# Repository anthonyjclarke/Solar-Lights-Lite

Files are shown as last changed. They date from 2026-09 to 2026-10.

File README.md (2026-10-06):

# Solar Lights Lite
















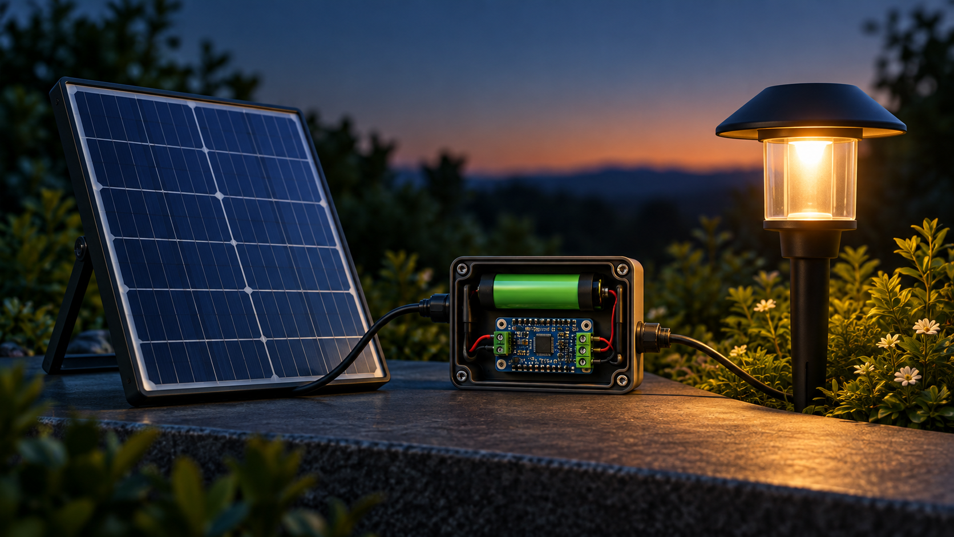
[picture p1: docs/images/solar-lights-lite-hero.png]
A solar panel, compact control electronics and warm garden light at dusk


Solar Lights Lite is a modular, low-power solar lighting system you build
yourself from common hobby modules. A small panel charges a protected Li-ion
battery; an ATmega328P controller sleeps most of the time, detects dusk with a
light sensor, and runs a **low-power LED string** from dusk to dawn. An
optional Wemos D1 Mini reports everything to Home Assistant.

It is also a learning project. Each module – power, controller, lighting,
sensor, telemetry – is built and tested on its own, so along the way you
practise soldering and SMD rework, read datasheets, program an AVR over ISP,
write low-power embedded C++, parse a serial protocol in ESPHome, and build
Home Assistant dashboards and automations.

---

## Low-power lights only

The controller drives the LED string **directly by PWM from pin D9** through a
47 Ω resistor. There is no driver transistor, so the whole string must run at
20 mA or less from a 3–4.2 V supply. Small low-power LED strings are ideal;
mains lights, 12 V garden lights and conventional or legacy fittings cannot be
used. The resistor sets the current and PWM sets the brightness. Brighter
lighting needs a driver stage: see [Going further](docs/12-going-further.md).

---

## System at a glance

```mermaid
flowchart LR
    PV[Solar panel] --> CHG[Protected Li-ion charger]
    CHG --> BAT[1S2P 18650 battery]
    CHG --> MCU[ATmega328P controller]
    MCU --> LDR[Light sensor]
    MCU -- PWM --> LED[Low-power LED string]
    MCU -. serial .-> D1[D1 Mini telemetry]
    D1 -. Wi-Fi .-> HA[Home Assistant]
```

| Module | What it does | Build guide |
| :----- | :--- | :--- |
| A | Panel, charger, fused 1S2P battery | [Power](docs/03-build-power.md) |
| B | ATmega328P controller at 8 MHz | [Controller](docs/04-build-controller.md) |
| C | Low-power LED string on D9 | [Lighting](docs/05-build-lighting.md) |
| D | Light sensor and test button | [Sensor](docs/06-build-sensor.md) |
| E | D1 Mini telemetry (optional) | [Telemetry](docs/07-build-telemetry.md) |
| F | Enclosure and final assembly | [Commissioning](docs/10-commissioning.md) |

### Telemetry tiers

| Tier | Name | Role |
| :--- | :--- | :--- |
| 0 | Standalone | Lights only, no Wi-Fi |
| 1 | Advanced Telemetry | Always-on commissioning instrument |
| 2 | Production Telemetry | Hourly battery-powered reporting |

**Advanced Telemetry is the road to a finished installation.** While you build,
calibrate and soak-test, it shows every decision the controller makes in Home
Assistant. When the system passes its acceptance gates, you reflash both boards
and move the D1 Mini to battery power for low-power production reporting. The
wiring stays the same.

---

## What you need

- The parts for each module: [parts, tools, skills and safety](docs/02-parts-and-tools.md)
  and the checklist [`docs/parts-list.csv`](docs/parts-list.csv).
- A soldering iron, a multimeter and a **current-limited bench supply**.
- A USBasp programmer (or a spare Arduino Uno/Nano as ISP).
- A computer with [PlatformIO](https://platformio.org/) and a standalone
  [avrdude](https://github.com/avrdudes/avrdude) 7.x.
- For telemetry: Home Assistant with ESPHome.

---

## Build path

The docs are organised by module; build in this order, passing each
commissioning gate before moving on:

1. Read the [design overview](docs/01-design-overview.md), including the
   known limitations.
2. Prepare the controller, set its fuses and flash the `advanced` firmware:
   [controller](docs/04-build-controller.md), [firmware](docs/08-firmware.md).
3. Add the [LED string](docs/05-build-lighting.md) and the
   [sensor and button](docs/06-build-sensor.md); pass Gates 1, 3 and 4 on a
   bench supply.
4. Build and qualify the [power module](docs/03-build-power.md): Gates 2, 5
   and 6.
5. Add [telemetry hardware](docs/07-build-telemetry.md) and set up
   [Home Assistant](docs/09-home-assistant.md) in Tier 1.
6. Assemble the enclosure and run the 14-day soak (Gate 7), then switch to
   production (Gate 8): [commissioning](docs/10-commissioning.md).
7. Live with it: [operation and maintenance](docs/11-operation.md).

For a visual review of everything on one page – every guide with its drawings
inline, plus the wire schedule and parts checklist – open
[`docs/ASSEMBLY.html`](docs/ASSEMBLY.html) in a browser (download or clone the
repository first; GitHub shows HTML as source). Printable A3 drawings for every
module are in
[`docs/drawings/SolarLights_Lite_Drawings.pdf`](docs/drawings/SolarLights_Lite_Drawings.pdf).

---

## Repository map

| Path | Contents |
| :--- | :--- |
| `docs/` | Guides 01–12 and the one-page `ASSEMBLY.html` |
| `docs/drawings/` | A3 sheets, pin map, USBasp and bench sheets |
| `docs/reference/` | Board photos, datasheet, LED characterisation |
| `firmware/controller/` | ATmega328P firmware and host tests |
| `firmware/esphome/` | D1 Mini profiles: Advanced and Production |
| `homeassistant/` | HA package and dashboards |
| `hardware/kicad/` | KiCad schematic of the complete system |
| `tools/` | Drawing and wiring-data generators |

---

## Status

Version 0.6.0 is a complete build and operate package. The reference system is
built and running with Advanced Telemetry. The remaining steps before 1.0
are: removing the regulator and power LED from the bench controller board
([guide 04, step 5](docs/04-build-controller.md#5-remove-them)), which is
deferred to the production build; the 14-day soak; charger and panel
qualification; and the Tier 2 switch-over (Gates 5–8). See [`CHANGELOG.md`](CHANGELOG.md).

This is a hobby design, not a certified product. Read the
[safety notes](docs/02-parts-and-tools.md#safety) and the
[known limitations](docs/01-design-overview.md#known-limitations) before
leaving it unattended outdoors.

---

## Why build it?

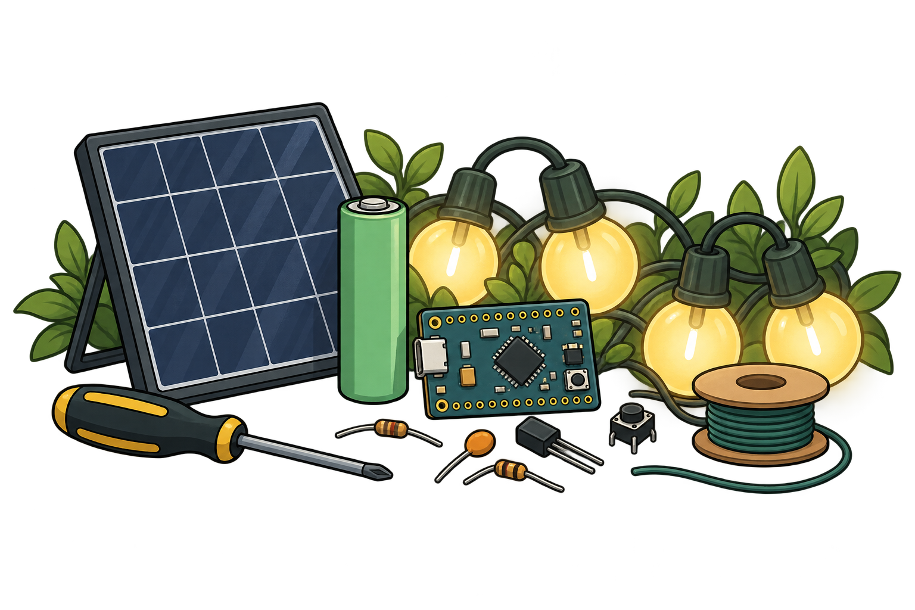
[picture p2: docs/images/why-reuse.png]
A solar panel, garden lights, battery cell, microcontroller and reused parts on a workbench.


This project started with a drawer of solar panels, light strings, charger
modules and microcontroller boards bought for projects that never quite
happened. Rather than buy another ready-made solar light, the aim was to put
those parts back to work, and to understand every part of the result: why a
charger needs its current set, why a microcontroller should run at 8 MHz on a
lithium cell, how little current a well-sleeping circuit can draw, and how to
watch it all from Home Assistant. AI assistants helped along the way as a
second opinion and a patient explainer.

Could it be cheaper, simpler, or less engineered? Almost certainly. But it is
a good excuse to learn, and good fun to build.

---

## Licence

Solar Lights Lite is dedicated to the public domain under
[CC0 1.0](LICENSE): firmware, ESPHome and Home Assistant configuration, tools,
documentation, drawings and schematics. Copy, modify, build and share it for
any purpose, without asking and without attribution.

The one exception is the third-party TPS63802 datasheet in `docs/reference/`,
which remains the property of its publisher and is included for reference.

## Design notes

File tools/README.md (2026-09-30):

# Tools

Generators for the drawings and wiring data in `docs/`. Edit the generator, then
regenerate; do not hand-edit the outputs.

| Script | Writes |
| :--- | :--- |
| `make_drawings.py` | Sheet SVGs and PNGs, A3 drawings PDF |
| `make_board_map.py` | `docs/drawings/BTE13-010A-pin-map.*` |
| `make_usbasp_sheet.py` | `docs/drawings/usbasp-wiring.*` |
| `make_bench_sheet.py`  | `docs/drawings/controller-bench-sheet.*` |
| `make_netlist.py` | `docs/netlist.json`, `docs/wire-schedule.csv` |
| `make_guide.py` | `docs/ASSEMBLY.html` from guides 01–12 |
| `make_layouts.py` | Breadboard and perfboard layout SVGs and PNGs |

`make_netlist.py` needs only the Python standard library and also checks the
wiring rules (for example that B- is never joined to OUT-). `make_layouts.py`
also needs only the standard library; it checks both layouts against
`docs/netlist.json` and writes PNGs when Inkscape is installed. `make_guide.py`
needs `markdown`; the drawing scripts need `reportlab` and `pypdfium2`. Run
`make_guide.py` last, after any drawing, CSV or guide change:

```bash
python3 -m venv .venv
.venv/bin/pip install reportlab pypdfium2 markdown
.venv/bin/python tools/make_drawings.py
.venv/bin/python tools/make_guide.py
```

The KiCad schematic has its own generator in `hardware/kicad/tools/`; see
[`hardware/kicad/README.md`](../hardware/kicad/README.md).

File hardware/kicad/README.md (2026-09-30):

# KiCad schematic

`SolarLights_Lite.kicad_sch` is the complete Solar Lights Lite circuit on one A3
sheet, drawn as six functional blocks:

1. Solar input, charger and cells
2. Battery rail (fuse and service switch)
3. LED output (direct PWM drive through R3)
4. Controller (Pro Mini)
5. Telemetry (Wemos D1 Mini and the Q2 serial receiver)
6. Telemetry 3.3 V supply (U3)

Blocks connect by net label: `VBAT`, `3V3_TEL`, `PWM`, `UART_TX`, `BTN`,
`LDR_PWR`, `LDR_SENSE`, `BATT_BUS`, `BATT-` and `D1_D6`. U0 is drawn for
Option B panels; with an Option A panel, wire PV1 straight to M1 IN. U3 OUT is
shown connected to the D1 Mini 3V3 pin, which is the Tier 2 arrangement; in
Tier 1 that link is open and the D1 Mini runs from USB.

This is a wiring schematic for module-level assembly on perfboard. It has no
footprints or layout and is not a fabrication package.

---

## Files

| File | Contents |
| :--- | :--- |
| `SolarLights_Lite.kicad_sch` | Editable schematic (KiCad 7 format or later) |
| `SolarLights_Lite.pdf` | A3 PDF export; no KiCad needed |
| `SolarLights_Lite_preview.png` | Raster preview |
| `SolarLights_Lite.kicad_sym` | Custom module symbols |
| `tools/gen_lite_sch.py` | Generator for the schematic |
| `tools/lite_parts.json` | Part and net data emitted by the generator |

---

## Checks and exports

With KiCad installed, `kicad-cli` (in the KiCad application folder, or on
`PATH` on Linux) exports and checks the sheet:

```bash
kicad-cli sch export pdf -o SolarLights_Lite.pdf SolarLights_Lite.kicad_sch
kicad-cli sch erc SolarLights_Lite.kicad_sch
```

ERC currently reports four items, none of them wiring faults: GND has no
`PWR_FLAG`; the `Q_NPN_BCE` symbol is not in KiCad 10's `Device` library; and
two `Battery_Cell` symbols differ from KiCad 10's library copies.

## Regenerating

The generator reads KiCad 7-format stock symbols (it uses `Q_NPN_BCE`, which
KiCad 10 no longer ships). Point `KICAD_LIBS` at a KiCad 7 symbol library
folder containing `Connector_Generic`, `Device`, `Switch` and `power`:

```bash
KICAD_LIBS=/path/to/kicad7-symbols python3 tools/gen_lite_sch.py
```

Then re-export the PDF and preview, and compare netlists before and after to
confirm connectivity.

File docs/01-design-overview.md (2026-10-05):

# 01 – Design overview

Solar Lights Lite is a small, modular solar lighting system. A solar panel
charges a protected lithium-ion battery. An ATmega328P controller wakes from
deep sleep every few seconds, decides whether it is dark, and drives a
low-power LED string from dusk to dawn. An optional Wemos D1 Mini reports what
the controller is doing to Home Assistant.

Every block is a separate module that you build, test and understand on its
own before joining it to the next. That makes the project a practical course in
microelectronics, soldering, low-power embedded code and home automation, as
well as a working set of garden lights.

---

## The modules

| Module | What it is | Build guide |
| :----- | :--- | :--- |
| A | Panel, charger, 1S2P battery  | [Power](03-build-power.md) |
| B | ATmega328P controller | [Controller](04-build-controller.md) |
| C | Low-power LED string on D9 | [Lighting](05-build-lighting.md) |
| D | Light sensor (LDR) and button | [Sensor](06-build-sensor.md) |
| E | D1 Mini telemetry (optional)  | [Telemetry](07-build-telemetry.md) |
| F | Enclosure and final assembly  | [Commissioning](10-commissioning.md) |

```mermaid
flowchart LR
    PV[Solar panel] --> OPT{Panel Voc}
    OPT -- Option A --> CHG[Protected 4056 charger]
    OPT -- Option B --> U0[5 V buck U0] --> CHG
    CHG --> BAT[1S2P Li-ion pack]
    CHG -- OUT+ via F2, S1 --> RAIL[VBAT_SYS rail]
    RAIL --> MCU[ATmega328P controller]
    MCU -- D7 / A1 --> LDR[Switched LDR]
    MCU -- D9 PWM + R3 --> LED[Low-power LED string]
    MCU -- D1/TX via Q2 --> D1[D1 Mini telemetry]
    RAIL -- U3 3.3 V --> D1
    D1 -. Wi-Fi .-> HA[Home Assistant]
```

The printable drawings in [`drawings/`](drawings/) show every module at
terminal level; sheet 7 is the whole system on one page.

---

## Low-power lighting only

The lights are a **low-power LED string**: the reference string drops about
2.56 V and draws roughly 10–20 mA in total. The controller drives it
**directly by PWM from pin D9** through a 47 Ω resistor (R3). There is no
MOSFET or transistor driver.

That has three consequences you should understand before choosing lights:

- **R3 and the pin set the current; PWM duty sets brightness.** Lowering the
  duty dims the string and saves energy, but it does not make an unsuitable
  string safe.
- **The ATmega328P pin is the limit.** Its working rating is 20 mA (40 mA
  absolute maximum). Mains lights, 12 V garden lights and conventional or
  legacy light fittings cannot be connected.
- **Brightness follows the battery.** With no regulator in the LED path,
  current falls as the cell discharges – about 21 mA at 4.20 V down to 11 mA
  at 3.40 V with the reference string. This is intended.

Brighter lighting is possible, but it needs a driver stage and a new energy
budget; see [12 – Going further](12-going-further.md).

---

## How the controller works

Each wake the controller:

1. Measures its own supply voltage against the internal 1.1 V bandgap.
2. Powers the LDR divider from D7 for a few milliseconds and reads A1.
3. Advances a small scheduler (`firmware/controller/include/schedule.h`).
4. Sets the D9 PWM duty and goes back to sleep.

| Situation | Behaviour |
| :--- | :--- |
| Day, lights off | Power-down sleep, wakes every 8 s |
| Dark for 300 s | Dusk confirmed, fades up at 2 % per s  |
| Night | Lights at `NIGHT_DUTY_PCT` (100 %) |
| Battery below 3.45 V | Night duty halved |
| Light for 300 s | Dawn confirmed, fades off |
| Below 3.30 V for 30 s | Cut-off: lights off, button locked out |
| Cut-off, then > 3.60 V, day | Normal operation resumes |
| D2 button pressed | 60 s test at the night level |
| Reset | 10 s self-test flash |

While the LEDs are lit, PWM needs the timer running, so the controller uses
idle sleep and wakes every second. The switched LDR draws current only while it
is being read.

---

## Telemetry tiers

The lights never depend on Wi-Fi or Home Assistant. Telemetry is a separate,
optional module used in three ways:

| Tier | Name | Purpose |
| :--- | :--- | :--- |
| 0 | Standalone | No telemetry; controller only |
| 1 | Advanced Telemetry | Always-on commissioning instrument |
| 2 | Production Telemetry | Hourly battery-powered reporting |

**Advanced Telemetry is the path to production.** While you build, calibrate
and soak-test, the D1 Mini stays awake on USB power and decodes every
diagnostic line from the controller into Home Assistant, with a dashboard built
for commissioning. When the system passes its acceptance gates you reflash both
boards and move the D1 Mini's supply from USB to the battery (U3). The wiring
does not change. See [09 – Home Assistant](09-home-assistant.md).

---

## Design decisions

- **ATmega328P at internal 8 MHz.** A 16 MHz ATmega328P is outside its rated
  operating area below about 3.8 V, which a discharging Li-ion cell reaches
  every night. At 8 MHz it is rated down to 2.7 V. The internal oscillator
  also removes any dependency on the board's crystal. The common 5 V/16 MHz
  Pro Mini is therefore fine to buy: its fuses are reset to internal 8 MHz
  ([04 – Controller](04-build-controller.md#why-the-controller-runs-at-8-mhz)).
- **No voltage regulator for the controller.** The Pro Mini runs straight from
  the protected battery rail (2.7–4.2 V is within its range), so its regulator
  and power LED are removed to eliminate their standby current.
- **Switched LDR for dusk and dawn.** Sensing panel voltage depends on charger
  loading and can back-feed an unpowered controller. A light-dependent
  resistor powered only while sampled needs no RTC, clock or network, and
  draws nothing between reads.
- **Five-minute confirmation and a threshold gap.** Car headlights, shadows
  and dusk flicker cannot toggle the lights.
- **Dusk to dawn, no clock.** Without an RTC the watchdog timer is the only
  time base, and it is uncalibrated (it varies by chip, typically 10–20 %
  slow). Dusk-to-dawn operation never needs wall-clock time.
- **Firmware cut-off plus hardware protection.** The firmware protects the
  battery from the lighting load; the charger module's DW01A protection
  remains the last line of defence for everything else.
- **Receive-only telemetry through a transistor.** Q2 inverts and level-shifts
  the controller's serial output for the 3.3 V D1 Mini, so the two boards never
  share a logic-level signal directly and the D1 Mini cannot drive the
  controller.
- **Scheduler separate from hardware.** `schedule.h` has no AVR code, so its
  behaviour is covered by host regression tests on any computer.
- **Reuse first.** Modules are chosen to be common and inexpensive, and parts
  already in a drawer are preferred where they qualify.

---

## Energy budget

These are planning figures, not measurements. Commissioning replaces them with
your own numbers ([10 – Commissioning](10-commissioning.md)). Assumptions: 14
dark hours, reference LED string at about 15 mA, Tier 2 telemetry.

| Load | 100 % duty | 50 % duty |
| :--- | ---: | ---: |
| LED string, 15 mA × 14 h | 210 mAh | 105 mAh |
| Controller, 1 mA lit + 10 µA for 10 h | 14 mAh | 14 mAh |
| Controller status line, ~40 µA × 24 h | 1 mAh | 1 mAh |
| D1 Mini wakes, 24 × 20 s × 80 mA | 11 mAh | 11 mAh |
| U3 and D1 Mini sleep, 0.2 mA × 24 h | 5 mAh | 5 mAh |
| Other standby allowance | 1 mAh | 1 mAh |
| **Total per day** | **~242 mAh** | **~137 mAh** |

On the harvest side, a TP4056-family linear charger set to 100 mA and an
assumed 2.5 equivalent full-sun hours with 20 % derating gives about
200 mAh/day; at 150 mA, about 300 mAh/day. Winter, shade and panel angle
change this dramatically. Two practical conclusions:

- Full brightness all night is marginal with a 1.2 W panel in winter. If the
  soak test shows the battery ending each night lower than the last, reduce
  `NIGHT_DUTY_PCT` or fit a larger panel.
- A bigger battery buys autonomy through cloudy spells; it cannot fix a
  persistent daily deficit.

---

## Known limitations

Read these before relying on the system unattended outdoors.

- **No cell-temperature charge inhibit.** TP4056-family modules usually have
  their TEMP input disabled. Li-ion cells must not be charged below 0 °C. In a
  climate where the enclosure can freeze, add temperature protection before
  unattended use (see [Going further](12-going-further.md)).
- **Not a power-path charger.** The load draws from the battery while it is
  charging, which can delay or confuse charge termination. Commissioning Gate 5
  checks termination with the load connected.
- **Firmware cut-off only switches the LEDs off.** The controller, U3 and the
  D1 Mini keep drawing a small current until the pack protection trips.
- **Battery percentage is an estimate** from resting voltage, not coulomb
  counting.
- **No wall-clock time.** The watchdog clock drifts; features that need real
  time (for example "off at 22:30") need an RTC or network time.
- **PWM at ~1.96 kHz** may band on some cameras.
- **A short on the LED cable is bounded, not protected.** R3 plus the pin's
  resistance limit it to roughly 55 mA, which is above the pin's absolute
  maximum. Fit R3 at the controller end so the outdoor cable is always behind
  it.
- **Telemetry reports controller state, not energy.** It does not measure
  panel voltage, charge or load current, or temperature.

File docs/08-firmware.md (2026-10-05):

# 08 – Controller firmware: build, fuses, flash and diagnostics

The controller firmware is in [`firmware/controller/`](../firmware/controller/).
It is built with PlatformIO and flashed over ISP with a standalone copy of
`avrdude`. The board has no bootloader, so there is no USB upload.

**What you will learn:** AVR fuses and ISP programming, PlatformIO build
environments, low-power AVR techniques (power-down sleep, watchdog wake,
pin-change interrupts, bandgap voltage measurement, hardware PWM), and testing
embedded logic on a desktop computer.

---

## Source layout

| File | Purpose |
| :--- | :--- |
| `include/config.h` | Every tuneable value: pins, levels, timing |
| `include/schedule.h` | Hardware-free dusk-to-dawn scheduler |
| `src/main.cpp` | AVR layer: ADC, PWM, sleep, telemetry |
| `test_host/regression.cpp` | Scheduler tests that run on a computer |
| `platformio.ini` | One build environment per telemetry tier |

---

## Build environments

| Environment  | Telemetry output | Use with |
| :--- | :--- | :--- |
| `advanced` | Banner, field guide, diagnostics | Tier 1, bench |
| `production` | Banner, then a compact line ~8 s | Tier 2 |
| `standalone` | None; serial port powered down | Tier 0 |

All three run identical lighting logic. Commission with `advanced`; deploy
with `production` (or `standalone` if you have no telemetry).

---

## Why ISP, not a USB-serial upload

An off-the-shelf Pro Mini is normally programmed through a USB-serial (FTDI)
adapter and the Arduino bootloader. This build uses an ISP programmer (USBasp,
or an Uno or Nano acting as one) instead, for these reasons.

**ISP is needed at least once anyway.** Switching the clock to the internal
8 MHz oscillator means rewriting the fuses
([why 8 MHz](04-build-controller.md#why-the-controller-runs-at-8-mhz)). A
bootloader cannot change fuses: only an ISP programmer (or a high-voltage
programmer) can. There is no way to prepare a new board with an FTDI adapter
alone.

**The factory bootloader stops working after the fuse change.** A 16 MHz Pro
Mini's bootloader is built for its 16 MHz crystal. Once the chip runs at
8 MHz, the bootloader runs at half speed and talks at the wrong baud rate, so
uploads fail. Serial uploads would need a new 8 MHz bootloader, and that also
has to be written over ISP.

**With the programmer already wired, ISP is the simpler route for updates.**
One tool and one command cover fuses, firmware and verification, and the chip
has nothing extra installed:

- **The firmware starts straight away.** With no bootloader there is no
  start-up pause listening for an upload after a reset.
- **The full 32 KB of flash is available,** and the high fuse `0xD9` jumps
  straight to the firmware at reset.
- **No auto-reset wiring is needed.** Serial uploads need the adapter's DTR
  line connected to RST through a 100 nF capacitor. This build has no DTR
  connection, and D1/TX is already used by the telemetry link (module E).
- **There is less risk of back-feeding the battery.** A USB-serial adapter's
  VCC pin must never be connected while the battery powers the controller.
  For flashing, the programmer is the only power source, with the battery and
  everything else disconnected.

**An FTDI adapter is still useful** as a receive-only serial monitor (see
[Reading the diagnostics](#reading-the-diagnostics)): connect controller TX to
adapter RX, and GND to GND, only.

**Serial uploads are possible, but not supported.** If you want to use them,
use ISP to write an 8 MHz internal-oscillator bootloader and the high fuse it
requires, then add the DTR reset circuit. The project's instructions,
troubleshooting and fuse values all assume no bootloader, so you would be on
your own.

---

## Install the tools

1. **PlatformIO.** Install the PlatformIO extension for VS Code, or PlatformIO
   Core ([installation guide](https://docs.platformio.org/en/latest/core/installation/)).
   Check `pio --version` in the PlatformIO terminal.
2. **avrdude, version 7 or later, installed separately.** PlatformIO bundles an
   older avrdude that is not reliable with this setup, so do not use
   `pio run -t upload`.
   - macOS: `brew install avrdude`
   - Linux: your distribution's `avrdude` package, if it is version 7 or later;
     otherwise build or download it from the
     [AVRDUDE project](https://github.com/avrdudes/avrdude/releases).
   - Windows: download the release from the
     [AVRDUDE project](https://github.com/avrdudes/avrdude/releases), extract
     the whole folder (including `avrdude.conf`) and add it to `PATH`. A USBasp
     also needs a libusb driver (for example installed with Zadig).
3. Check `avrdude --version` in the same terminal you will flash from.

---

## Wire the programmer

Disconnect the battery, panel, LED string, telemetry and any USB-UART adapter
first. The controller must have exactly one power source: the programmer.

| USBasp 10-pin | Signal | Pro Mini |
| :--- | :----- | :--- |
| 1 | MOSI | 11 |
| 2 | VCC | VCC |
| 5 | RESET  | RST |
| 7 | SCK | 13 |
| 9 | MISO | 12 |
| 4, 6, 8 or 10 | GND | GND |

Set the USBasp to **3.3 V** and confirm with a meter: some clones switch target
power but not logic level. Printable sheets: [USBasp wiring](drawings/usbasp-wiring.pdf)
and the [board map](drawings/BTE13-010A-pin-map.pdf).

---

## One-time preparation of a new board

Run these from any folder. None of them are needed again for routine updates.

**1. Read the signature** (writes nothing):

```bash
avrdude -c usbasp -p m328p -v
```

The signature tells you which chip is on the board, and that decides the
`-p` part name for **every** avrdude command that follows:

| Signature  | Chip | Use in every command  |
| :--- | :--- | :--- |
| `1E 95 0F` | ATmega328P  | `-p m328p` (as shown) |
| `1E 95 16` | ATmega328PB | `-p m328pb` |

Stop if it reads anything else, or all `00` or all `ff` (see
[Troubleshooting](#troubleshooting)).

Many recent Pro Mini clones, including some sold as "ATmega328P", carry the
newer **ATmega328PB**. With `-p m328p`, avrdude reports
`Device signature = 1E 95 16 (ATmega328PB)` and refuses to continue. This
does not mean the board is faulty. Repeat the command with `-p m328pb`, and
use that in every later command. Do not use `-F` to force past the check:
it switches off avrdude's check that it is talking to the chip you expect,
for this command and any you copy it into.

The 328PB is designed as a drop-in replacement for the 328P and runs the same
firmware. The PlatformIO build (board `pro8MHzatmega328`) is unchanged, and so
are the fuse values below. The 328PB's extra peripherals and its extra
clock-failure fuse bit stay unused: the extended fuse `0xFD` leaves that bit
unprogrammed, so the feature is off.

**2. Save the existing fuses**, in case you ever want the board back as it
was. A new 16 MHz Pro Mini normally reads low `0xFF`, high `0xDA`, extended
`0xFD`; write down what yours shows.

```bash
avrdude -c usbasp -p m328p -U lfuse:r:-:h -U hfuse:r:-:h -U efuse:r:-:h
```

**3. Write the Solar Lights fuses:**

```bash
avrdude -c usbasp -p m328p -U lfuse:w:0xE2:m -U hfuse:w:0xD9:m -U efuse:w:0xFD:m
```

| Fuse | Value  | Effect |
| :--- | :----- | :--- |
| Low | `0xE2` | Internal 8 MHz RC oscillator, no clock ÷8 |
| High | `0xD9` | Start at address 0 (no bootloader), ISP kept |
| Extended | `0xFD` | Brown-out reset at 2.7 V |

Fuses are persistent configuration bits, separate from the program. Type the
values carefully: a wrong clock-source value can leave the chip needing an
external clock or a high-voltage programmer to recover. Some avrdude versions
show the extended fuse as `0x05`; that is the same setting with the unused
bits hidden.

The first firmware flash erases the chip, which also removes any Arduino
bootloader. The board will no longer accept serial uploads; that is expected.

---

## Build and flash

From `firmware/controller`:

```bash
pio run -e advanced
```

The build must end in `SUCCESS` and produce `.pio/build/advanced/firmware.hex`.
Then flash it:

```bash
avrdude -c usbasp -p m328p -v -U flash:w:.pio/build/advanced/firmware.hex:i
```

(On an ATmega328PB, `-p m328pb`.) Success needs both the write and the verify to pass. Unplug the programmer and
remove all six ISP wires before reconnecting normal power. Next, do the first
power-up check ([04 – Controller, step 3](04-build-controller.md#3-first-power-up-check)).

For deployment, build and flash `production` (or `standalone`) the same way,
replacing `advanced` in both commands. Routine updates never write fuses.

### Arduino as ISP (fallback)

If you have no USBasp, an Uno or Nano can act as the programmer:

1. Upload the `ArduinoISP` example sketch to it.
2. Fit a 10 µF capacitor from its RESET to GND (stops it auto-resetting).
3. Wire programmer D11 → target 11, D12 → 12, D13 → 13, D10 → target RST,
   plus VCC and GND. A 5 V Uno drives 5 V logic, so power the target from the
   Uno's 5 V pin: that is within the ATmega328P's rating **only while the
   controller is isolated** from the battery rail, LDR, LED string and D1 Mini.
4. Replace `-c usbasp` with `-c stk500v1 -P <port> -b 19200` in every command,
   for example `-P /dev/ttyACM0`, `-P /dev/cu.usbmodem1101` or `-P COM5`. Do
   not add `-B`; the stock sketch ignores it.

---

## Reading the diagnostics

At every reset, the `advanced` and `production` builds print a banner with
the firmware version, the date and time it was built, the telemetry profile
and the clock setting. Check it after flashing: it confirms the board is
running the build you just made.

```text
==================================================
 Solar Lights Lite  -  dusk-to-dawn controller
 Firmware   v0.6.0   built 05-Oct-2026 13:26
 Telemetry  advanced: full diagnostics, 9600 baud
 Clock      internal 8 MHz, brown-out 2.7 V
==================================================
```

The `advanced` build then lists its active settings (LDR thresholds, battery
levels, night duty) and a field guide to the line keys, ending with
`Live diagnostics`. After that it prints a line whenever something changes,
every 10 s while a transition, test or cut-off is being timed, and every 60 s
otherwise. The `production` build prints a shorter line every 8 scheduler
seconds. None of the reset text starts with `fw=`, so the ESPHome profiles
ignore it. The build date comes from the compiler, so it changes every time
you build.

Two ways to read it:

- **Tier 1 Advanced Telemetry** (recommended): the D1 Mini decodes every line
  into Home Assistant ([09 – Home Assistant](09-home-assistant.md)).
- **A 3.3 V USB-UART adapter**: connect only controller TX → adapter RX and
  GND → adapter GND; leave the adapter's VCC, TX, DTR and CTS open (sheet 5).
  Then run `pio device monitor --baud 9600` from `firmware/controller`.

The one exception is the first power-up check straight after flashing
([04 – Controller, step 3](04-build-controller.md#3-first-power-up-check)).
There, the adapter's 3.3 V VCC powers the bare board through the serial
header, with the programmer and everything else disconnected. Never use the
adapter's 5 V setting, and never connect its VCC while any other source
powers the controller.

### Line format

Every line is space-separated `key=value` pairs starting with `fw=`. Both
ESPHome profiles parse these keys; if you rename one, update both YAML files.

| Key | Example | Meaning |
| :--- | :--- | :--- |
| `fw` | `0.6.0` | Firmware version (`config.h`) |
| `time` | `1234s` | Scheduler seconds since reset |
| `vdd` | `3.912V` | Controller supply (= battery rail) |
| `battery` | `OK` | Band: OK, MID, LOW, CRITICAL |
| `ldr` | `12.4%` | A1 as a percentage of VCC |
| `sense` | `DARK` | DARK, MID or LIGHT |
| `mode` | `NIGHT` | DAY, NIGHT or LVC (cut-off) |
| `night` | `YES` | Dusk confirmed, dawn not yet |
| `output` | `100%` | D9 PWM duty |
| `cause` | `DUSK_TO_DAWN` | Why the output has its value |
| `raw` | `127` | A1 ADC count (advanced only) |
| `ldr_v` | `0.485V` | A1 volts (advanced only) |
| `confirm` | `DUSK 40/300s` | Transition progress (advanced only) |
| `lvc` | `0/30s` | Time below cut-off (advanced only) |
| `button` | `59s` | Test time left (advanced only) |
| `next_tick` | `1s` | Next watchdog interval (advanced only) |

| `cause` | Meaning |
| :--- | :--- |
| `STARTUP_TEST` | 10 s flash after reset |
| `BUTTON_TEST` | 60 s test after a D2 press |
| `DAY_OFF` | Daylight, lights off |
| `FADE_TO_DAY_OFF` | Dawn confirmed, fading out |
| `DUSK_TO_DAWN` | Night, full night level |
| `LOW_BATT_NIGHT`  | Night, below 3.45 V: level halved  |
| `LOW_VOLT_BLOCK`  | Test refused: supply below cut-off |
| `LVC_OFF` | Low-voltage cut-off active |

---

## Tuning and calibration

All settings are in `include/config.h`. The ones you are most likely to change:

| Setting | Default | Effect |
| :--- | :--- | :--- |
| `NIGHT_DUTY_PCT`  | 100 | Night brightness and energy use |
| `LDR_DARK_RATIO`  | 0.30 | Dusk threshold (A1 fraction) |
| `LDR_LIGHT_RATIO` | 0.60 | Dawn threshold (A1 fraction) |
| `LOW_BATT_V` | 3.45 | Below this, night level halves |
| `LVC_OFF_V` | 3.30 | Cut-off voltage (after 30 s) |
| `LVC_RESUME_V` | 3.60 | Recovery voltage (in daylight) |
| `BANDGAP_V` | 1.10 | Supply measurement calibration |
| `TIME_SCALE` | 1 | Bench only: 60 runs time 60× faster |

**Calibrate the supply reading** once per board, in Gate 1: power the
controller from a bench supply at about 3.8 V, compare `vdd` with a meter, set
`BANDGAP_V = 1.10 × Vmeter / Vreported`, then rebuild and reflash. The
thresholds above all depend on this reading.

---

## Host tests

The scheduler has no hardware dependencies, so its behaviour is tested on any
computer with a C++17 compiler. From `firmware/controller/test_host`:

```bash
c++ -std=c++17 -Wall -Wextra -Werror -I../include regression.cpp -o regression && ./regression
```

It must print `PASS`. The tests cover dusk/dawn confirmation, a 14-hour night,
test-level caps, cut-off and recovery, low-battery dimming, slow ticks and the
shipped defaults. They do not test registers, ADC settling, sleep current or
wiring: that is what commissioning is for.

---

## Troubleshooting

| Symptom | Meaning / action |
| :--- | :--- |
| `pio: command not found` | Use the PlatformIO terminal |
| `Bad CPU type` on an Apple-silicon Mac | AVR toolchain needs Rosetta 2 |
| avrdude path contains `.platformio` | Wrong avrdude: use the standalone one |
| `cannot set sck period` | Old USBasp firmware: fit slow-SCK jumper |
| `target does not answer` | Pin 1, MOSI/MISO, RST, VCC, slow SCK |
| Signature `1E 95 16 (ATmega328PB)` | 328PB chip: use `-p m328pb`, not `-F` |
| Any other signature | Wrong chip or wiring: stop |
| `vdd=` about 5 V on the bench | Fed from a 5 V pin or jumper: use 3.3 V  |
| Verification mismatch | Check avrdude version, retry once |
| Serial text unreadable | Fuses not set (still 16 MHz) |
| No serial output at all | `standalone` build, or TX/GND wiring |

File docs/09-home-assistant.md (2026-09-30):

# 09 – Home Assistant and ESPHome telemetry

**Files:** [`firmware/esphome/`](../firmware/esphome/) (D1 Mini profiles) and
[`homeassistant/`](../homeassistant/) (package and dashboards).
**Hardware:** [07 – Module E: telemetry hardware](07-build-telemetry.md).

The lights run without any of this. Telemetry lets you watch the controller
work, calibrate it, prove it over a two-week soak, and then keep an eye on it in
service.

**What you will learn:** ESPHome configuration and secrets, parsing a serial
protocol in an ESPHome lambda, deep sleep with an OTA escape hatch, Home
Assistant packages, helpers, automations and sections dashboards.

---

## The tiers

| Tier | Controller build | ESPHome profile | D1 Mini power |
| :--- | :--- | :--- | :--- |
| 0 | `standalone` | None | – |
| 1 | `advanced` | `solar-lights-advanced-telemetry.yaml` | Micro-USB |
| 2 | `production` | `solar-lights-production-telemetry.yaml` | U3 (battery)  |

**Tier 1 – Advanced Telemetry** is the commissioning instrument. The D1 Mini
stays awake and publishes every field of every diagnostic line, plus its own
Wi-Fi, heap and uptime. It keeps receiving if Wi-Fi or Home Assistant go down,
and serves its own web page at `http://<D1 IP address>/`. It draws around
70–80 mA continuously, which is why it runs from USB and is never part of the
battery budget.

**Tier 2 – Production Telemetry** is for the finished installation. Once an hour
the D1 Mini wakes, waits up to 20 s for a status line from the controller,
reads the battery voltage, reports, and goes back to deep sleep. Its average
draw is well under 1 mA.

Both profiles use the **same device name (`solar-lights`), entity names and
encryption key**, so moving from Tier 1 to Tier 2 keeps your Home Assistant
history and the same entity IDs.

---

## 1. Install ESPHome

Use either the **ESPHome Device Builder** add-on in Home Assistant
(Settings → Add-ons) or the ESPHome command-line tool. The profiles need
ESPHome 2024.11 or later.

## 2. Add the secrets

In the ESPHome `secrets.yaml` (never in this repository):

| Key | Used for |
| :--- | :--- |
| `wifi_ssid` | Your Wi-Fi network |
| `wifi_password` | Your Wi-Fi password |
| `esphome_encryption_key` | API key (ESPHome can generate one) |
| `ota_password` | Over-the-air update password |
| `ap_password` | Tier 1 fallback hotspot (8+ characters) |

## 3. Flash the D1 Mini (Tier 1)

1. Remove the D0 → RST link while flashing over USB.
2. In the ESPHome dashboard create a device, then replace its YAML with
   `solar-lights-advanced-telemetry.yaml`. Keep `name: solar-lights`: the
   dashboards' entity IDs depend on it.
3. **Validate**, then **Install** over USB the first time. Later updates can go
   over Wi-Fi.
4. Adopt the device in Home Assistant (Settings → Devices & services).
5. Flash the controller with the `advanced` build
   ([08 – Firmware](08-firmware.md)).

Within about a minute, **Arduino Diagnostics Fresh** turns on and
**Arduino Diagnostic Line** shows a complete line starting `fw=`.

## 4. Install the Home Assistant package

[`homeassistant/solar_lights_package.yaml`](../homeassistant/solar_lights_package.yaml)
adds:

- `input_boolean.solar_lights_ota`, the helper Tier 2 uses to stay awake for
  updates;
- three example automations: battery low, low-voltage cut-off, and reports
  stopped. They use persistent notifications, so they work without a phone
  app.

Enable packages once in `configuration.yaml`:

```yaml
homeassistant:
  packages: !include_dir_named packages
```

Copy the file to `/config/packages/`, check the configuration
(Developer tools → YAML) and restart Home Assistant.

## 5. Import a dashboard

Create a dashboard (Settings → Dashboards → Add dashboard), open it, choose
**Edit dashboard → Raw configuration editor**, and paste one of:

| Dashboard | Use |
| :--- | :--- |
| `dashboard-advanced-telemetry.yaml` | Tier 1: commissioning and soak test |
| `dashboard-production-telemetry.yaml` | Tier 2: day-to-day and 7-day trends |

Both use built-in cards only. If Home Assistant assigned different entity IDs,
find-and-replace `solar_lights_` before saving.

---

## Moving from Tier 1 to Tier 2

Do this only after the soak test (Gate 7) has passed.

1. Flash the controller with the `production` build.
2. With the D1 Mini still on USB, install
   `solar-lights-production-telemetry.yaml` over Wi-Fi.
3. Unplug USB. Close the U3 OUT → 3V3 jumper. Fit the D0 → RST link.
4. Watch for the first hourly report; then complete Gate 8.

To go back to Tier 1 (for example to recalibrate), reverse the steps: open the
U3 jumper **before** plugging in USB.

### Updating a sleeping D1 Mini (Tier 2)

Turn on **Solar Lights stay awake for OTA** (`input_boolean.solar_lights_ota`).
At its next wake the D1 Mini stays awake; install the update, then turn the
helper off and it resumes its hourly sleep. To reach it sooner, press its reset
button.

---

## Entities

| Entity (name in ESPHome) | Tier 1 | Tier 2 | Notes |
| :--- | :----: | :----: | :--- |
| Battery Voltage / Battery Level | ✓ | ✓ | D1 Mini A0, calibrated |
| Arduino VDD | ✓ | ✓ | Controller's own reading |
| Arduino Mode / Night / Output Cause | ✓ | ✓ | Scheduler state |
| Arduino Light Duty / Lights Commanded | ✓ | ✓ | D9 PWM duty |
| Arduino LDR / Light Sense | ✓ | ✓ | Light sensor |
| Arduino Battery Band / Firmware | ✓ | ✓ | |
| Arduino Diagnostic Line | ✓ | ✓ | Latest raw line |
| Arduino Diagnostics Fresh | ✓ | ✓ | Tier 2: line this wake |
| Arduino LDR Raw / LDR Voltage | ✓ | | Advanced detail |
| Arduino Transition Confirmation | ✓ | | Dusk/dawn progress |
| Arduino LVC Elapsed / Button Test | ✓ | | Timers |
| D1 WiFi Signal | ✓ | ✓ | |
| D1 Status, IP, SSID, uptime, heap | ✓ | | Receiver health |

Telemetry reports what the controller measures and decides. It does not
measure panel voltage, charge or load current, energy or temperature; use a
meter or power profiler for those.

---

## Calibrating the battery reading

In Gate 7, compare **Battery Voltage** with a meter across VBAT_SYS and GND at a
few battery levels. Set the multiplier in both profiles:

```
new multiplier = old multiplier × meter volts / reported volts
```

The nominal value is 5.4 (R5 220 kΩ plus the D1 Mini's 220 kΩ/100 kΩ divider);
the reference build calibrated to 5.21. **Arduino VDD** is a useful
cross-check, since it measures the same rail independently.

---

## Troubleshooting

| Symptom | Check |
| :--- | :--- |
| Diagnostics Fresh stays off | Controller build, Q2 wiring, grounds |
| `Dropped corrupted UART line` warnings | Q2 pin order, shared GND_LOAD |
| Home Assistant asks for the key again  | Encryption key changed between profiles |
| Tier 2 device never reports | D0 → RST link, U3 jumper, Wi-Fi reach |
| Tier 2 stays awake | OTA helper still on |
| Entities `unavailable` in Tier 1 | D1 Mini USB power or Wi-Fi |

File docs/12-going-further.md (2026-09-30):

# 12 – Going further

Solar Lights Lite is deliberately small. These are the natural next steps,
each a project in its own right. None of them is needed for the design as
documented, and each changes the energy budget and the commissioning work.

---

## Brighter lights: add a driver stage

The controller pin can supply about 20 mA. For a brighter string, D9 must drive
a switch that carries the LED current:

- **Logic-level MOSFET** with its on-resistance *specified at 2.5 V gate
  drive* (for example AO3400A on a breakout). "Logic level" on its own is not
  enough: at 3.0–3.3 V many such parts, including the 2N7000, are only partly
  on at LED currents.
- **NPN transistor** such as a BC337, with a base resistor sized for forced
  saturation (base current about a tenth of collector current).

A driver stage also needs a gate or base resistor, a pull-down so the lights
stay off at reset, a current-limiting resistor per LED branch, and a fuse in
the LED branch, because the string is then fed from the battery rail rather
than through the pin. Re-run the energy budget: a 200 mA string for 14 hours
needs 2,800 mAh a night, far beyond a 1–2 W panel.

---

## Better charging

- **Cell-temperature protection.** Add a thermistor on the cells and a
  charger (or cut-off circuit) that stops charging below 0 °C and above about
  45 °C. This is the main requirement for unattended use in cold climates.
- **Power-path charging.** Chargers such as the TI BQ24074 or Microchip
  MCP73871 supply the load and charge the battery separately, and regulate the
  input to suit a solar panel. They are not pin-compatible with TP4056 modules
  and come in small packages, so they suit a custom PCB.

## Measuring energy

The telemetry reports controller state, not energy. An INA219 or INA226
current monitor on the battery lead (read by the D1 Mini over I²C) would add
charge current, load current and daily mAh in and out – turning the soak test
into a true energy balance.

## Time-based schedules

The dusk-to-dawn design deliberately avoids clocks. An "evening and pre-dawn
only" schedule would need real time: a DS3231 RTC on the controller, or a time
sync from the D1 Mini. Watch the added standby current.

## A carrier PCB

Once your modules are fixed, a two-layer carrier board can replace perfboard:
sockets for the Pro Mini and D1 Mini, screw terminals, fuse holders, labelled
rails, test points and footprints for the Q2 interface. Keep the ESP8266
antenna at the board edge, and keep LED return current away from the LDR and
ADC ground. The KiCad schematic in [`hardware/kicad/`](../hardware/kicad/) is
the starting point; it needs footprints and a layout.

## Lower-power telemetry

An ESP32-C3 or similar module has a much lower deep-sleep current than an
ESP8266 D1 Mini and can run directly from a 3.3 V buck-boost. The serial
protocol and Home Assistant side would stay the same.

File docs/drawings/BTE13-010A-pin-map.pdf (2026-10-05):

SOLAR LIGHTS LITE / REFERENCE BOARD

# BTE13-010A: connection and programming map

Component side: serial header LEFT, crystal and reset button RIGHT (photos in docs/reference/).

Read the actual silkscreen before soldering. Diagram is not a footprint or regulator-removal template.

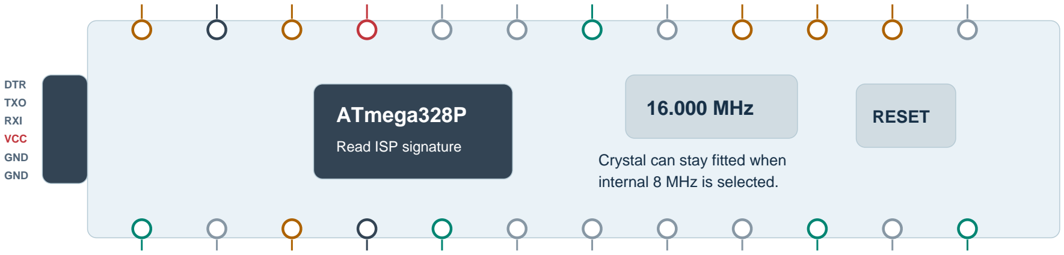
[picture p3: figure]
DTR TXO RXI VCC GND GND; ATmega328P; Read ISP signature; 16.000 MHz; Crystal can stay fitted when internal 8 MHz is selected.; RESET

### Serial header

Not the ISP connector
Its VCC = top-row VCC (same rail)
RAW | GND | RST | VCC | A3 | A2 | A1 | A0 | 13 | 12 | 11 | 10
TX | RX | RST | GND | 2 | 3 | 4 | 5 | 6 | 7 | 8 | 9

### OPERATING CONNECTIONS

Power goes into VCC (top row or header); RAW = never
VCC = protected battery; GND = OUT-; A1 = LDR sense; 7 = LDR power 9 = LED PWM; TX = telemetry to Q2; 2 = test button to GND
Regulator / power LED removed only after trace identification.

ISP CONNECTIONS / BOARD DISCONNECTED FROM BUILD

MOSI -> 11 MISO -> 12 SCK -> 13 RESET -> RST
Also connect target VCC and GND; use compatible voltage.
Set fuses once: L 0xE2, H 0xD9, E 0xFD (8 MHz internal).
A USB-to-serial adapter alone cannot perform this conversion.

REV 0.6 / BTE13-010A reference board. Other Pro Mini clones differ: follow your own silkscreen. A4-A7 end pads not shown.

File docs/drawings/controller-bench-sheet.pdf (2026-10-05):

SOLAR LIGHTS LITE / PRINTABLE SHEET

# Controller bench sheet

Flash the advanced build, prove the controller, then measure the LED string. Gate 1 of docs/10-commissioning.md.

Before you start
No cells connected for any of this. Use a current-limited bench supply, 200 mA limit, for VCC.
Step 2 needs the regulator and power LED removed (Gate 0) and the bench supply as the only power source.
Do not connect the panel or the charger. R3 sits at the board end, not out at the string.
Duty does not limit current: only R3 and the pin do. Verify at 4.20 V and 100% duty.

### 1 Flash the advanced build

Fuses are set once per board (internal 8 MHz, BOD 2.7 V, no bootloader). Routine flashing never writes them. Disconnect cells, panel, UART and LED string. Power from one verified target-compatible ISP source only.
Action | Command / pass result
Open firmware folder | cd firmware/controller
Check the target | avrdude -c usbasp -p m328p -v -> signature 1E 95 0F
1E 95 16 = ATmega328PB: use -p m328pb, never -F
Compile advanced build | pio run -e advanced -> SUCCESS
Upload and verify | standalone current avrdude; never pio -t upload
First power-up check | USB-UART at 3.3 V into serial-header VCC -> banner; vdd within 0.05 V of meter
Disconnect all ISP wires first. Then remove the regulator and power LED (guide 04 step 5) and repeat the check. After that, USB-UART is monitoring-only: target TX -> adapter RX, GND -> GND; adapter VCC, TX, DTR, CTS open. Tool setup, fuses, Arduino-as-ISP fallback and troubleshooting: docs/08-firmware.md

### 2 Check the controller on a current-limited bench supply

Read the diagnostics through Tier 1 telemetry or a USB-UART adapter (RX and GND only) at 9600 baud.
Check | | | Expect
Startup after reset | Banner with version and build date, field guide, then diagnostics
VCC at 3.80 V | vdd within 0.05 V of the meter (config.h BANDGAP_V = 1.10 x Vmeter / Vreported)
D9 PWM frequency | 1.9 to 2.0 kHz, confirming the 8 MHz clock
Pull D2 to GND | cause=BUTTON_TEST, output=100%, button timer counts down
Cover / uncover LDR | DUSK / DAWN confirmation reaches 300 s before mode changes

### 3 LED string current with R3 = 47 ohm

Meter in series with the string positive, lights at 100% duty (press D2 or cover the LDR). Expect = model:
Supply | Expect | Measured | R3 temp | Notes
3.40 V | 11 mA | __________ | ________ | ________________________
3.70 V | 15 mA | __________ | ________ | ________________________
4.20 V | 21 mA | __________ | ________ | ________________________

Decision rule
Over 22 mA at 4.20 V: fit 56 ohm and repeat the three readings (expect about 18 / 13 / 9 mA). Too bright or want longer run time: lower NIGHT_DUTY_PCT in config.h. Too dim: this design is at its limit; a brighter string needs a driver stage (docs/12-going-further.md).

Also confirm: R3 and the D9 pin stay at ambient; the string is dark with M2 unplugged and during reset. For deployment, build pio run -e production (or standalone) and flash its .hex the same way.

REV 0.6 | NO CELLS, PANEL OR CHARGER CONNECTED FOR THESE STEPS | make_bench_sheet.py

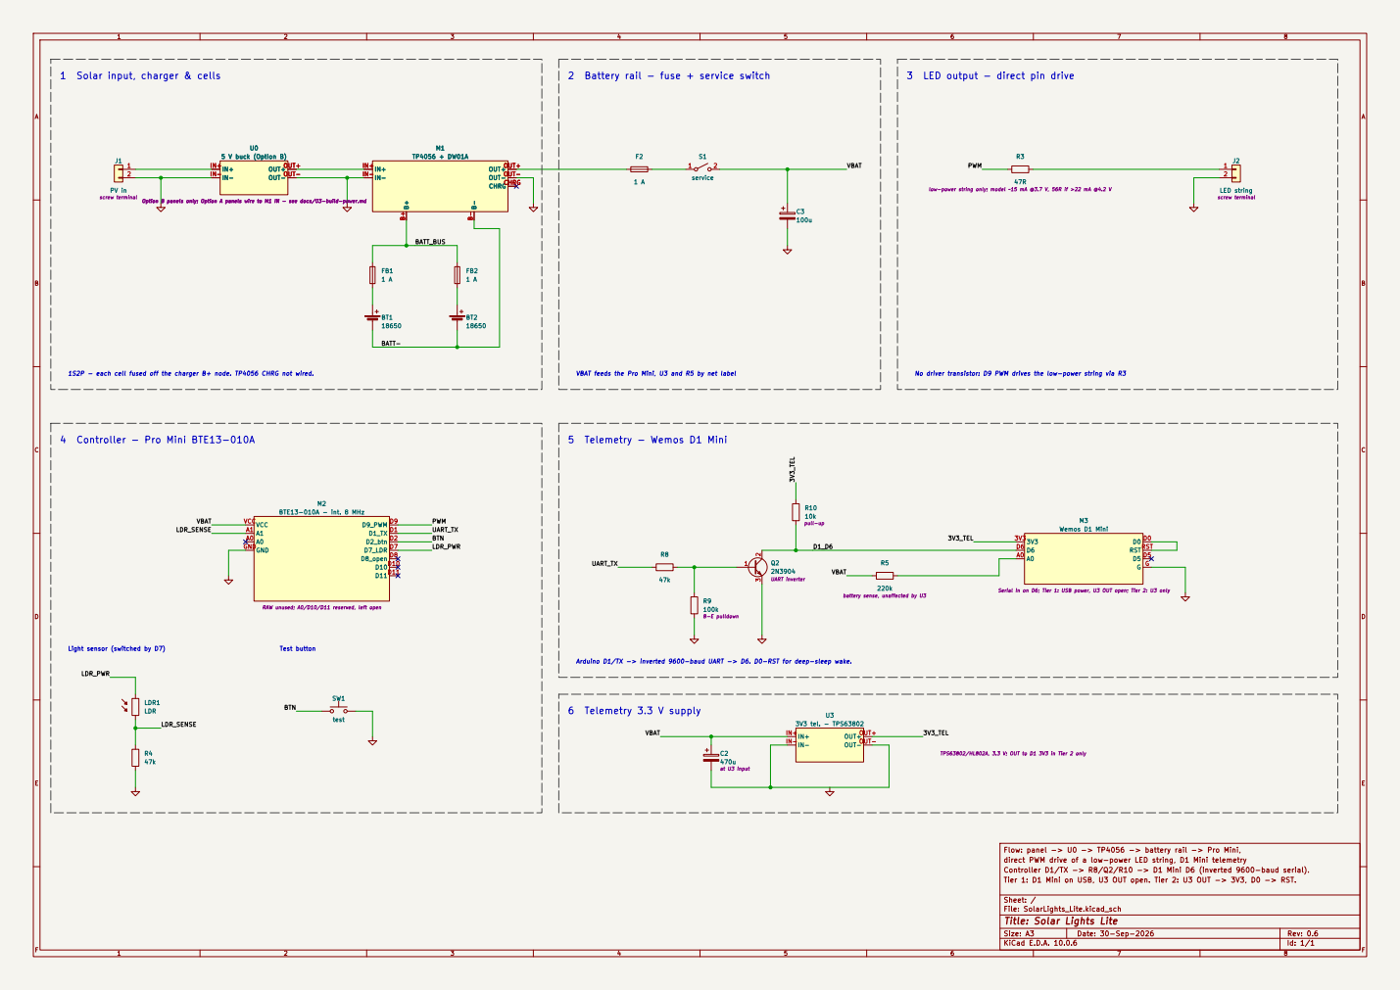
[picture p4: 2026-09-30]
hardware/kicad/SolarLights_Lite_preview.png

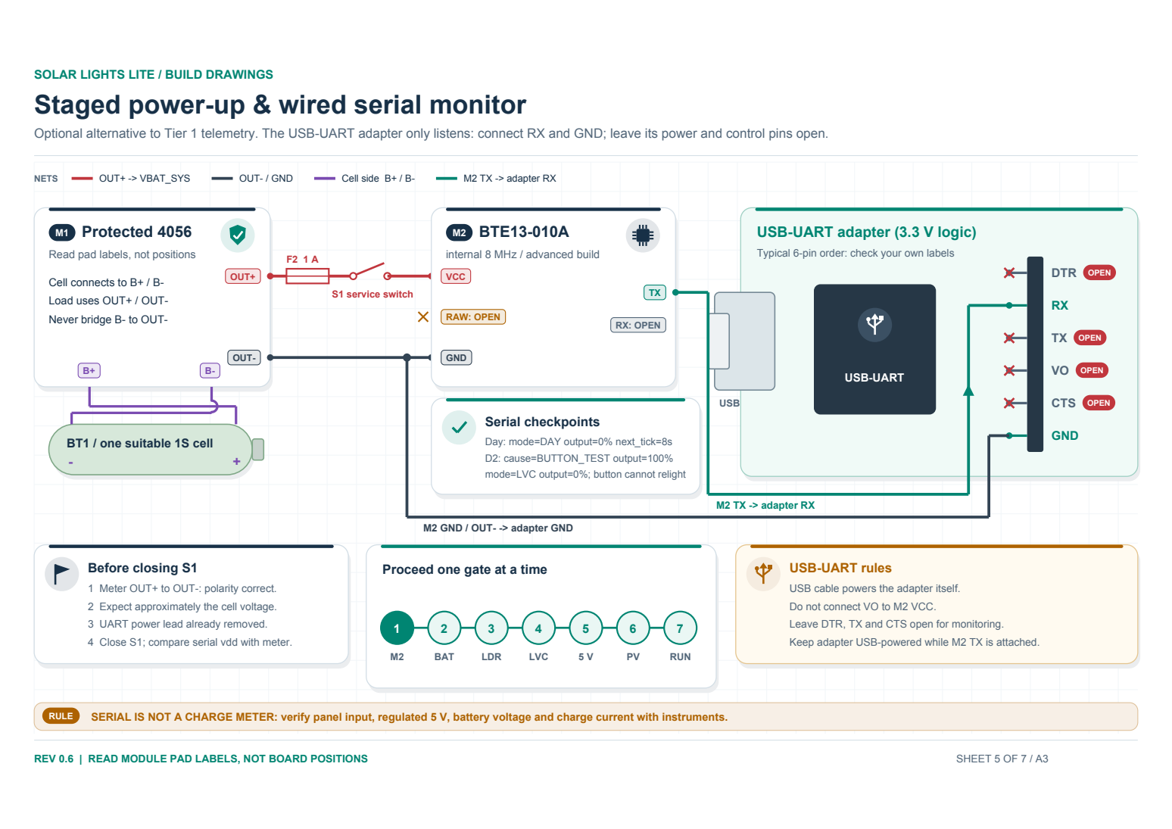
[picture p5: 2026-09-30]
docs/drawings/sheet-5.png

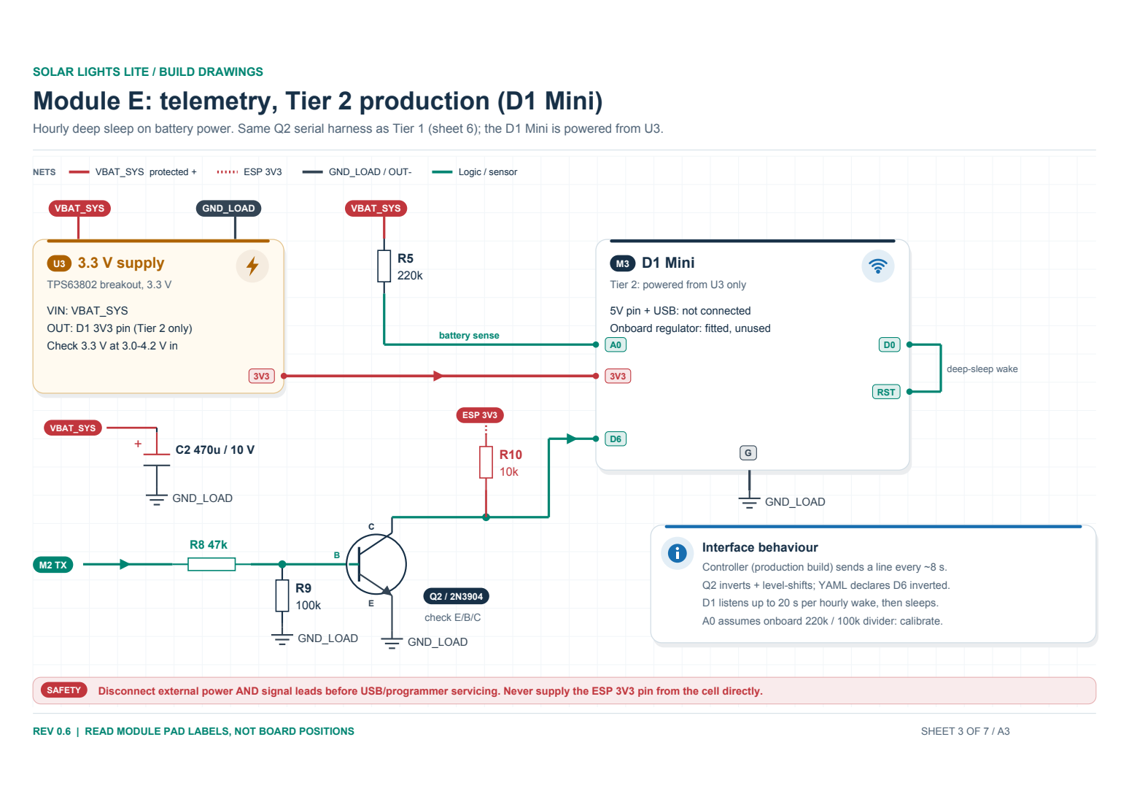
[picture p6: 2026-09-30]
docs/drawings/sheet-3.png

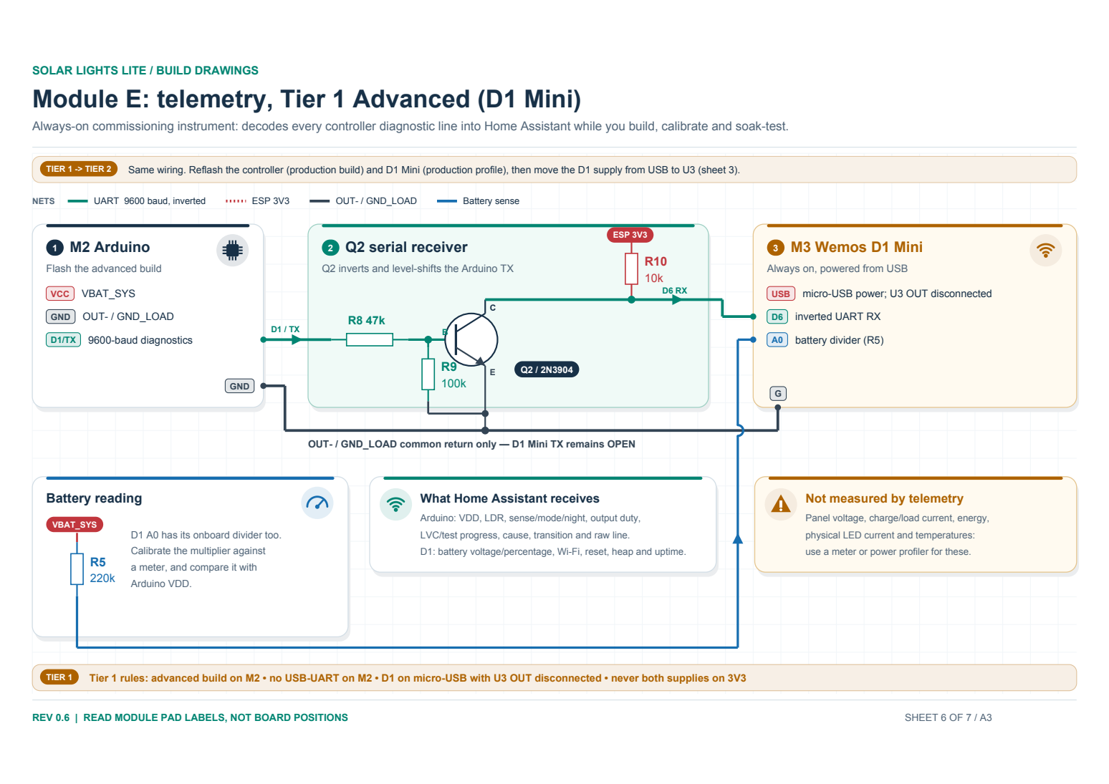
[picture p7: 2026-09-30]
docs/drawings/sheet-6.png

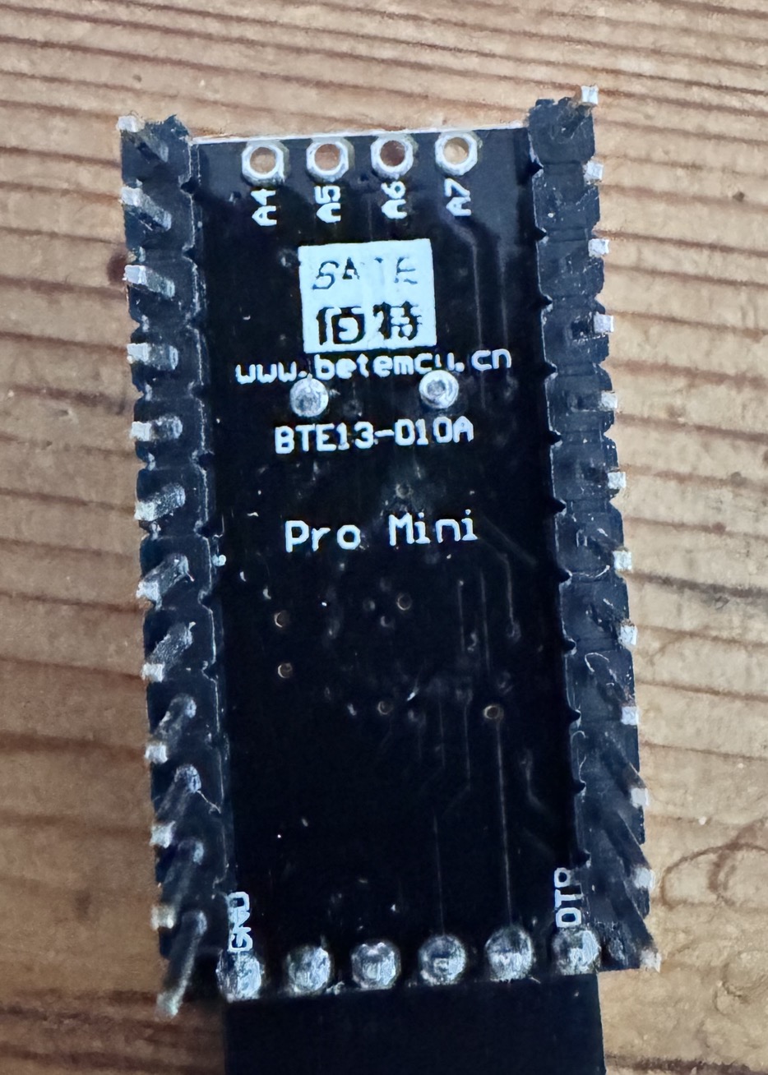
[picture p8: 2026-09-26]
docs/reference/BTE13-010A-back.jpeg

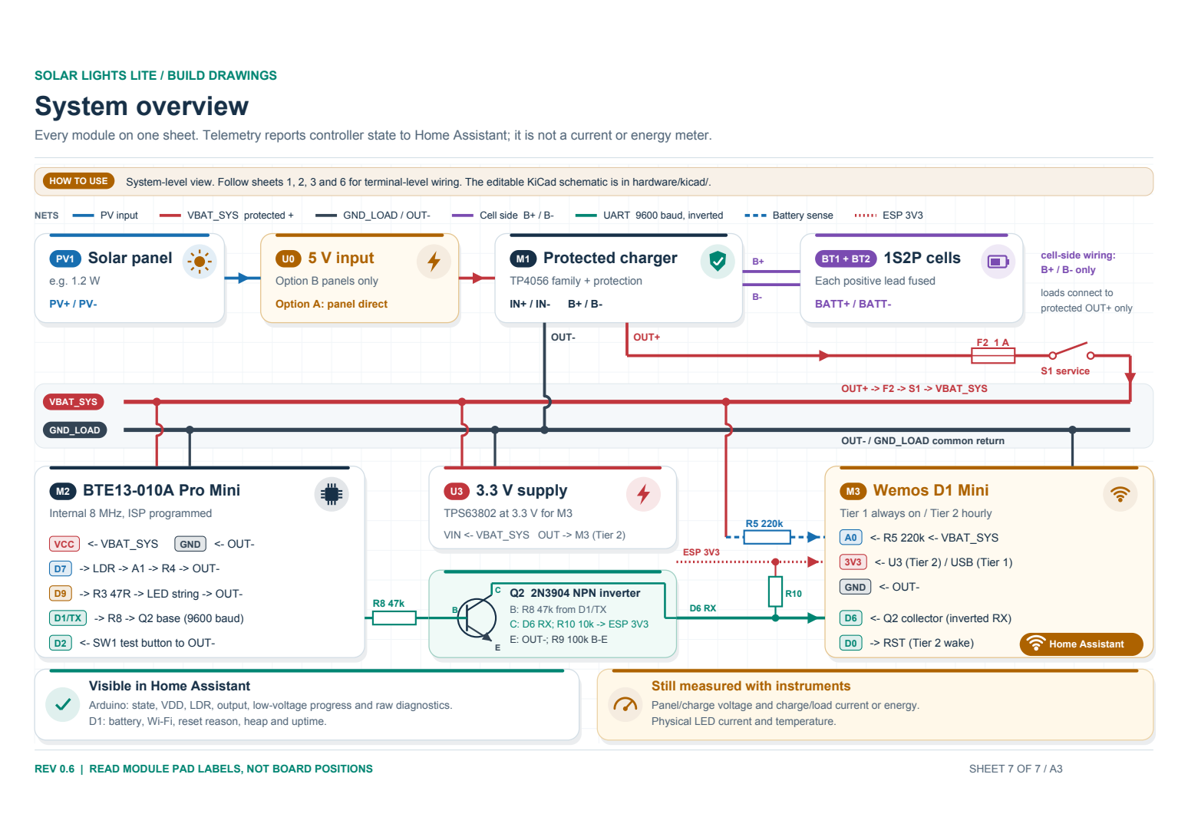
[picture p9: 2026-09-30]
docs/drawings/sheet-7.png

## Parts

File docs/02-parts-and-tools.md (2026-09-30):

# 02 – Parts, tools, skills and safety

Everything here is a common hobby module or through-hole part. A printable
checklist version of the parts list, with a "have it?" column, is in
[`parts-list.csv`](parts-list.csv). Reference designators match the drawings,
the wire schedule and the KiCad schematic.

---

## Parts by module

### Module A – power, charging and battery

| Ref | Part | Notes |
| :--- | :--- | :--- |
| PV1 | Solar panel, ~1–2 W | Reference: AS102-0712A 1.2 W |
| U0 | 5 V buck module, e.g. MP1584EN | Option B panels only (Voc > 6.5 V) |
| M1 | Protected TP4056-family module | Six pads: IN, B, OUT (± each) |
| BT1/BT2 | Matched 18650 Li-ion cells × 2 | 1S2P, in an insulated holder |
| FB1/FB2 | 1 A fuse + holder × 2 | One per cell positive lead |
| F2 | 1 A fuse + holder | After M1 OUT+ |
| S1 | SPST service switch | Breaks the whole protected rail |

### Module B – controller

| Ref | Part | Notes |
| :-- | :--- | :--- |
| M2  | ATmega328P Pro Mini-class board | Reference: BTE13-010A clone |
| C3  | 100 µF electrolytic, 10 V | Across VCC/GND at the controller |
| C4  | 100 nF ceramic | Across VCC/GND at the controller |

### Module C – lighting

| Ref  | Part | Notes |
| :--- | :--- | :--- |
| R3 | 47 Ω, ¼ W | At the controller end; 56 Ω option |
| JLED | Low-power LED string | ~2.5–3 V forward, ≤ 20 mA total |
| – | 2-way screw terminal or connector | Outdoor cable to the string |

### Module D – light sensor and button

| Ref  | Part | Notes |
| :--- | :--- | :--- |
| LDR1 | Light-dependent resistor  | Typical 5–10 kΩ (light) type |
| R4 | 47 kΩ | LDR divider lower resistor |
| SW1  | Momentary push button, NO | D2 to ground; test button |

### Module E – telemetry (optional)

| Ref | Part | Notes |
| :-- | :--- | :--- |
| M3  | Wemos D1 Mini (ESP8266) | Any common clone |
| U3  | TPS63802 buck-boost, 3.3 V  | e.g. HL802A breakout, 3.3 V jumper |
| C2  | 470 µF electrolytic, 10 V | At U3 input |
| Q2  | 2N3904 NPN (or BC547–BC550) | Serial inverter; check E-B-C order |
| R8  | 47 kΩ | Controller TX to Q2 base |
| R9  | 100 kΩ | Q2 base to emitter |
| R10 | 10 kΩ | Q2 collector pull-up to 3V3 |
| R5  | 220 kΩ | Battery sense to D1 Mini A0 |

### Module F – enclosure and assembly

| Item | Notes |
| :--- | :--- |
| Weatherproof box (IP65 or so) | Shaded position, room to service |
| Cable glands × 3 | Panel, LED string, LDR |
| Perfboard / stripboard carrier  | Sockets for M1, M2, M3, U3 |
| Female headers, screw terminals | Modules must stay replaceable |
| Standoffs, cable ties, labels | Label every connector (sheet 4) |
| Clear window or light pipe | So the LDR sees the sky, not the LEDs |

---

## Parts to avoid

- **AMS1117 or other linear regulators for U0.** A linear regulator turns the
  difference between panel and 5 V into heat – about 30 % of a 1.2 W panel's
  output – and drops out of regulation in weak light.
- **TPS63802 for U0.** Its 5.5 V input limit is below a typical panel's
  open-circuit voltage.
- **A second board that is not an ATmega328P** (for example a Pro Micro with an
  ATmega32U4). The firmware uses 328P-specific registers, interrupts and ADC
  channels; it is not a drop-in replacement.
- **Unknown or unmatched cells in parallel.** See Safety below.

---

## Tools

| Tool | Used for |
| :--- | :--- |
| Temperature-controlled iron | All soldering |
| Flux, braid or hot air | Removing the Pro Mini regulator/LED |
| Multimeter | Every test gate |
| Current-limited bench supply | Controller tests without a battery  |
| USBasp programmer (or an Uno/Nano) | ISP flashing and one-time fuses |
| Computer with PlatformIO, avrdude  | Building and flashing firmware |
| Home Assistant + ESPHome | Telemetry tiers 1 and 2 |
| USB-UART adapter, 3.3 V (optional) | Wired serial monitor alternative |
| Power profiler (optional) | Sleep and LED current measurements  |

A current-limited bench supply is the single most useful tool here: it lets you
test the controller and the LED string across the whole battery range, and
simulate a flat battery, without risking a lithium cell.

---

## What you will learn

| Area | Skills |
| :--- | :--- |
| Soldering | Through-hole, SMD rework, perfboard layout |
| Electronics | Dividers, LED current, transistor inverters  |
| Power | Li-ion charging, protection, fusing, budgets |
| Microcontrollers | Fuses, ISP, sleep modes, watchdog, ADC, PWM  |
| Firmware | C++ on AVR, host unit tests, build profiles  |
| ESPHome | UART parsing, deep sleep, OTA, secrets |
| Home Assistant | Dashboards, packages, helpers, automations |
| Test discipline  | Staged power-up and acceptance gates |

---

## Safety

Lithium-ion cells store a lot of energy. Treat every step that involves them
with care.

- **Never connect cells in series to a 1S charger**, and never bridge the
  module's B- to OUT-: that bypasses the protection circuit.
- **Only parallel matched cells**: same type, age, capacity and state of
  charge. Voltage equality alone does not prove two cells are safe to join.
  If in doubt, use a purpose-made protected 1S2P pack.
- **Fuse each cell** before the parallel junction (FB1/FB2). A single fuse
  after the junction cannot stop one cell feeding a fault in the other.
- **Do not solder to bare cell cans.** Use holders or pre-tabbed cells.
- **Do not short the pack to test protection.** Use a current-limited supply
  or an electronic load.
- **Never charge below 0 °C** and keep cells shaded and away from the charger
  and resistors. The charger module does not measure cell temperature.
- **Supervise charging** until Gate 5 and Gate 6 of
  [10 – Commissioning](10-commissioning.md) have passed.

### A note on reclaimed cells

Reclaimed cells, such as those from disposable vapes, can be usable, but their
history, condition, chemistry and suitability are unknown. They have worked
well with TP4056-family chargers in this project, but that is experience, not a
safety guarantee or a recommendation. Inspect and test cells properly, do your
own research, and if there is any doubt, use purpose-bought rechargeable cells.

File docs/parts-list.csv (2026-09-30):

Module | Ref | Part / value | Qty | Have it? | Notes
A | PV1 | Solar panel ~1-2 W (reference: AS102-0712A 1.2 W) | 1 |  | Measure open-circuit voltage (Voc) cold and in full sun to choose Option A or B
A | U0 | 5 V buck module (e.g. MP1584EN) | 1 |  | Option B panels only (Voc above 6.5 V). Set to 5.00 V and check reverse leakage before connecting M1. Not a linear regulator; not the TPS63802
A | M1 | Protected TP4056-family charger module (TP4056/TC4056 + DW01A + 8205A) | 1 |  | Six labelled pads IN+/IN-/B+/B-/OUT+/OUT-. Change PROG for 100-150 mA charge
A | BT1 / BT2 | 18650 Li-ion cell | 2 |  | Matched type/age/capacity/state of charge; 1S2P; or one protected 1S2P pack
A | - | Insulated 2-cell parallel holder | 1 |  | No soldering to bare cell cans
A | FB1 / FB2 | 1 A fuse and holder | 2 |  | One per cell positive lead before the parallel junction
A | F2 | 1 A fuse and holder | 1 |  | In series after M1 OUT+
A | S1 | SPST service switch | 1 |  | After F2; breaks the protected rail
B | M2 | ATmega328P Pro Mini-class board (reference: BTE13-010A) | 1 |  | Remove regulator and power LED; set fuses for internal 8 MHz; flashed over ISP
B | C3 | 100 uF electrolytic 10 V | 1 |  | Across M2 VCC/GND
B | C4 | 100 nF ceramic | 1 |  | Across M2 VCC/GND
C | R3 | 47 ohm 1/4 W resistor | 1 |  | At the controller end of the LED cable; 56 ohm if current exceeds 22 mA at 4.20 V
C | JLED | Low-power LED string | 1 |  | About 2.5-3 V forward and 20 mA or less in total; driven directly by PWM from D9
D | LDR1 | Light-dependent resistor | 1 |  | Shade it from the LEDs; must see the sky
D | R4 | 47 kohm resistor | 1 |  | LDR divider lower resistor (A1 to OUT-)
D | SW1 | Momentary push button (normally open) | 1 |  | D2 to OUT-; 60 s test
E | M3 | Wemos D1 Mini (ESP8266) | 1 |  | Telemetry tiers 1 and 2
E | U3 | TPS63802 3.3 V buck-boost breakout (e.g. HL802A) | 1 |  | VIN from VBAT_SYS; OUT to D1 3V3 in Tier 2 only
E | C2 | 470 uF electrolytic 10 V | 1 |  | At U3 input
E | Q2 | 2N3904 NPN transistor (or BC547-BC550) | 1 |  | Serial inverter and level shifter; check the E-B-C pin order of your part
E | R8 | 47 kohm resistor | 1 |  | Controller D1/TX to Q2 base
E | R9 | 100 kohm resistor | 1 |  | Q2 base to emitter (OUT-)
E | R10 | 10 kohm resistor | 1 |  | Q2 collector to D1 Mini 3V3; collector also to D6
E | R5 | 220 kohm resistor | 1 |  | VBAT_SYS to D1 Mini A0
F | - | Weatherproof enclosure with cable glands | 1 |  | Shaded; cells separated from heat; antenna clear of metal and cells
F | - | Perfboard or stripboard carrier | 1 |  | Socket every module
F | - | Female headers and screw terminals | - |  | Keep modules replaceable
Tools | - | USBasp programmer (or Arduino Uno/Nano as ISP) | 1 |  | One-time fuses and every firmware update
Tools | - | Current-limited bench supply | 1 |  | Controller and LED tests without a battery
Tools | - | Multimeter | 1 |  | Every commissioning gate

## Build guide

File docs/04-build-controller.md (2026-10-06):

# 04 – Module B: controller

**Drawings:** sheet 2 (`drawings/sheet-2.png`) and the board map
(`drawings/BTE13-010A-pin-map.png`). **Reference photos:**
[`reference/`](reference/). **Layouts:** the whole system on a
[breadboard](drawings/breadboard-layout.png) (bench build) or a
[perfboard carrier](drawings/perfboard-layout.png) (final build).

The controller is an ATmega328P Pro Mini-class board, modified to run straight
from the battery and to sleep at microamp levels. It runs the lights on its
own; nothing else in the system is required for the lights to work.

**What you will learn:** SMD rework (removing a regulator and an LED),
identifying a board from its silkscreen and tracks, what AVR fuses are, ISP
programming, and why clock speed and supply voltage are linked.

---

## Choosing a board

Any ATmega328P Pro Mini-class board works: 3.3 V/8 MHz or 5 V/16 MHz, genuine
or clone. The reference build uses a **BTE13-010A** clone with a 16 MHz
crystal. Whatever the board, the same fuse settings switch it to the
ATmega328P's internal 8 MHz oscillator, so the crystal or resonator no longer
matters and can stay fitted.

**Buy the 16 MHz board if that is what you can find.** Most Pro Minis on sale
are the 5 V/16 MHz version; 3.3 V/8 MHz boards are harder to find and cost
more. They use the same ATmega328P chip, and the two versions differ only in
the regulator and the clock part. This build removes the regulator and stops
using the crystal, so after rework and fuse setting both versions behave the
same. What you cannot do is leave a 16 MHz board running at 16 MHz from the
battery; see [Why the controller runs at 8 MHz](#why-the-controller-runs-at-8-mhz).

Check the chip marking says **ATmega328P** or **ATmega328PB**. Many current
clones carry the 328PB, sometimes sold as "ATmega328P". It runs the same
firmware and fuses (this firmware has been run on both chips), and needs only
avrdude's `-p m328pb` part name
([08 – Firmware](08-firmware.md#one-time-preparation-of-a-new-board)). Boards
with an ATmega32U4 (Pro Micro) or ATmega168 are not compatible.

**A second tested board** is a common blue "Pro mini" clone with an
ATmega328PB and a 16 MHz crystal
([photo](reference/ProMini-328PB-front.jpeg)). Its pins match the reference
board; only the parts around them differ. It carries two LEDs, each with a
1 kΩ resistor (marked `102`). The red LED beside the 5-pin regulator (marked
`LBM3`) is the power LED, drawing about 1.8 mA. The LED near pins 7–9, beside
an `L` silkscreen mark, is on D13. Step 4 shows how to tell them apart on
any board.

---

## Pin map

| Pin | Connection | Module |
| :---- | :--- | :----- |
| VCC | VBAT_SYS (protected battery) | A |
| GND | GND_LOAD (M1 OUT-) | A |
| RAW | Not connected | – |
| D9 | R3 47 Ω → LED string + | C |
| D7 | LDR supply (switched) | D |
| A1 | LDR / R4 midpoint | D |
| D2 | Test button to GND_LOAD | D |
| D1/TX | R8 47 kΩ → Q2 base (telemetry) | E |
| 11–13 | ISP only (MOSI, MISO, SCK) | – |
| RST | ISP only | – |

D0, D3–D6, D8, D10 and A0, A2–A7 are unused; the firmware drives unused
digital pins low and disables unused analog input buffers.

---

## Powering the board: VCC, RAW and the serial header

A Pro Mini has three pins that look like power inputs:

| Pin | What it is | In this build |
| :--- | :--- | :--- |
| `RAW` | Input to the on-board regulator | Never connected |
| `VCC` (top row) | The chip's supply rail | The supply goes in here |
| `VCC` on the serial header | Same rail as the top-row `VCC`  | Step 3 check only |

You may read that "VCC is an output". That is true only when the board is
fed through RAW: the regulator then produces VCC, and the pin can supply
other parts. Feeding VCC directly bypasses the regulator. That is a normal
way to power a Pro Mini, and it is how this build runs, from the protected
battery rail. Once the regulator is removed, VCC is the only way in.

On the reference board, and on standard Pro Mini designs, the top-row `VCC`
pin and the serial header's `VCC` are the same copper. Check yours once with
the board unpowered, in continuity mode: top-row `VCC` to header `VCC` should
beep, and after rework `RAW` to `VCC` should not.

Only one power source at a time, and never 5 V:

| Stage | Power source | Into | Regulator |
| :--- | :--- | :--- | :--- |
| Step 2 – fuses and flash | USBasp set to 3.3 V | `VCC` (ISP)  | Fitted is fine |
| Step 3 – first power-up check | USB-UART adapter set to 3.3 V  | Header `VCC` | Fitted is fine |
| Gate 1 – bench | Bench supply 3.80 V, 200 mA | `VCC` | Removed |
| Gate 2 onwards | Battery via M1 OUT+ (VBAT_SYS) | `VCC` | Removed |

---

## Build steps

Prove the chip, fuses and firmware first, then do the rework, then decoupling.
Gate 0 confirms the rework before anything goes onto the bench supply.

### 1. Fit headers

Fit headers (or plan direct wiring) for VCC, GND, D1/TX, D2, D7, D9, A1 and
the six ISP pins (VCC, GND, RST, 11, 12, 13).

### 2. Set the fuses and flash the firmware

Follow [08 – Firmware](08-firmware.md):

1. Read the chip signature: `1E 95 0F` (ATmega328P) or `1E 95 16`
   (ATmega328PB, use `-p m328pb`).
2. Set the fuses once: low `0xE2`, high `0xD9`, extended `0xFD`.
3. Build and flash the `advanced` firmware for commissioning.

| Fuse | Value  | Meaning |
| :--- | :----- | :--- |
| Low | `0xE2` | Internal 8 MHz RC oscillator, no ÷8 |
| High | `0xD9` | No bootloader; SPI programming enabled |
| Extended | `0xFD` | Brown-out detection at 2.7 V |

### 3. First power-up check

This proves the board before you solder on it.

1. Disconnect the USBasp.
2. Set a USB-UART adapter to **3.3 V**. Connect adapter GND to GND, adapter
   VCC to the serial header's `VCC`, and controller TX to adapter RX. Leave
   the adapter's TX, DTR and CTS open.
3. Run `pio device monitor --baud 9600` from `firmware/controller` and press
   the board's reset button. The banner should show the firmware version and
   the time you built it, followed by `fw=` lines.
4. Meter DC volts across the top-row `VCC` and `GND` pins and compare with
   `vdd=`.

| Check | Expect |
| :--- | :--- |
| Banner | `Firmware v0.6.0 built <date and time of your build>`  |
| `vdd=` vs meter | Within 0.05 V (calibrate in Gate 1 if not) |
| `battery=` | `LOW`: correct on 3.3 V, below the 3.45 V level |
| First lines | `cause=STARTUP_TEST`, then `DAY_OFF` or `DUSK_TO_DAWN` |

3.3 V is close to the 3.30 V cut-off, so leave the lighting tests for Gate 1.
`vdd=` around 5 V means the adapter is set to 5 V: disconnect it at once.
When you have finished, disconnect the adapter's VCC. From here on the
adapter is a monitor only (TX → RX and GND).

### 4. Identify the regulator and power LED

1. Photograph the board. With no power applied, use continuity mode to trace
   RAW to the regulator's input and VCC to its output. The regulator is
   usually a SOT-23-5 or SOT-89 part near RAW.
2. Find the power LED: the LED and series resistor connected permanently
   across VCC and GND. The LED on D13 is a different one; leave it.
   The easiest test: with this firmware running (step 3), the controller
   holds D13 low, so the D13 LED stays dark. **The LED that stays lit is the
   power LED.** (Both flicker during ISP flashing, because D13 is also SCK.)

### 5. Remove them

1. Remove the regulator with hot air, or with plenty of flux and a wide iron
   tip heating all pins together. Removing the power LED (or just its series
   resistor) is enough for the LED branch.
2. Do not remove decoupling capacitors next to the regulator.
3. Check for shorts between VCC and GND, and that RAW no longer connects to
   VCC.
4. Repeat the step 3 check. The same banner shows the rework did no harm.

Why: the regulator and power LED together can draw milliamps continuously,
which is hundreds of times the controller's sleep current. A power LED with
a 1 kΩ (`102`) resistor draws about (3.7 V − LED voltage) / 1 kΩ: roughly
0.8–1.8 mA depending on its colour, or 20–45 mAh a day. After a low-voltage
cut-off it would keep draining the cell until the pack protection trips. With a 2.7–4.2 V
Li-ion rail the ATmega328P needs no regulator at 8 MHz. The rework must be
done before Gate 0, which checks for it, and Gate 1.

### 6. Fit decoupling

On the carrier, fit C3 (100 µF, 10 V) and C4 (100 nF) across VCC and GND,
close to the board.

---

## Why the controller runs at 8 MHz

A 16 MHz Pro Mini is meant to run from its 5 V regulator. In this build the
chip runs directly from one Li-ion cell, at 2.7–4.2 V, and 16 MHz is not
reliable at those voltages.

**The voltage needed rises with clock speed.** The ATmega328P datasheet's
safe operating area allows 10 MHz from 2.7 V and 20 MHz from 4.5 V, with the
limit rising in a straight line between them. On that line, 16 MHz needs about
**3.8 V**:

| Clock  | Minimum rated supply | Li-ion cell (2.7–4.2 V) |
| :----- | :--- | :--- |
| 8 MHz  | 2.4 V | In spec over the whole range |
| 16 MHz | ~3.8 V | Out of spec for most of a night |

A cell rests at about 3.6–3.7 V and sinks lower overnight while the lights
draw on it, so a 16 MHz controller would run out of spec for most of every
night. Below its rated voltage an AVR does not stop cleanly: it can misread
flash, execute wrong instructions or corrupt registers, and it gets worse in
the cold. A 16 MHz board often seems fine on a warm bench, then fails at
random on a cold winter night outdoors, which is very hard to diagnose.

**Brown-out protection cannot fix it at 16 MHz.** The 2.7 V brown-out reset
(extended fuse `0xFD`) holds the chip in reset before it leaves its rated
area at 8 MHz. To protect a 16 MHz chip the same way you would need the 4.3 V
brown-out level, which is above a fully charged cell, so the controller would
never run.

**8 MHz also uses less power.** While the lights are on, the controller sleeps
in IDLE mode with its clock running, because Timer1 generates the D9 PWM. The
current it draws in that state rises roughly in proportion to clock speed. At
8 MHz there is still plenty of headroom for the firmware, which spends almost
all of its time asleep.

**Why the internal oscillator and not the crystal.** The 16 MHz crystal could
be divided down to 8 MHz in firmware, but the internal RC oscillator is
simpler. It needs no external parts, behaves the same on every board, whether
it has a crystal or a resonator, and restarts faster when the chip wakes from
power-down. Its accuracy is good enough for the 9600-baud telemetry link.
Setting the fuses is therefore the only change needed. It also clears the
board's bootloader setting; flashing is by ISP only
([why ISP, not a USB-serial upload](08-firmware.md#why-isp-not-a-usb-serial-upload)).

The firmware is built for the 8 MHz clock (PlatformIO board
`pro8MHzatmega328`), so its PWM and serial timing are wrong until the fuses
are set: garbled serial text is the giveaway.

---

## Test gates

The controller is proven on a current-limited bench supply in **Gate 1**, then
on the protected battery in **Gate 2**
([10 – Commissioning](10-commissioning.md)). The printable
[controller bench sheet](drawings/controller-bench-sheet.pdf) covers Gate 1.

---

## What can go wrong

| Symptom | Likely cause |
| :--- | :--- |
| Programmer cannot see the chip | Wiring, pin 1 orientation, or no VCC  |
| Signature `0x000000` or `0xffffff` | No target power, or MISO/MOSI swapped |
| Signature `1E 95 16` | ATmega328PB: use `-p m328pb` |
| Serial text is garbage | Fuses not set: still on 16 MHz clock  |
| High sleep current | Regulator or power LED still fitted |
| D9 PWM not ~1.96 kHz | Wrong clock (check the fuses) |

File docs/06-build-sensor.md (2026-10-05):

# 06 – Module D: light sensor and test button

**Drawing:** sheet 2 (`drawings/sheet-2.png`). **Wiring:** nets `LDR_POWER`,
`LDR_SENSE` and `TEST`.

The light sensor decides when it is dusk and dawn; the button gives you a
60-second test at any time of day.

**What you will learn:** voltage dividers, ratiometric ADC readings, switching
a sensor's supply from a GPIO pin to save power, hysteresis and debouncing,
and pin-change interrupts.

---

## How the sensor works

```
D7 ──> LDR1 ──┬──> A1
              │
              R4 47 kΩ
              │
           GND_LOAD
```

The LDR's resistance rises in the dark. With R4 = 47 kΩ, A1 reads as a fraction
of VCC:

| A1 reading | Meaning | LDR resistance |
| :--- | :--- | :--- |
| Below 30 % | Dark | Above ~110 kΩ  |
| 30–60 % | In between (no change) | ~31–110 kΩ |
| Above 60 % | Light | Below ~31 kΩ |

Because D7 and the ADC reference are both VCC, the reading does not depend on
battery voltage. D7 is switched on for a few milliseconds per wake, so the
divider draws nothing between readings. A reading must stay dark (or light) for
300 scheduler seconds – about 5.5 minutes on the reference board – before the
controller changes state, and the gap between 30 % and 60 % stops it
hunting at dusk.

The thresholds live in `firmware/controller/include/config.h`
(`LDR_DARK_RATIO`, `LDR_LIGHT_RATIO`). R4 sets where they fall: a larger R4
makes the sensor call "dark" later (it needs a darker sky).

---

## Build steps

1. Wire D7 → LDR1 → A1, and A1 → R4 (47 kΩ) → GND_LOAD.
2. Mount the LDR where it sees the sky but **not the LED string**: the lights
   must never be able to convince the sensor it is daytime. A short tube or
   hood around the LDR helps. Check it at night: with the lights on, `ldr=`
   should rise by only a few percent and stay well below the light threshold
   (Gate 3, step 6). On the bench, a string near the LDR raised it by about
   4.5 %.
3. Wire SW1 between D2 and GND_LOAD. The firmware enables D2's internal
   pull-up and a pin-change interrupt, so a press wakes the controller
   immediately.

---

## Test gate

**Gate 3** in [10 – Commissioning](10-commissioning.md): cover and uncover the
LDR and confirm the transitions. Test darkness with a truly light-tight cover;
a loose cap can still let through enough light to read about 20 %.

**Calibrate in the final position.** With Advanced Telemetry running, note the
`Arduino LDR` value at the moment you would like the lights to come on. If it
is well above 30 %, the lights will come on later than you want: raise
`LDR_DARK_RATIO` in `config.h` (keeping `LDR_LIGHT_RATIO` about 0.3 above it),
or fit a smaller R4. If the lights come on too early, do the opposite.

---

## What can go wrong

| Symptom | Likely cause |
| :--- | :--- |
| Lights never come on | Dark reading stays above 30 % |
| Lights switch off soon after dusk | LEDs lighting the LDR |
| Lights on during the day | LDR shaded or covered |
| Button does nothing | Cut-off active, or D2 not to GND |
| Transition takes ~5.5 min | Normal: 300 s confirmation |

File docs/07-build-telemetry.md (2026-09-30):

# 07 – Module E: telemetry hardware

**Drawings:** sheet 6 (Tier 1, `drawings/sheet-6.png`) and sheet 3 (Tier 2,
`drawings/sheet-3.png`). **Layouts:** [breadboard](drawings/breadboard-layout.png)
and [perfboard](drawings/perfboard-layout.png), both showing JP1 and JP2.
**Wiring:** nets `UART_*`, `ESP_3V3`, `ADC_BATT` and `WAKE`. **Software:**
[09 – Home Assistant](09-home-assistant.md).

Telemetry is optional: skip this module for a standalone (Tier 0) build. It is
strongly recommended while commissioning, because it turns the controller's
diagnostics into live Home Assistant entities without a cable on the
controller.

**What you will learn:** serial (UART) signalling, level shifting and
inverting with a single transistor, buck-boost converters, ADC dividers,
ESP8266 deep sleep and wake-on-reset, and keeping two power domains apart.

---

## One harness, two tiers

The same wiring serves both telemetry tiers. Only the D1 Mini's power source
and the firmware change.

| Connection | Tier 1 Advanced | Tier 2 Production |
| :--- | :--- | :--- |
| Controller D1/TX → Q2 → D6 | Fitted | Fitted |
| VBAT_SYS → R5 → A0 | Fitted | Fitted |
| D1 Mini G → GND_LOAD | Fitted | Fitted |
| D1 Mini power | Its own micro-USB | U3 OUT → 3V3 pin  |
| U3 OUT → D1 Mini 3V3 | **Disconnected**  | Connected |
| D0 → RST | Optional | Fitted |
| Controller firmware | `advanced` | `production` |
| ESPHome profile | Advanced | Production |

**Never power the D1 Mini from USB and U3 at the same time**: its onboard
regulator and U3 would both drive the 3V3 rail. Fit a jumper or a two-pin
plug in U3 OUT so switching tiers is a clean, visible change.

---

## The serial receiver (Q2)

```
Controller D1/TX ── R8 47 kΩ ──┬── Q2 base (2N3904)
                               R9 100 kΩ
                               │
GND_LOAD ──────────────────────┴── Q2 emitter

D1 Mini 3V3 ── R10 10 kΩ ──┬── Q2 collector
                            └── D1 Mini D6
```

The controller's TX swings between 0 V and the battery voltage (up to 4.2 V),
which is too high for the ESP8266's 3.3 V inputs. Q2 turns each TX high into a
collector low at D1 Mini logic levels, and each TX low into a high through R10.
The signal arrives inverted, so the ESPHome profiles declare D6 as
`inverted: true`. The D1 Mini's TX is never connected: the link is receive-only
and the D1 Mini cannot affect the controller.

R9 holds Q2 off whenever the controller's TX is low, released or unpowered. A
serial line idles high, so with the `advanced` build Q2 conducts between lines
(about 0.4 mA, mostly from the USB-powered D1 Mini). The `production` build
enables its serial port only while sending and parks TX low in between, so in
Tier 2 the link draws nothing between messages.

**Check the transistor's pin order.** 2N3904 and BC547-family parts come in
different E-B-C orders depending on the maker. Confirm with a datasheet or a
diode test before soldering.

---

## Battery sense

`VBAT_SYS → R5 220 kΩ → A0`. The D1 Mini already has a 220 kΩ/100 kΩ divider on
A0, so the total ratio is about 5.4. Clone boards vary; calibrate the ESPHome
multiplier against a meter in Gate 7.

---

## U3 – 3.3 V supply for Tier 2

The battery rail runs from 4.2 V down to about 3.0 V, crossing 3.3 V along the
way. A buck-only regulator cannot hold 3.3 V below that; a buck-boost can. The
TPS63802 breakout draws about 20–30 µA quiescent and handles the ESP8266's
radio bursts comfortably.

1. Set the breakout's output jumper to 3.3 V and **measure it** before
   connecting anything.
2. Wire VIN to VBAT_SYS (with C2, 470 µF, close to VIN) and GND to GND_LOAD.
3. Take U3 OUT to a jumper or plug that goes to the D1 Mini 3V3 pin. Leave it
   open for Tier 1.

The D1 Mini's own regulator stays fitted; in Tier 2 it is simply unused
because nothing feeds its 5V pin.

---

## Build steps

1. Build the Q2 receiver (Q2, R8, R9, R10) on the carrier near the D1 Mini.
2. Controller D1/TX → R8; Q2 collector → D1 Mini D6; R10 to D1 Mini 3V3.
3. R5 from VBAT_SYS to D1 Mini A0.
4. D1 Mini G to GND_LOAD (never to B-).
5. Fit U3 and C2; U3 OUT to the D1 Mini 3V3 pin **through an open jumper**.
6. Fit a removable link from D1 Mini D0 to RST (needed for Tier 2 deep-sleep
   wake; remove it when flashing the D1 Mini over USB).

Then flash the D1 Mini and set up Home Assistant:
[09 – Home Assistant](09-home-assistant.md).

---

## Test gates

The receiver is exercised from Gate 1 onwards if you commission with Tier 1.
**Gate 7** covers A0 calibration and service outages; **Gate 8** covers the
switch to Tier 2 and its standby current
([10 – Commissioning](10-commissioning.md)).

---

## What can go wrong

| Symptom | Likely cause |
| :--- | :--- |
| No controller data in HA | Controller running `standalone` |
| Garbled or dropped lines | Q2 pin order, or grounds not common |
| Battery voltage wildly off | Multiplier not calibrated |
| D1 Mini resets on radio bursts | U3 output not 3.3 V, or C2 missing  |
| D1 Mini never wakes (Tier 2) | D0 → RST link missing |
| Cannot flash D1 Mini over USB  | D0 → RST link fitted: remove it |

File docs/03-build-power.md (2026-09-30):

# 03 – Module A: power, charging and battery

**Drawing:** sheet 1 (`drawings/sheet-1.png`). **Wiring:** nets `PV_*`,
`CHARGE_*`, `CELL*`, `PACK_*`, `PROTECTED_POS`, `FUSED_POS`, `VBAT_SYS`,
`GND_LOAD` in [`wire-schedule.csv`](wire-schedule.csv).

This module turns sunlight into a protected battery rail. It has no firmware,
and it is the part of the build most worth doing slowly.

**What you will learn:** how a linear Li-ion charger works and how to set its
current, why a solar panel's open-circuit voltage matters, how protection
circuits separate the cell from the load, how to fuse parallel cells, and how
to qualify a module you did not design.

---

## How it fits together

```
PV1 ──(Option B: U0 5 V buck)──> M1 IN+/IN-
                                  M1 B+/B-  <── FB1/FB2 ── BT1 ∥ BT2 (1S2P)
                                  M1 OUT+ ── F2 1 A ── S1 ── VBAT_SYS (+)
                                  M1 OUT- ─────────────────── GND_LOAD (−)
```

- **VBAT_SYS** is the protected, fused, switched positive rail. Every load
  (controller, U3, battery sense) connects here.
- **GND_LOAD** is M1 OUT-. Every load ground connects here. It is the only
  ground used in the rest of the build.
- **B- is not ground.** It sits behind the module's protection MOSFETs. Never
  connect anything to B- except the cells, and never link B- to OUT-.

---

## Choose your solar input: Option A or Option B

The TP4056 family is rated for a 4–8 V input, and 8 V is an absolute maximum,
not a design target. A panel's open-circuit voltage (Voc) rises in cold
weather and appears whenever the battery is full and the charger stops drawing
current. So the choice depends on the panel's **measured, cold, no-load** Voc:

| Panel Voc (cold, no load) | Option | Solar input |
| :--- | :----- | :--- |
| 6.5 V or less | A | Panel straight to M1 IN+/IN- |
| Above 6.5 V | B | Panel → U0 5 V buck → M1 IN  |

The 6.5 V line leaves margin below the charger's absolute maximum; check it
against the datasheet of the chip actually on your module. A nominal "5 V"
panel is usually Option A. The reference 1.2 W panel (Vmp 7 V, Voc 7.6 V) is
Option B.

**U0 for Option B** must be a switching buck converter rated well above the
panel's cold Voc. The MP1584EN module (4.5–28 V in) is a good fit. It does not
ship set to 5 V: adjust it before it ever sees the charger.

Series diodes are **not** a substitute for either option: their drop depends on
current, so at no load they limit almost nothing.

---

## Build steps

### 1. Identify the charger module

1. Photograph both sides of M1. Read the pad labels: IN+, IN-, B+, B-, OUT+,
   OUT-. Work from the labels, not from pad positions in any drawing.
2. Read the chip markings. TP4056, TC4056 and similar parts behave alike but
   are not guaranteed identical; find the datasheet for yours.
3. With nothing connected, check with a meter whether IN- and OUT- are joined
   on the board (on many modules they are). Do not add any external link
   either way.

### 2. Set the charge current

Most modules ship with the PROG resistor set for about 1 A, which is far more
than a 1–2 W panel can supply; the charger would pull the panel voltage down
and stall. For a genuine TP4056 the charge current is about 1200 / R(kΩ) mA:

| PROG resistor | Charge current |
| :--- | :--- |
| 12 kΩ | ~100 mA |
| 8.2 kΩ | ~146 mA |
| 1.2 kΩ | ~1 A (typical as shipped) |

Replace the PROG resistor (a small SMD part next to the chip) for 100–150 mA.
Confirm the result by measurement in Gate 5; a clone may not follow the
formula exactly.

### 3. Prepare the cells

1. Choose two matched 18650 cells (see Safety in
   [02 – Parts, tools, skills and safety](02-parts-and-tools.md#safety)).
2. Charge or discharge each to the same voltage (within 0.05 V) separately
   before joining them.
3. Fit a 1 A fuse in each cell's positive lead (FB1, FB2), then join the two
   fused leads to M1 B+. Join both negatives to M1 B-.

### 4. Build the protected rail

1. M1 OUT+ → F2 (1 A) → S1 → **VBAT_SYS**.
2. M1 OUT- → **GND_LOAD**.
3. Leave S1 open until the controller is ready (Gate 2).

### 5. Connect the solar input

- **Option A:** panel + to M1 IN+, panel − to M1 IN-.
- **Option B:** first set U0 to 5.00 V on a current-limited supply with its
  output disconnected (Gate 5), then panel → U0 IN, U0 OUT → M1 IN.

Do the panel connection last, after Gate 5 has passed on a bench supply.

---

## Test gates

This module is qualified by **Gate 0** (inspection), **Gate 2** (protected
battery), **Gate 5** (charger input and charge current) and **Gate 6** (solar
panel) in [10 – Commissioning](10-commissioning.md).

---

## What can go wrong

| Symptom | Likely cause |
| :--- | :--- |
| No voltage at OUT+ with cells in | Protection tripped; briefly charge |
| Charger LED on, battery not rising | Charge current higher than panel can give |
| Module hot in sun | Charge current set too high |
| Battery drains at night | Reverse leakage into panel or U0 |
| One cell warmer than the other | Unmatched cells: stop and separate |

A charger's LED is not a measurement. Use a meter in series with B+ to see the
real charge current.

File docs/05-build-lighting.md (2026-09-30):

# 05 – Module C: low-power lighting

**Drawing:** sheet 2 (`drawings/sheet-2.png`). **Wiring:** nets `PWM` and
`LED_POS`, plus `JLED.-` on `GND_LOAD`.

This module is a single resistor and a string of LEDs, which makes it the best
place in the project to learn how LED current really works.

**What you will learn:** LED forward voltage, why a series resistor sets
current, what PWM does and does not change, how much current a
microcontroller pin can safely supply, and how to measure it.

---

## What kind of lights

This controller drives a **low-power LED string directly by PWM from pin D9**.
There is no MOSFET or transistor between the pin and the lights, so the string
must be one that is happy at 20 mA or less in total, from a 3–4.2 V supply,
through a series resistor.

Suitable: small "fairy" or garden LED strings with a forward voltage around
2.5–3 V, or a handful of individual LEDs, each with its own resistor.

**Not suitable:** mains lights, 12 V garden lights, conventional or legacy
light fittings, or any string that expects its own driver or battery box. For
those, see the driver stage in [12 – Going further](12-going-further.md).

---

## How the current is set

An LED string behaves roughly like a fixed voltage drop. The reference string
measured 2.56 V with almost no change across the battery range, so:

```
I = (VBAT − Vstring) / (R3 + Rpin)
```

`Rpin` is the ATmega328P's own output resistance, roughly 30 Ω at these
currents (a typical datasheet characteristic, not a guaranteed value). With
R3 = 47 Ω the model predicts:

| Battery | R3 = 47 Ω | R3 = 56 Ω |
| :--- | ---: | ---: |
| 4.20 V  | 21 mA | 18 mA |
| 3.70 V  | 15 mA | 13 mA |
| 3.40 V  | 11 mA | 9 mA |

These are predictions. Gate 1 measures the real current through the pin; the
reference string's own characterisation is in
[`reference/led-string-characterisation.md`](reference/led-string-characterisation.md).

**PWM** switches D9 fully on and off about 1,960 times a second. The duty
cycle sets the average current and the brightness; the peak current in each
pulse is still set by R3 and the pin. That is why the firmware's
`NIGHT_DUTY_PCT` is a brightness and energy setting, not a safety limit.

---

## Build steps

1. Fit R3 (47 Ω) on the carrier, **at the controller end**, from D9 to the
   LED output terminal. The outdoor cable should always be on the far side of
   the resistor.
2. Connect the LED string's positive lead to the R3 terminal and its negative
   lead to GND_LOAD.
3. If your string is made of parallel LEDs without their own resistors, it
   needs one resistor per branch; a single shared resistor does not balance
   them.

---

## Test gate

**Gate 1** in [10 – Commissioning](10-commissioning.md) measures the string
current at 3.40, 3.70 and 4.20 V at 100 % duty. If it exceeds 22 mA at 4.20 V,
fit 56 Ω and measure again. Also confirm that R3 and the controller stay at
room temperature, and that the string is dark with the controller unpowered
and during reset.

---

## What can go wrong

| Symptom | Likely cause |
| :--- | :--- |
| Very dim at 3.4 V | Expected: brightness tracks battery |
| Over 22 mA at 4.20 V | String Vf lower than reference: 56 Ω |
| Uneven brightness | Parallel LEDs sharing one resistor |
| Visible flicker on camera | 1.96 kHz PWM banding; normal to eye |
| Lights on while controller off | Wiring fault: D9 must be the only feed |

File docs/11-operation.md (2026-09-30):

# 11 – Operation and maintenance

Once commissioned, Solar Lights Lite needs no attention day to day. This page
describes normal behaviour, what the button and telemetry tell you, routine
care, and how to diagnose problems.

---

## A normal day

| When | What happens |
| :--- | :--- |
| Power-on or reset | 10 s flash (self-test) |
| Daytime | Lights off; controller wakes every 8 s |
| Dusk | ~5.5 min of darkness, then a slow fade up |
| Night | Lights on at the night level |
| Battery below 3.45 V | Night level halves |
| Dawn | ~5.5 min of light, then a slow fade off |
| Battery below 3.30 V | Lights off until daylight and > 3.60 V |

Brightness falls gently through a long night as the battery voltage drops. This
is by design: the LED string is driven directly, so its current follows the
battery.

## The test button

Press the button at any time to run the lights at the night level for
60 seconds – useful for checking the string in daylight. The button does
nothing while the low-voltage cut-off is active, which is itself a useful
signal: if a press gives no light, the battery is too low.

## What telemetry tells you

| Tier | Where to look | Look for |
| :--- | :--- | :--- |
| 0 | The lights themselves | On at dusk, off at dawn  |
| 1 | Advanced dashboard | Live state, every change |
| 2 | Production dashboard (hourly) | Battery trend over days  |

The most useful single view is **battery voltage at dawn over a week or
more**. A steady or rising trend means the panel is keeping up; a falling one
means the system is in deficit (see Seasonal care).

---

## Routine care

| Interval | Task |
| :--- | :--- |
| Monthly | Clean the panel; clear leaves and shade |
| Each season | Check dawn battery trend; adjust brightness |
| Twice a year  | Check glands, seals and for condensation |
| Yearly | Inspect cells, holder, fuses, connections |
| After a storm | Check the panel mount and the LED cable |

## Seasonal care

Winter brings shorter days, longer nights and weaker sun, so the same panel
harvests less while the lights use more. If the dawn battery voltage trends
down:

1. Clean and re-aim the panel (steeper tilt for winter).
2. Lower `NIGHT_DUTY_PCT` in `firmware/controller/include/config.h` (for
   example to 60) and reflash.
3. Consider a larger panel (check its Voc against Option A/B in
   [03 – Power](03-build-power.md)).

Remember the charger cannot sense cell temperature: in freezing weather see
[Known limitations](01-design-overview.md#known-limitations).

---

## Troubleshooting

| Symptom | Check first |
| :--- | :--- |
| Lights never come on | S1, fuses, cut-off; LDR seeing a light |
| Lights come on too late or early  | Recalibrate LDR thresholds (doc 06) |
| Lights on during the day | LDR shaded, covered or dirty |
| Lights flicker at dusk | LDR too close to the LED string |
| Very dim all night | Battery low: check dawn voltage trend  |
| Off before dawn most nights | Energy deficit: see Seasonal care |
| Button gives no light | Low-voltage cut-off active |
| No Tier 2 reports | D1 Mini power (U3), D0 → RST, Wi-Fi |
| Tier 2 D1 Mini awake all the time | OTA helper left on |
| Battery voltage reads wrong in HA | Recalibrate the A0 multiplier (doc 09) |

If a problem is not obvious, put the system back into **Tier 1**: reflash the
controller with `advanced`, run the D1 Mini on USB with the Advanced profile
(open the U3 jumper first), and watch every decision the controller makes.
That is exactly what Advanced Telemetry is for.

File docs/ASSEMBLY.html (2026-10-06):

SOLAR LIGHTS LITE / BUILD AND OPERATE GUIDE

# Low-power solar lights, built one module at a time.

v0.6.0 · MODULES A–F · TELEMETRY TIERS 0–2 · GATES 0–8

A small panel charges a protected Li-ion battery; an ATmega328P sleeps most of the time, detects dusk with a light sensor, and runs a low-power LED string from dusk to dawn. An optional Wemos D1 Mini reports it all to Home Assistant. Every module is built and tested on its own, so the project doubles as a hands-on course in soldering, microelectronics, embedded code and home automation.

Build

Six modules – power, controller, lighting, sensor, telemetry, enclosure – each with its own drawing and test gate.

Learn

SMD rework, AVR fuses and ISP, sleep and PWM, serial level shifting, ESPHome and Home Assistant.

Commission

Gates 0–8 add one thing at a time. Advanced Telemetry shows every controller decision during the soak test.

Operate

Production Telemetry reports hourly on battery power. The lights never depend on Wi-Fi.

Low-power lights only. The controller drives the LED string directly by PWM from pin D9 through a 47 Ω resistor, with no driver transistor. The whole string must run at 20 mA or less from a 3–4.2 V supply. Mains lights, 12 V garden lights and conventional or legacy fittings cannot be used; brighter lighting needs a driver stage (see Going further).

## 01 – Design overview

Solar Lights Lite is a small, modular solar lighting system. A solar panel charges a protected lithium-ion battery. An ATmega328P controller wakes from deep sleep every few seconds, decides whether it is dark, and drives a low-power LED string from dusk to dawn. An optional Wemos D1 Mini reports what the controller is doing to Home Assistant.

Every block is a separate module that you build, test and understand on its own before joining it to the next. That makes the project a practical course in microelectronics, soldering, low-power embedded code and home automation, as well as a working set of garden lights.

Sheet 7 – System overview · Full-size SVG · Printable PDF

### The modules

Module | What it is | Build guide
A | Panel, charger, 1S2P battery | Power
B | ATmega328P controller | Controller
C | Low-power LED string on D9 | Lighting
D | Light sensor (LDR) and button | Sensor
E | D1 Mini telemetry (optional) | Telemetry
F | Enclosure and final assembly | Commissioning

flowchart LR
    PV[Solar panel] --> OPT{Panel Voc}
    OPT -- Option A --> CHG[Protected 4056 charger]
    OPT -- Option B --> U0[5 V buck U0] --> CHG
    CHG --> BAT[1S2P Li-ion pack]
    CHG -- OUT+ via F2, S1 --> RAIL[VBAT_SYS rail]
    RAIL --> MCU[ATmega328P controller]
    MCU -- D7 / A1 --> LDR[Switched LDR]
    MCU -- D9 PWM + R3 --> LED[Low-power LED string]
    MCU -- D1/TX via Q2 --> D1[D1 Mini telemetry]
    RAIL -- U3 3.3 V --> D1
    D1 -. Wi-Fi .-> HA[Home Assistant]

The printable drawings in drawings/ show every module at terminal level; sheet 7 is the whole system on one page.

### Low-power lighting only

The lights are a low-power LED string: the reference string drops about 2.56 V and draws roughly 10–20 mA in total. The controller drives it directly by PWM from pin D9 through a 47 Ω resistor (R3). There is no MOSFET or transistor driver.

That has three consequences you should understand before choosing lights:

- R3 and the pin set the current; PWM duty sets brightness. Lowering the duty dims the string and saves energy, but it does not make an unsuitable string safe.
- The ATmega328P pin is the limit. Its working rating is 20 mA (40 mA absolute maximum). Mains lights, 12 V garden lights and conventional or legacy light fittings cannot be connected.
- Brightness follows the battery. With no regulator in the LED path, current falls as the cell discharges – about 21 mA at 4.20 V down to 11 mA at 3.40 V with the reference string. This is intended.

Brighter lighting is possible, but it needs a driver stage and a new energy budget; see 12 – Going further.

### How the controller works

Each wake the controller:

1. Measures its own supply voltage against the internal 1.1 V bandgap.
2. Powers the LDR divider from D7 for a few milliseconds and reads A1.
3. Advances a small scheduler (firmware/controller/include/schedule.h).
4. Sets the D9 PWM duty and goes back to sleep.

Situation | Behaviour
Day, lights off | Power-down sleep, wakes every 8 s
Dark for 300 s | Dusk confirmed, fades up at 2 % per s
Night | Lights at NIGHT_DUTY_PCT (100 %)
Battery below 3.45 V | Night duty halved
Light for 300 s | Dawn confirmed, fades off
Below 3.30 V for 30 s | Cut-off: lights off, button locked out
Cut-off, then > 3.60 V, day | Normal operation resumes
D2 button pressed | 60 s test at the night level
Reset | 10 s self-test flash

While the LEDs are lit, PWM needs the timer running, so the controller uses idle sleep and wakes every second. The switched LDR draws current only while it is being read.

### Telemetry tiers

The lights never depend on Wi-Fi or Home Assistant. Telemetry is a separate, optional module used in three ways:

Tier | Name | Purpose
0 | Standalone | No telemetry; controller only
1 | Advanced Telemetry | Always-on commissioning instrument
2 | Production Telemetry | Hourly battery-powered reporting

Advanced Telemetry is the path to production. While you build, calibrate and soak-test, the D1 Mini stays awake on USB power and decodes every diagnostic line from the controller into Home Assistant, with a dashboard built for commissioning. When the system passes its acceptance gates you reflash both boards and move the D1 Mini's supply from USB to the battery (U3). The wiring does not change. See 09 – Home Assistant.

### Design decisions

- ATmega328P at internal 8 MHz. A 16 MHz ATmega328P is outside its rated operating area below about 3.8 V, which a discharging Li-ion cell reaches every night. At 8 MHz it is rated down to 2.7 V. The internal oscillator also removes any dependency on the board's crystal. The common 5 V/16 MHz Pro Mini is therefore fine to buy: its fuses are reset to internal 8 MHz (04 – Controller).
- No voltage regulator for the controller. The Pro Mini runs straight from the protected battery rail (2.7–4.2 V is within its range), so its regulator and power LED are removed to eliminate their standby current.
- Switched LDR for dusk and dawn. Sensing panel voltage depends on charger loading and can back-feed an unpowered controller. A light-dependent resistor powered only while sampled needs no RTC, clock or network, and draws nothing between reads.
- Five-minute confirmation and a threshold gap. Car headlights, shadows and dusk flicker cannot toggle the lights.
- Dusk to dawn, no clock. Without an RTC the watchdog timer is the only time base, and it is uncalibrated (it varies by chip, typically 10–20 % slow). Dusk-to-dawn operation never needs wall-clock time.
- Firmware cut-off plus hardware protection. The firmware protects the battery from the lighting load; the charger module's DW01A protection remains the last line of defence for everything else.
- Receive-only telemetry through a transistor. Q2 inverts and level-shifts the controller's serial output for the 3.3 V D1 Mini, so the two boards never share a logic-level signal directly and the D1 Mini cannot drive the controller.
- Scheduler separate from hardware. schedule.h has no AVR code, so its behaviour is covered by host regression tests on any computer.
- Reuse first. Modules are chosen to be common and inexpensive, and parts already in a drawer are preferred where they qualify.

### Energy budget

These are planning figures, not measurements. Commissioning replaces them with your own numbers (10 – Commissioning). Assumptions: 14 dark hours, reference LED string at about 15 mA, Tier 2 telemetry.

Load | 100 % duty | 50 % duty
LED string, 15 mA × 14 h | 210 mAh | 105 mAh
Controller, 1 mA lit + 10 µA for 10 h | 14 mAh | 14 mAh
Controller status line, ~40 µA × 24 h | 1 mAh | 1 mAh
D1 Mini wakes, 24 × 20 s × 80 mA | 11 mAh | 11 mAh
U3 and D1 Mini sleep, 0.2 mA × 24 h | 5 mAh | 5 mAh
Other standby allowance | 1 mAh | 1 mAh
Total per day | ~242 mAh | ~137 mAh

On the harvest side, a TP4056-family linear charger set to 100 mA and an assumed 2.5 equivalent full-sun hours with 20 % derating gives about 200 mAh/day; at 150 mA, about 300 mAh/day. Winter, shade and panel angle change this dramatically. Two practical conclusions:

- Full brightness all night is marginal with a 1.2 W panel in winter. If the soak test shows the battery ending each night lower than the last, reduce NIGHT_DUTY_PCT or fit a larger panel.
- A bigger battery buys autonomy through cloudy spells; it cannot fix a persistent daily deficit.

### Known limitations

Read these before relying on the system unattended outdoors.

- No cell-temperature charge inhibit. TP4056-family modules usually have their TEMP input disabled. Li-ion cells must not be charged below 0 °C. In a climate where the enclosure can freeze, add temperature protection before unattended use (see Going further).
- Not a power-path charger. The load draws from the battery while it is charging, which can delay or confuse charge termination. Commissioning Gate 5 checks termination with the load connected.
- Firmware cut-off only switches the LEDs off. The controller, U3 and the D1 Mini keep drawing a small current until the pack protection trips.
- Battery percentage is an estimate from resting voltage, not coulomb counting.
- No wall-clock time. The watchdog clock drifts; features that need real time (for example "off at 22:30") need an RTC or network time.
- PWM at ~1.96 kHz may band on some cameras.
- A short on the LED cable is bounded, not protected. R3 plus the pin's resistance limit it to roughly 55 mA, which is above the pin's absolute maximum. Fit R3 at the controller end so the outdoor cable is always behind it.
- Telemetry reports controller state, not energy. It does not measure panel voltage, charge or load current, or temperature.

Back to top

## 02 – Parts, tools, skills and safety

Everything here is a common hobby module or through-hole part. A printable checklist version of the parts list, with a "have it?" column, is in parts-list.csv. Reference designators match the drawings, the wire schedule and the KiCad schematic.

### Parts by module

#### Module A – power, charging and battery

Ref | Part | Notes
PV1 | Solar panel, ~1–2 W | Reference: AS102-0712A 1.2 W
U0 | 5 V buck module, e.g. MP1584EN | Option B panels only (Voc > 6.5 V)
M1 | Protected TP4056-family module | Six pads: IN, B, OUT (± each)
BT1/BT2 | Matched 18650 Li-ion cells × 2 | 1S2P, in an insulated holder
FB1/FB2 | 1 A fuse + holder × 2 | One per cell positive lead
F2 | 1 A fuse + holder | After M1 OUT+
S1 | SPST service switch | Breaks the whole protected rail

#### Module B – controller

Ref | Part | Notes
M2 | ATmega328P Pro Mini-class board | Reference: BTE13-010A clone
C3 | 100 µF electrolytic, 10 V | Across VCC/GND at the controller
C4 | 100 nF ceramic | Across VCC/GND at the controller

#### Module C – lighting

Ref | Part | Notes
R3 | 47 Ω, ¼ W | At the controller end; 56 Ω option
JLED | Low-power LED string | ~2.5–3 V forward, ≤ 20 mA total
– | 2-way screw terminal or connector | Outdoor cable to the string

#### Module D – light sensor and button

Ref | Part | Notes
LDR1 | Light-dependent resistor | Typical 5–10 kΩ (light) type
R4 | 47 kΩ | LDR divider lower resistor
SW1 | Momentary push button, NO | D2 to ground; test button

#### Module E – telemetry (optional)

Ref | Part | Notes
M3 | Wemos D1 Mini (ESP8266) | Any common clone
U3 | TPS63802 buck-boost, 3.3 V | e.g. HL802A breakout, 3.3 V jumper
C2 | 470 µF electrolytic, 10 V | At U3 input
Q2 | 2N3904 NPN (or BC547–BC550) | Serial inverter; check E-B-C order
R8 | 47 kΩ | Controller TX to Q2 base
R9 | 100 kΩ | Q2 base to emitter
R10 | 10 kΩ | Q2 collector pull-up to 3V3
R5 | 220 kΩ | Battery sense to D1 Mini A0

#### Module F – enclosure and assembly

Item | Notes
Weatherproof box (IP65 or so) | Shaded position, room to service
Cable glands × 3 | Panel, LED string, LDR
Perfboard / stripboard carrier | Sockets for M1, M2, M3, U3
Female headers, screw terminals | Modules must stay replaceable
Standoffs, cable ties, labels | Label every connector (sheet 4)
Clear window or light pipe | So the LDR sees the sky, not the LEDs

### Parts to avoid

- AMS1117 or other linear regulators for U0. A linear regulator turns the difference between panel and 5 V into heat – about 30 % of a 1.2 W panel's output – and drops out of regulation in weak light.
- TPS63802 for U0. Its 5.5 V input limit is below a typical panel's open-circuit voltage.
- A second board that is not an ATmega328P (for example a Pro Micro with an ATmega32U4). The firmware uses 328P-specific registers, interrupts and ADC channels; it is not a drop-in replacement.
- Unknown or unmatched cells in parallel. See Safety below.

### Tools

Tool | Used for
Temperature-controlled iron | All soldering
Flux, braid or hot air | Removing the Pro Mini regulator/LED
Multimeter | Every test gate
Current-limited bench supply | Controller tests without a battery
USBasp programmer (or an Uno/Nano) | ISP flashing and one-time fuses
Computer with PlatformIO, avrdude | Building and flashing firmware
Home Assistant + ESPHome | Telemetry tiers 1 and 2
USB-UART adapter, 3.3 V (optional) | Wired serial monitor alternative
Power profiler (optional) | Sleep and LED current measurements

A current-limited bench supply is the single most useful tool here: it lets you test the controller and the LED string across the whole battery range, and simulate a flat battery, without risking a lithium cell.

### What you will learn

Area | Skills
Soldering | Through-hole, SMD rework, perfboard layout
Electronics | Dividers, LED current, transistor inverters
Power | Li-ion charging, protection, fusing, budgets
Microcontrollers | Fuses, ISP, sleep modes, watchdog, ADC, PWM
Firmware | C++ on AVR, host unit tests, build profiles
ESPHome | UART parsing, deep sleep, OTA, secrets
Home Assistant | Dashboards, packages, helpers, automations
Test discipline | Staged power-up and acceptance gates

### Safety

Lithium-ion cells store a lot of energy. Treat every step that involves them with care.

- Never connect cells in series to a 1S charger, and never bridge the module's B- to OUT-: that bypasses the protection circuit.
- Only parallel matched cells: same type, age, capacity and state of charge. Voltage equality alone does not prove two cells are safe to join. If in doubt, use a purpose-made protected 1S2P pack.
- Fuse each cell before the parallel junction (FB1/FB2). A single fuse after the junction cannot stop one cell feeding a fault in the other.
- Do not solder to bare cell cans. Use holders or pre-tabbed cells.
- Do not short the pack to test protection. Use a current-limited supply or an electronic load.
- Never charge below 0 °C and keep cells shaded and away from the charger and resistors. The charger module does not measure cell temperature.
- Supervise charging until Gate 5 and Gate 6 of 10 – Commissioning have passed.

#### A note on reclaimed cells

Reclaimed cells, such as those from disposable vapes, can be usable, but their history, condition, chemistry and suitability are unknown. They have worked well with TP4056-family chargers in this project, but that is experience, not a safety guarantee or a recommendation. Inspect and test cells properly, do your own research, and if there is any doubt, use purpose-bought rechargeable cells.

Back to top

## 03 – Module A: power, charging and battery

Drawing: sheet 1 (drawings/sheet-1.png). Wiring: nets PV_*, CHARGE_*, CELL*, PACK_*, PROTECTED_POS, FUSED_POS, VBAT_SYS, GND_LOAD in wire-schedule.csv.

This module turns sunlight into a protected battery rail. It has no firmware, and it is the part of the build most worth doing slowly.

What you will learn: how a linear Li-ion charger works and how to set its current, why a solar panel's open-circuit voltage matters, how protection circuits separate the cell from the load, how to fuse parallel cells, and how to qualify a module you did not design.

Sheet 1 – Module A: power, charging and battery · Full-size SVG · Printable PDF

### How it fits together

PV1 ──(Option B: U0 5 V buck)──> M1 IN+/IN-
                                  M1 B+/B-  <── FB1/FB2 ── BT1 ∥ BT2 (1S2P)
                                  M1 OUT+ ── F2 1 A ── S1 ── VBAT_SYS (+)
                                  M1 OUT- ─────────────────── GND_LOAD (−)
- VBAT_SYS is the protected, fused, switched positive rail. Every load (controller, U3, battery sense) connects here.
- GND_LOAD is M1 OUT-. Every load ground connects here. It is the only ground used in the rest of the build.
- B- is not ground. It sits behind the module's protection MOSFETs. Never connect anything to B- except the cells, and never link B- to OUT-.

### Choose your solar input: Option A or Option B

The TP4056 family is rated for a 4–8 V input, and 8 V is an absolute maximum, not a design target. A panel's open-circuit voltage (Voc) rises in cold weather and appears whenever the battery is full and the charger stops drawing current. So the choice depends on the panel's measured, cold, no-load Voc:

Panel Voc (cold, no load) | Option | Solar input
6.5 V or less | A | Panel straight to M1 IN+/IN-
Above 6.5 V | B | Panel → U0 5 V buck → M1 IN

The 6.5 V line leaves margin below the charger's absolute maximum; check it against the datasheet of the chip actually on your module. A nominal "5 V" panel is usually Option A. The reference 1.2 W panel (Vmp 7 V, Voc 7.6 V) is Option B.

U0 for Option B must be a switching buck converter rated well above the panel's cold Voc. The MP1584EN module (4.5–28 V in) is a good fit. It does not ship set to 5 V: adjust it before it ever sees the charger.

Series diodes are not a substitute for either option: their drop depends on current, so at no load they limit almost nothing.

### Build steps

#### 1. Identify the charger module

1. Photograph both sides of M1. Read the pad labels: IN+, IN-, B+, B-, OUT+, OUT-. Work from the labels, not from pad positions in any drawing.
2. Read the chip markings. TP4056, TC4056 and similar parts behave alike but are not guaranteed identical; find the datasheet for yours.
3. With nothing connected, check with a meter whether IN- and OUT- are joined on the board (on many modules they are). Do not add any external link either way.

#### 2. Set the charge current

Most modules ship with the PROG resistor set for about 1 A, which is far more than a 1–2 W panel can supply; the charger would pull the panel voltage down and stall. For a genuine TP4056 the charge current is about 1200 / R(kΩ) mA:

PROG resistor | Charge current
12 kΩ | ~100 mA
8.2 kΩ | ~146 mA
1.2 kΩ | ~1 A (typical as shipped)

Replace the PROG resistor (a small SMD part next to the chip) for 100–150 mA. Confirm the result by measurement in Gate 5; a clone may not follow the formula exactly.

#### 3. Prepare the cells

1. Choose two matched 18650 cells (see Safety in 02 – Parts, tools, skills and safety).
2. Charge or discharge each to the same voltage (within 0.05 V) separately before joining them.
3. Fit a 1 A fuse in each cell's positive lead (FB1, FB2), then join the two fused leads to M1 B+. Join both negatives to M1 B-.

#### 4. Build the protected rail

1. M1 OUT+ → F2 (1 A) → S1 → VBAT_SYS.
2. M1 OUT- → GND_LOAD.
3. Leave S1 open until the controller is ready (Gate 2).

#### 5. Connect the solar input

- Option A: panel + to M1 IN+, panel − to M1 IN-.
- Option B: first set U0 to 5.00 V on a current-limited supply with its output disconnected (Gate 5), then panel → U0 IN, U0 OUT → M1 IN.

Do the panel connection last, after Gate 5 has passed on a bench supply.

### Test gates

This module is qualified by Gate 0 (inspection), Gate 2 (protected battery), Gate 5 (charger input and charge current) and Gate 6 (solar panel) in 10 – Commissioning.

### What can go wrong

Symptom | Likely cause
No voltage at OUT+ with cells in | Protection tripped; briefly charge
Charger LED on, battery not rising | Charge current higher than panel can give
Module hot in sun | Charge current set too high
Battery drains at night | Reverse leakage into panel or U0
One cell warmer than the other | Unmatched cells: stop and separate

A charger's LED is not a measurement. Use a meter in series with B+ to see the real charge current.

Back to top

## 04 – Module B: controller

Drawings: sheet 2 (drawings/sheet-2.png) and the board map (drawings/BTE13-010A-pin-map.png). Reference photos: reference/. Layouts: the whole system on a breadboard (bench build) or a perfboard carrier (final build).

The controller is an ATmega328P Pro Mini-class board, modified to run straight from the battery and to sleep at microamp levels. It runs the lights on its own; nothing else in the system is required for the lights to work.

What you will learn: SMD rework (removing a regulator and an LED), identifying a board from its silkscreen and tracks, what AVR fuses are, ISP programming, and why clock speed and supply voltage are linked.

Sheet 2 – Modules B–D: controller, light sensor and low-power LEDs · Full-size SVG · Printable PDF

Reference board connection and programming map · Full-size SVG · Printable PDF

Breadboard layout – the whole system on a bench · Full-size SVG

### Choosing a board

Any ATmega328P Pro Mini-class board works: 3.3 V/8 MHz or 5 V/16 MHz, genuine or clone. The reference build uses a BTE13-010A clone with a 16 MHz crystal. Whatever the board, the same fuse settings switch it to the ATmega328P's internal 8 MHz oscillator, so the crystal or resonator no longer matters and can stay fitted.

Buy the 16 MHz board if that is what you can find. Most Pro Minis on sale are the 5 V/16 MHz version; 3.3 V/8 MHz boards are harder to find and cost more. They use the same ATmega328P chip, and the two versions differ only in the regulator and the clock part. This build removes the regulator and stops using the crystal, so after rework and fuse setting both versions behave the same. What you cannot do is leave a 16 MHz board running at 16 MHz from the battery; see Why the controller runs at 8 MHz.

Check the chip marking says ATmega328P or ATmega328PB. Many current clones carry the 328PB, sometimes sold as "ATmega328P". It runs the same firmware and fuses (this firmware has been run on both chips), and needs only avrdude's -p m328pb part name (08 – Firmware). Boards with an ATmega32U4 (Pro Micro) or ATmega168 are not compatible.

A second tested board is a common blue "Pro mini" clone with an ATmega328PB and a 16 MHz crystal (photo). Its pins match the reference board; only the parts around them differ. It carries two LEDs, each with a 1 kΩ resistor (marked 102). The red LED beside the 5-pin regulator (marked LBM3) is the power LED, drawing about 1.8 mA. The LED near pins 7–9, beside an L silkscreen mark, is on D13. Step 4 shows how to tell them apart on any board.

### Pin map

Pin | Connection | Module
VCC | VBAT_SYS (protected battery) | A
GND | GND_LOAD (M1 OUT-) | A
RAW | Not connected | –
D9 | R3 47 Ω → LED string + | C
D7 | LDR supply (switched) | D
A1 | LDR / R4 midpoint | D
D2 | Test button to GND_LOAD | D
D1/TX | R8 47 kΩ → Q2 base (telemetry) | E
11–13 | ISP only (MOSI, MISO, SCK) | –
RST | ISP only | –

D0, D3–D6, D8, D10 and A0, A2–A7 are unused; the firmware drives unused digital pins low and disables unused analog input buffers.

### Powering the board: VCC, RAW and the serial header

A Pro Mini has three pins that look like power inputs:

Pin | What it is | In this build
RAW | Input to the on-board regulator | Never connected
VCC (top row) | The chip's supply rail | The supply goes in here
VCC on the serial header | Same rail as the top-row VCC | Step 3 check only

You may read that "VCC is an output". That is true only when the board is fed through RAW: the regulator then produces VCC, and the pin can supply other parts. Feeding VCC directly bypasses the regulator. That is a normal way to power a Pro Mini, and it is how this build runs, from the protected battery rail. Once the regulator is removed, VCC is the only way in.

On the reference board, and on standard Pro Mini designs, the top-row VCC pin and the serial header's VCC are the same copper. Check yours once with the board unpowered, in continuity mode: top-row VCC to header VCC should beep, and after rework RAW to VCC should not.

Only one power source at a time, and never 5 V:

Stage | Power source | Into | Regulator
Step 2 – fuses and flash | USBasp set to 3.3 V | VCC (ISP) | Fitted is fine
Step 3 – first power-up check | USB-UART adapter set to 3.3 V | Header VCC | Fitted is fine
Gate 1 – bench | Bench supply 3.80 V, 200 mA | VCC | Removed
Gate 2 onwards | Battery via M1 OUT+ (VBAT_SYS) | VCC | Removed

### Build steps

Prove the chip, fuses and firmware first, then do the rework, then decoupling. Gate 0 confirms the rework before anything goes onto the bench supply.

#### 1. Fit headers

Fit headers (or plan direct wiring) for VCC, GND, D1/TX, D2, D7, D9, A1 and the six ISP pins (VCC, GND, RST, 11, 12, 13).

#### 2. Set the fuses and flash the firmware

Follow 08 – Firmware:

1. Read the chip signature: 1E 95 0F (ATmega328P) or 1E 95 16 (ATmega328PB, use -p m328pb).
2. Set the fuses once: low 0xE2, high 0xD9, extended 0xFD.
3. Build and flash the advanced firmware for commissioning.

Fuse | Value | Meaning
Low | 0xE2 | Internal 8 MHz RC oscillator, no ÷8
High | 0xD9 | No bootloader; SPI programming enabled
Extended | 0xFD | Brown-out detection at 2.7 V

#### 3. First power-up check

This proves the board before you solder on it.

1. Disconnect the USBasp.
2. Set a USB-UART adapter to 3.3 V. Connect adapter GND to GND, adapter VCC to the serial header's VCC, and controller TX to adapter RX. Leave the adapter's TX, DTR and CTS open.
3. Run pio device monitor --baud 9600 from firmware/controller and press the board's reset button. The banner should show the firmware version and the time you built it, followed by fw= lines.
4. Meter DC volts across the top-row VCC and GND pins and compare with vdd=.

Check | Expect
Banner | Firmware v0.6.0 built <date and time of your build>
vdd= vs meter | Within 0.05 V (calibrate in Gate 1 if not)
battery= | LOW: correct on 3.3 V, below the 3.45 V level
First lines | cause=STARTUP_TEST, then DAY_OFF or DUSK_TO_DAWN

3.3 V is close to the 3.30 V cut-off, so leave the lighting tests for Gate 1. vdd= around 5 V means the adapter is set to 5 V: disconnect it at once. When you have finished, disconnect the adapter's VCC. From here on the adapter is a monitor only (TX → RX and GND).

#### 4. Identify the regulator and power LED

1. Photograph the board. With no power applied, use continuity mode to trace RAW to the regulator's input and VCC to its output. The regulator is usually a SOT-23-5 or SOT-89 part near RAW.
2. Find the power LED: the LED and series resistor connected permanently across VCC and GND. The LED on D13 is a different one; leave it. The easiest test: with this firmware running (step 3), the controller holds D13 low, so the D13 LED stays dark. The LED that stays lit is the power LED. (Both flicker during ISP flashing, because D13 is also SCK.)

#### 5. Remove them

1. Remove the regulator with hot air, or with plenty of flux and a wide iron tip heating all pins together. Removing the power LED (or just its series resistor) is enough for the LED branch.
2. Do not remove decoupling capacitors next to the regulator.
3. Check for shorts between VCC and GND, and that RAW no longer connects to VCC.
4. Repeat the step 3 check. The same banner shows the rework did no harm.

Why: the regulator and power LED together can draw milliamps continuously, which is hundreds of times the controller's sleep current. A power LED with a 1 kΩ (102) resistor draws about (3.7 V − LED voltage) / 1 kΩ: roughly 0.8–1.8 mA depending on its colour, or 20–45 mAh a day. After a low-voltage cut-off it would keep draining the cell until the pack protection trips. With a 2.7–4.2 V Li-ion rail the ATmega328P needs no regulator at 8 MHz. The rework must be done before Gate 0, which checks for it, and Gate 1.

#### 6. Fit decoupling

On the carrier, fit C3 (100 µF, 10 V) and C4 (100 nF) across VCC and GND, close to the board.

### Why the controller runs at 8 MHz

A 16 MHz Pro Mini is meant to run from its 5 V regulator. In this build the chip runs directly from one Li-ion cell, at 2.7–4.2 V, and 16 MHz is not reliable at those voltages.

The voltage needed rises with clock speed. The ATmega328P datasheet's safe operating area allows 10 MHz from 2.7 V and 20 MHz from 4.5 V, with the limit rising in a straight line between them. On that line, 16 MHz needs about 3.8 V:

Clock | Minimum rated supply | Li-ion cell (2.7–4.2 V)
8 MHz | 2.4 V | In spec over the whole range
16 MHz | ~3.8 V | Out of spec for most of a night

A cell rests at about 3.6–3.7 V and sinks lower overnight while the lights draw on it, so a 16 MHz controller would run out of spec for most of every night. Below its rated voltage an AVR does not stop cleanly: it can misread flash, execute wrong instructions or corrupt registers, and it gets worse in the cold. A 16 MHz board often seems fine on a warm bench, then fails at random on a cold winter night outdoors, which is very hard to diagnose.

Brown-out protection cannot fix it at 16 MHz. The 2.7 V brown-out reset (extended fuse 0xFD) holds the chip in reset before it leaves its rated area at 8 MHz. To protect a 16 MHz chip the same way you would need the 4.3 V brown-out level, which is above a fully charged cell, so the controller would never run.

8 MHz also uses less power. While the lights are on, the controller sleeps in IDLE mode with its clock running, because Timer1 generates the D9 PWM. The current it draws in that state rises roughly in proportion to clock speed. At 8 MHz there is still plenty of headroom for the firmware, which spends almost all of its time asleep.

Why the internal oscillator and not the crystal. The 16 MHz crystal could be divided down to 8 MHz in firmware, but the internal RC oscillator is simpler. It needs no external parts, behaves the same on every board, whether it has a crystal or a resonator, and restarts faster when the chip wakes from power-down. Its accuracy is good enough for the 9600-baud telemetry link. Setting the fuses is therefore the only change needed. It also clears the board's bootloader setting; flashing is by ISP only (why ISP, not a USB-serial upload).

The firmware is built for the 8 MHz clock (PlatformIO board pro8MHzatmega328), so its PWM and serial timing are wrong until the fuses are set: garbled serial text is the giveaway.

### Test gates

The controller is proven on a current-limited bench supply in Gate 1, then on the protected battery in Gate 2 (10 – Commissioning). The printable controller bench sheet covers Gate 1.

### What can go wrong

Symptom | Likely cause
Programmer cannot see the chip | Wiring, pin 1 orientation, or no VCC
Signature 0x000000 or 0xffffff | No target power, or MISO/MOSI swapped
Signature 1E 95 16 | ATmega328PB: use -p m328pb
Serial text is garbage | Fuses not set: still on 16 MHz clock
High sleep current | Regulator or power LED still fitted
D9 PWM not ~1.96 kHz | Wrong clock (check the fuses)

Back to top

## 05 – Module C: low-power lighting

Drawing: sheet 2 (drawings/sheet-2.png). Wiring: nets PWM and LED_POS, plus JLED.- on GND_LOAD.

This module is a single resistor and a string of LEDs, which makes it the best place in the project to learn how LED current really works.

What you will learn: LED forward voltage, why a series resistor sets current, what PWM does and does not change, how much current a microcontroller pin can safely supply, and how to measure it.

Sheet 2 is shown under Module B.

### What kind of lights

This controller drives a low-power LED string directly by PWM from pin D9. There is no MOSFET or transistor between the pin and the lights, so the string must be one that is happy at 20 mA or less in total, from a 3–4.2 V supply, through a series resistor.

Suitable: small "fairy" or garden LED strings with a forward voltage around 2.5–3 V, or a handful of individual LEDs, each with its own resistor.

Not suitable: mains lights, 12 V garden lights, conventional or legacy light fittings, or any string that expects its own driver or battery box. For those, see the driver stage in 12 – Going further.

### How the current is set

An LED string behaves roughly like a fixed voltage drop. The reference string measured 2.56 V with almost no change across the battery range, so:

I = (VBAT − Vstring) / (R3 + Rpin)

Rpin is the ATmega328P's own output resistance, roughly 30 Ω at these currents (a typical datasheet characteristic, not a guaranteed value). With R3 = 47 Ω the model predicts:

Battery | R3 = 47 Ω | R3 = 56 Ω
4.20 V | 21 mA | 18 mA
3.70 V | 15 mA | 13 mA
3.40 V | 11 mA | 9 mA

These are predictions. Gate 1 measures the real current through the pin; the reference string's own characterisation is in reference/led-string-characterisation.md.

PWM switches D9 fully on and off about 1,960 times a second. The duty cycle sets the average current and the brightness; the peak current in each pulse is still set by R3 and the pin. That is why the firmware's NIGHT_DUTY_PCT is a brightness and energy setting, not a safety limit.

### Build steps

1. Fit R3 (47 Ω) on the carrier, at the controller end, from D9 to the LED output terminal. The outdoor cable should always be on the far side of the resistor.
2. Connect the LED string's positive lead to the R3 terminal and its negative lead to GND_LOAD.
3. If your string is made of parallel LEDs without their own resistors, it needs one resistor per branch; a single shared resistor does not balance them.

### Test gate

Gate 1 in 10 – Commissioning measures the string current at 3.40, 3.70 and 4.20 V at 100 % duty. If it exceeds 22 mA at 4.20 V, fit 56 Ω and measure again. Also confirm that R3 and the controller stay at room temperature, and that the string is dark with the controller unpowered and during reset.

### What can go wrong

Symptom | Likely cause
Very dim at 3.4 V | Expected: brightness tracks battery
Over 22 mA at 4.20 V | String Vf lower than reference: 56 Ω
Uneven brightness | Parallel LEDs sharing one resistor
Visible flicker on camera | 1.96 kHz PWM banding; normal to eye
Lights on while controller off | Wiring fault: D9 must be the only feed

Back to top

## 06 – Module D: light sensor and test button

Drawing: sheet 2 (drawings/sheet-2.png). Wiring: nets LDR_POWER, LDR_SENSE and TEST.

The light sensor decides when it is dusk and dawn; the button gives you a 60-second test at any time of day.

What you will learn: voltage dividers, ratiometric ADC readings, switching a sensor's supply from a GPIO pin to save power, hysteresis and debouncing, and pin-change interrupts.

Sheet 2 is shown under Module B.

### How the sensor works

D7 ──> LDR1 ──┬──> A1
              │
              R4 47 kΩ
              │
           GND_LOAD

The LDR's resistance rises in the dark. With R4 = 47 kΩ, A1 reads as a fraction of VCC:

A1 reading | Meaning | LDR resistance
Below 30 % | Dark | Above ~110 kΩ
30–60 % | In between (no change) | ~31–110 kΩ
Above 60 % | Light | Below ~31 kΩ

Because D7 and the ADC reference are both VCC, the reading does not depend on battery voltage. D7 is switched on for a few milliseconds per wake, so the divider draws nothing between readings. A reading must stay dark (or light) for 300 scheduler seconds – about 5.5 minutes on the reference board – before the controller changes state, and the gap between 30 % and 60 % stops it hunting at dusk.

The thresholds live in firmware/controller/include/config.h (LDR_DARK_RATIO, LDR_LIGHT_RATIO). R4 sets where they fall: a larger R4 makes the sensor call "dark" later (it needs a darker sky).

### Build steps

1. Wire D7 → LDR1 → A1, and A1 → R4 (47 kΩ) → GND_LOAD.
2. Mount the LDR where it sees the sky but not the LED string: the lights must never be able to convince the sensor it is daytime. A short tube or hood around the LDR helps. Check it at night: with the lights on, ldr= should rise by only a few percent and stay well below the light threshold (Gate 3, step 6). On the bench, a string near the LDR raised it by about 4.5 %.
3. Wire SW1 between D2 and GND_LOAD. The firmware enables D2's internal pull-up and a pin-change interrupt, so a press wakes the controller immediately.

### Test gate

Gate 3 in 10 – Commissioning: cover and uncover the LDR and confirm the transitions. Test darkness with a truly light-tight cover; a loose cap can still let through enough light to read about 20 %.

Calibrate in the final position. With Advanced Telemetry running, note the Arduino LDR value at the moment you would like the lights to come on. If it is well above 30 %, the lights will come on later than you want: raise LDR_DARK_RATIO in config.h (keeping LDR_LIGHT_RATIO about 0.3 above it), or fit a smaller R4. If the lights come on too early, do the opposite.

### What can go wrong

Symptom | Likely cause
Lights never come on | Dark reading stays above 30 %
Lights switch off soon after dusk | LEDs lighting the LDR
Lights on during the day | LDR shaded or covered
Button does nothing | Cut-off active, or D2 not to GND
Transition takes ~5.5 min | Normal: 300 s confirmation

Back to top

## 07 – Module E: telemetry hardware

Drawings: sheet 6 (Tier 1, drawings/sheet-6.png) and sheet 3 (Tier 2, drawings/sheet-3.png). Layouts: breadboard and perfboard, both showing JP1 and JP2. Wiring: nets UART_*, ESP_3V3, ADC_BATT and WAKE. Software: 09 – Home Assistant.

Telemetry is optional: skip this module for a standalone (Tier 0) build. It is strongly recommended while commissioning, because it turns the controller's diagnostics into live Home Assistant entities without a cable on the controller.

What you will learn: serial (UART) signalling, level shifting and inverting with a single transistor, buck-boost converters, ADC dividers, ESP8266 deep sleep and wake-on-reset, and keeping two power domains apart.

Sheet 6 – Tier 1 Advanced Telemetry · Full-size SVG · Printable PDF

Sheet 3 – Tier 2 Production Telemetry · Full-size SVG · Printable PDF

Perfboard layout – the whole system on a carrier · Full-size SVG

### One harness, two tiers

The same wiring serves both telemetry tiers. Only the D1 Mini's power source and the firmware change.

Connection | Tier 1 Advanced | Tier 2 Production
Controller D1/TX → Q2 → D6 | Fitted | Fitted
VBAT_SYS → R5 → A0 | Fitted | Fitted
D1 Mini G → GND_LOAD | Fitted | Fitted
D1 Mini power | Its own micro-USB | U3 OUT → 3V3 pin
U3 OUT → D1 Mini 3V3 | Disconnected | Connected
D0 → RST | Optional | Fitted
Controller firmware | advanced | production
ESPHome profile | Advanced | Production

Never power the D1 Mini from USB and U3 at the same time: its onboard regulator and U3 would both drive the 3V3 rail. Fit a jumper or a two-pin plug in U3 OUT so switching tiers is a clean, visible change.

### The serial receiver (Q2)

Controller D1/TX ── R8 47 kΩ ──┬── Q2 base (2N3904)
                               R9 100 kΩ
                               │
GND_LOAD ──────────────────────┴── Q2 emitter

D1 Mini 3V3 ── R10 10 kΩ ──┬── Q2 collector
                            └── D1 Mini D6

The controller's TX swings between 0 V and the battery voltage (up to 4.2 V), which is too high for the ESP8266's 3.3 V inputs. Q2 turns each TX high into a collector low at D1 Mini logic levels, and each TX low into a high through R10. The signal arrives inverted, so the ESPHome profiles declare D6 as inverted: true. The D1 Mini's TX is never connected: the link is receive-only and the D1 Mini cannot affect the controller.

R9 holds Q2 off whenever the controller's TX is low, released or unpowered. A serial line idles high, so with the advanced build Q2 conducts between lines (about 0.4 mA, mostly from the USB-powered D1 Mini). The production build enables its serial port only while sending and parks TX low in between, so in Tier 2 the link draws nothing between messages.

Check the transistor's pin order. 2N3904 and BC547-family parts come in different E-B-C orders depending on the maker. Confirm with a datasheet or a diode test before soldering.

### Battery sense

VBAT_SYS → R5 220 kΩ → A0. The D1 Mini already has a 220 kΩ/100 kΩ divider on A0, so the total ratio is about 5.4. Clone boards vary; calibrate the ESPHome multiplier against a meter in Gate 7.

### U3 – 3.3 V supply for Tier 2

The battery rail runs from 4.2 V down to about 3.0 V, crossing 3.3 V along the way. A buck-only regulator cannot hold 3.3 V below that; a buck-boost can. The TPS63802 breakout draws about 20–30 µA quiescent and handles the ESP8266's radio bursts comfortably.

1. Set the breakout's output jumper to 3.3 V and measure it before connecting anything.
2. Wire VIN to VBAT_SYS (with C2, 470 µF, close to VIN) and GND to GND_LOAD.
3. Take U3 OUT to a jumper or plug that goes to the D1 Mini 3V3 pin. Leave it open for Tier 1.

The D1 Mini's own regulator stays fitted; in Tier 2 it is simply unused because nothing feeds its 5V pin.

### Build steps

1. Build the Q2 receiver (Q2, R8, R9, R10) on the carrier near the D1 Mini.
2. Controller D1/TX → R8; Q2 collector → D1 Mini D6; R10 to D1 Mini 3V3.
3. R5 from VBAT_SYS to D1 Mini A0.
4. D1 Mini G to GND_LOAD (never to B-).
5. Fit U3 and C2; U3 OUT to the D1 Mini 3V3 pin through an open jumper.
6. Fit a removable link from D1 Mini D0 to RST (needed for Tier 2 deep-sleep wake; remove it when flashing the D1 Mini over USB).

Then flash the D1 Mini and set up Home Assistant: 09 – Home Assistant.

### Test gates

The receiver is exercised from Gate 1 onwards if you commission with Tier 1. Gate 7 covers A0 calibration and service outages; Gate 8 covers the switch to Tier 2 and its standby current (10 – Commissioning).

### What can go wrong

Symptom | Likely cause
No controller data in HA | Controller running standalone
Garbled or dropped lines | Q2 pin order, or grounds not common
Battery voltage wildly off | Multiplier not calibrated
D1 Mini resets on radio bursts | U3 output not 3.3 V, or C2 missing
D1 Mini never wakes (Tier 2) | D0 → RST link missing
Cannot flash D1 Mini over USB | D0 → RST link fitted: remove it

Back to top

## 08 – Controller firmware: build, fuses, flash and diagnostics

The controller firmware is in firmware/controller/. It is built with PlatformIO and flashed over ISP with a standalone copy of avrdude. The board has no bootloader, so there is no USB upload.

What you will learn: AVR fuses and ISP programming, PlatformIO build environments, low-power AVR techniques (power-down sleep, watchdog wake, pin-change interrupts, bandgap voltage measurement, hardware PWM), and testing embedded logic on a desktop computer.

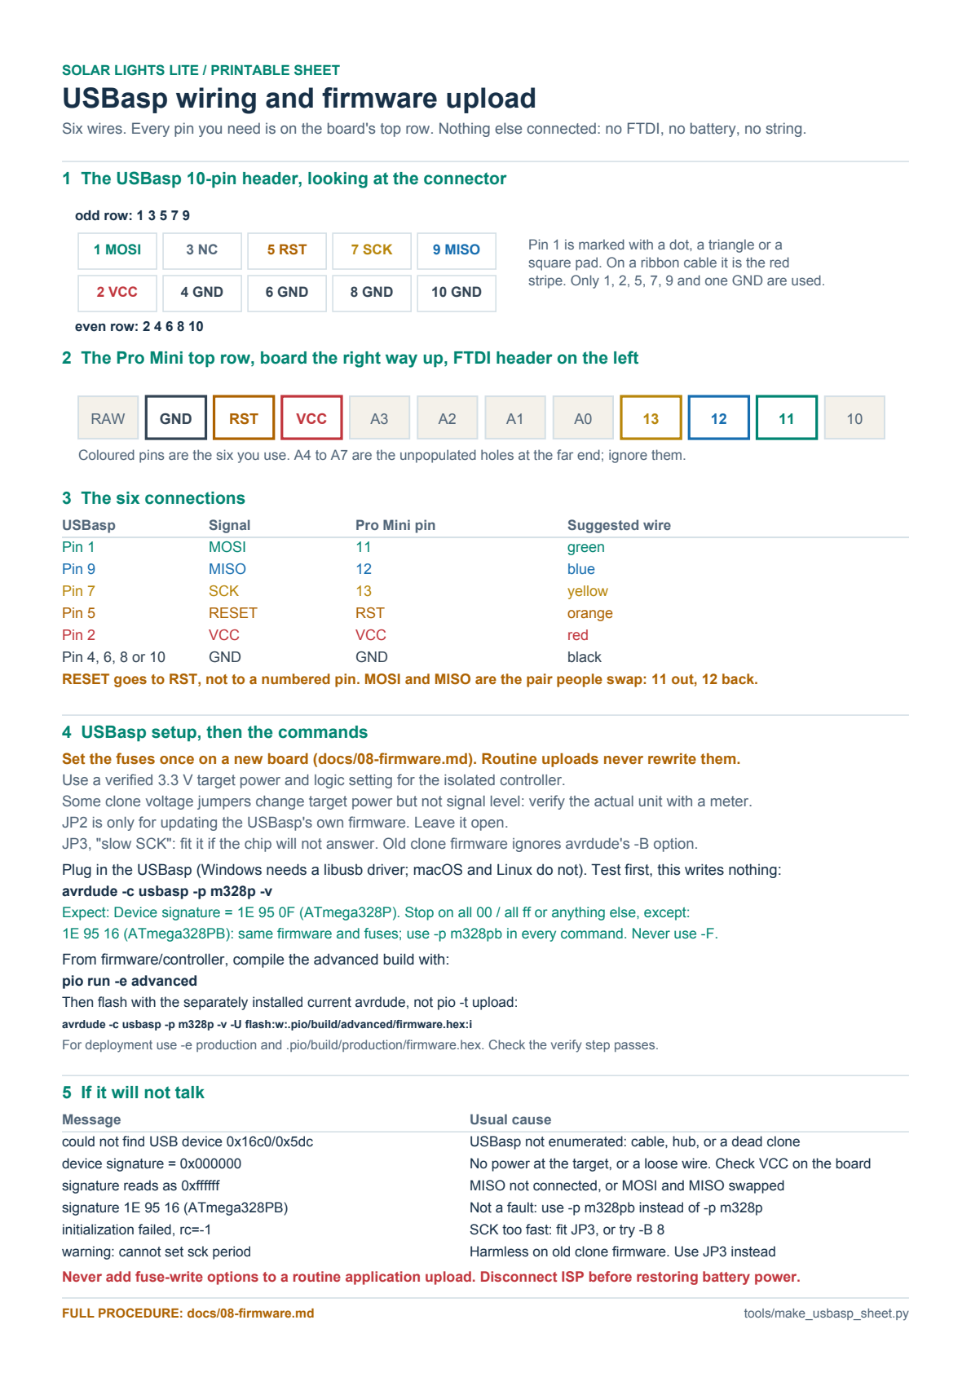
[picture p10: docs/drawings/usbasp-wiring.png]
USBasp wiring sheet


USBasp wiring sheet · Printable PDF

### Source layout

File | Purpose
include/config.h | Every tuneable value: pins, levels, timing
include/schedule.h | Hardware-free dusk-to-dawn scheduler
src/main.cpp | AVR layer: ADC, PWM, sleep, telemetry
test_host/regression.cpp | Scheduler tests that run on a computer
platformio.ini | One build environment per telemetry tier

### Build environments

Environment | Telemetry output | Use with
advanced | Banner, field guide, diagnostics | Tier 1, bench
production | Banner, then a compact line ~8 s | Tier 2
standalone | None; serial port powered down | Tier 0

All three run identical lighting logic. Commission with advanced; deploy with production (or standalone if you have no telemetry).

### Why ISP, not a USB-serial upload

An off-the-shelf Pro Mini is normally programmed through a USB-serial (FTDI) adapter and the Arduino bootloader. This build uses an ISP programmer (USBasp, or an Uno or Nano acting as one) instead, for these reasons.

ISP is needed at least once anyway. Switching the clock to the internal 8 MHz oscillator means rewriting the fuses (why 8 MHz). A bootloader cannot change fuses: only an ISP programmer (or a high-voltage programmer) can. There is no way to prepare a new board with an FTDI adapter alone.

The factory bootloader stops working after the fuse change. A 16 MHz Pro Mini's bootloader is built for its 16 MHz crystal. Once the chip runs at 8 MHz, the bootloader runs at half speed and talks at the wrong baud rate, so uploads fail. Serial uploads would need a new 8 MHz bootloader, and that also has to be written over ISP.

With the programmer already wired, ISP is the simpler route for updates. One tool and one command cover fuses, firmware and verification, and the chip has nothing extra installed:

- The firmware starts straight away. With no bootloader there is no start-up pause listening for an upload after a reset.
- The full 32 KB of flash is available, and the high fuse 0xD9 jumps straight to the firmware at reset.
- No auto-reset wiring is needed. Serial uploads need the adapter's DTR line connected to RST through a 100 nF capacitor. This build has no DTR connection, and D1/TX is already used by the telemetry link (module E).
- There is less risk of back-feeding the battery. A USB-serial adapter's VCC pin must never be connected while the battery powers the controller. For flashing, the programmer is the only power source, with the battery and everything else disconnected.

An FTDI adapter is still useful as a receive-only serial monitor (see Reading the diagnostics): connect controller TX to adapter RX, and GND to GND, only.

Serial uploads are possible, but not supported. If you want to use them, use ISP to write an 8 MHz internal-oscillator bootloader and the high fuse it requires, then add the DTR reset circuit. The project's instructions, troubleshooting and fuse values all assume no bootloader, so you would be on your own.

### Install the tools

1. PlatformIO. Install the PlatformIO extension for VS Code, or PlatformIO Core (installation guide (https://docs.platformio.org/en/latest/core/installation/)). Check pio --version in the PlatformIO terminal.
2. avrdude, version 7 or later, installed separately. PlatformIO bundles an older avrdude that is not reliable with this setup, so do not use pio run -t upload. - macOS: brew install avrdude - Linux: your distribution's avrdude package, if it is version 7 or later; otherwise build or download it from the AVRDUDE project (https://github.com/avrdudes/avrdude/releases). - Windows: download the release from the AVRDUDE project (https://github.com/avrdudes/avrdude/releases), extract the whole folder (including avrdude.conf) and add it to PATH. A USBasp also needs a libusb driver (for example installed with Zadig).
3. Check avrdude --version in the same terminal you will flash from.

### Wire the programmer

Disconnect the battery, panel, LED string, telemetry and any USB-UART adapter first. The controller must have exactly one power source: the programmer.

USBasp 10-pin | Signal | Pro Mini
1 | MOSI | 11
2 | VCC | VCC
5 | RESET | RST
7 | SCK | 13
9 | MISO | 12
4, 6, 8 or 10 | GND | GND

Set the USBasp to 3.3 V and confirm with a meter: some clones switch target power but not logic level. Printable sheets: USBasp wiring and the board map.

### One-time preparation of a new board

Run these from any folder. None of them are needed again for routine updates.

1. Read the signature (writes nothing):

avrdude -c usbasp -p m328p -v

The signature tells you which chip is on the board, and that decides the -p part name for every avrdude command that follows:

Signature | Chip | Use in every command
1E 95 0F | ATmega328P | -p m328p (as shown)
1E 95 16 | ATmega328PB | -p m328pb

Stop if it reads anything else, or all 00 or all ff (see Troubleshooting).

Many recent Pro Mini clones, including some sold as "ATmega328P", carry the newer ATmega328PB. With -p m328p, avrdude reports Device signature = 1E 95 16 (ATmega328PB) and refuses to continue. This does not mean the board is faulty. Repeat the command with -p m328pb, and use that in every later command. Do not use -F to force past the check: it switches off avrdude's check that it is talking to the chip you expect, for this command and any you copy it into.

The 328PB is designed as a drop-in replacement for the 328P and runs the same firmware. The PlatformIO build (board pro8MHzatmega328) is unchanged, and so are the fuse values below. The 328PB's extra peripherals and its extra clock-failure fuse bit stay unused: the extended fuse 0xFD leaves that bit unprogrammed, so the feature is off.

2. Save the existing fuses, in case you ever want the board back as it was. A new 16 MHz Pro Mini normally reads low 0xFF, high 0xDA, extended 0xFD; write down what yours shows.

avrdude -c usbasp -p m328p -U lfuse:r:-:h -U hfuse:r:-:h -U efuse:r:-:h

3. Write the Solar Lights fuses:

avrdude -c usbasp -p m328p -U lfuse:w:0xE2:m -U hfuse:w:0xD9:m -U efuse:w:0xFD:m

Fuse | Value | Effect
Low | 0xE2 | Internal 8 MHz RC oscillator, no clock ÷8
High | 0xD9 | Start at address 0 (no bootloader), ISP kept
Extended | 0xFD | Brown-out reset at 2.7 V

Fuses are persistent configuration bits, separate from the program. Type the values carefully: a wrong clock-source value can leave the chip needing an external clock or a high-voltage programmer to recover. Some avrdude versions show the extended fuse as 0x05; that is the same setting with the unused bits hidden.

The first firmware flash erases the chip, which also removes any Arduino bootloader. The board will no longer accept serial uploads; that is expected.

### Build and flash

From firmware/controller:

pio run -e advanced

The build must end in SUCCESS and produce .pio/build/advanced/firmware.hex. Then flash it:

avrdude -c usbasp -p m328p -v -U flash:w:.pio/build/advanced/firmware.hex:i

(On an ATmega328PB, -p m328pb.) Success needs both the write and the verify to pass. Unplug the programmer and remove all six ISP wires before reconnecting normal power. Next, do the first power-up check (04 – Controller, step 3).

For deployment, build and flash production (or standalone) the same way, replacing advanced in both commands. Routine updates never write fuses.

#### Arduino as ISP (fallback)

If you have no USBasp, an Uno or Nano can act as the programmer:

1. Upload the ArduinoISP example sketch to it.
2. Fit a 10 µF capacitor from its RESET to GND (stops it auto-resetting).
3. Wire programmer D11 → target 11, D12 → 12, D13 → 13, D10 → target RST, plus VCC and GND. A 5 V Uno drives 5 V logic, so power the target from the Uno's 5 V pin: that is within the ATmega328P's rating only while the controller is isolated from the battery rail, LDR, LED string and D1 Mini.
4. Replace -c usbasp with -c stk500v1 -P <port> -b 19200 in every command, for example -P /dev/ttyACM0, -P /dev/cu.usbmodem1101 or -P COM5. Do not add -B; the stock sketch ignores it.

### Reading the diagnostics

At every reset, the advanced and production builds print a banner with the firmware version, the date and time it was built, the telemetry profile and the clock setting. Check it after flashing: it confirms the board is running the build you just made.

==================================================
 Solar Lights Lite  -  dusk-to-dawn controller
 Firmware   v0.6.0   built 05-Oct-2026 13:26
 Telemetry  advanced: full diagnostics, 9600 baud
 Clock      internal 8 MHz, brown-out 2.7 V
==================================================

The advanced build then lists its active settings (LDR thresholds, battery levels, night duty) and a field guide to the line keys, ending with Live diagnostics. After that it prints a line whenever something changes, every 10 s while a transition, test or cut-off is being timed, and every 60 s otherwise. The production build prints a shorter line every 8 scheduler seconds. None of the reset text starts with fw=, so the ESPHome profiles ignore it. The build date comes from the compiler, so it changes every time you build.

Two ways to read it:

- Tier 1 Advanced Telemetry (recommended): the D1 Mini decodes every line into Home Assistant (09 – Home Assistant).
- A 3.3 V USB-UART adapter: connect only controller TX → adapter RX and GND → adapter GND; leave the adapter's VCC, TX, DTR and CTS open (sheet 5). Then run pio device monitor --baud 9600 from firmware/controller.

The one exception is the first power-up check straight after flashing (04 – Controller, step 3). There, the adapter's 3.3 V VCC powers the bare board through the serial header, with the programmer and everything else disconnected. Never use the adapter's 5 V setting, and never connect its VCC while any other source powers the controller.

#### Line format

Every line is space-separated key=value pairs starting with fw=. Both ESPHome profiles parse these keys; if you rename one, update both YAML files.

Key | Example | Meaning
fw | 0.6.0 | Firmware version (config.h)
time | 1234s | Scheduler seconds since reset
vdd | 3.912V | Controller supply (= battery rail)
battery | OK | Band: OK, MID, LOW, CRITICAL
ldr | 12.4% | A1 as a percentage of VCC
sense | DARK | DARK, MID or LIGHT
mode | NIGHT | DAY, NIGHT or LVC (cut-off)
night | YES | Dusk confirmed, dawn not yet
output | 100% | D9 PWM duty
cause | DUSK_TO_DAWN | Why the output has its value
raw | 127 | A1 ADC count (advanced only)
ldr_v | 0.485V | A1 volts (advanced only)
confirm | DUSK 40/300s | Transition progress (advanced only)
lvc | 0/30s | Time below cut-off (advanced only)
button | 59s | Test time left (advanced only)
next_tick | 1s | Next watchdog interval (advanced only)

cause | Meaning
STARTUP_TEST | 10 s flash after reset
BUTTON_TEST | 60 s test after a D2 press
DAY_OFF | Daylight, lights off
FADE_TO_DAY_OFF | Dawn confirmed, fading out
DUSK_TO_DAWN | Night, full night level
LOW_BATT_NIGHT | Night, below 3.45 V: level halved
LOW_VOLT_BLOCK | Test refused: supply below cut-off
LVC_OFF | Low-voltage cut-off active

### Tuning and calibration

All settings are in include/config.h. The ones you are most likely to change:

Setting | Default | Effect
NIGHT_DUTY_PCT | 100 | Night brightness and energy use
LDR_DARK_RATIO | 0.30 | Dusk threshold (A1 fraction)
LDR_LIGHT_RATIO | 0.60 | Dawn threshold (A1 fraction)
LOW_BATT_V | 3.45 | Below this, night level halves
LVC_OFF_V | 3.30 | Cut-off voltage (after 30 s)
LVC_RESUME_V | 3.60 | Recovery voltage (in daylight)
BANDGAP_V | 1.10 | Supply measurement calibration
TIME_SCALE | 1 | Bench only: 60 runs time 60× faster

Calibrate the supply reading once per board, in Gate 1: power the controller from a bench supply at about 3.8 V, compare vdd with a meter, set BANDGAP_V = 1.10 × Vmeter / Vreported, then rebuild and reflash. The thresholds above all depend on this reading.

### Host tests

The scheduler has no hardware dependencies, so its behaviour is tested on any computer with a C++17 compiler. From firmware/controller/test_host:

c++ -std=c++17 -Wall -Wextra -Werror -I../include regression.cpp -o regression && ./regression

It must print PASS. The tests cover dusk/dawn confirmation, a 14-hour night, test-level caps, cut-off and recovery, low-battery dimming, slow ticks and the shipped defaults. They do not test registers, ADC settling, sleep current or wiring: that is what commissioning is for.

### Troubleshooting

Symptom | Meaning / action
pio: command not found | Use the PlatformIO terminal
Bad CPU type on an Apple-silicon Mac | AVR toolchain needs Rosetta 2
avrdude path contains .platformio | Wrong avrdude: use the standalone one
cannot set sck period | Old USBasp firmware: fit slow-SCK jumper
target does not answer | Pin 1, MOSI/MISO, RST, VCC, slow SCK
Signature 1E 95 16 (ATmega328PB) | 328PB chip: use -p m328pb, not -F
Any other signature | Wrong chip or wiring: stop
vdd= about 5 V on the bench | Fed from a 5 V pin or jumper: use 3.3 V
Verification mismatch | Check avrdude version, retry once
Serial text unreadable | Fuses not set (still 16 MHz)
No serial output at all | standalone build, or TX/GND wiring

Back to top

## 09 – Home Assistant and ESPHome telemetry

Files: firmware/esphome/ (D1 Mini profiles) and homeassistant/ (package and dashboards). Hardware: 07 – Module E: telemetry hardware.

The lights run without any of this. Telemetry lets you watch the controller work, calibrate it, prove it over a two-week soak, and then keep an eye on it in service.

What you will learn: ESPHome configuration and secrets, parsing a serial protocol in an ESPHome lambda, deep sleep with an OTA escape hatch, Home Assistant packages, helpers, automations and sections dashboards.

### The tiers

Tier | Controller build | ESPHome profile | D1 Mini power
0 | standalone | None | –
1 | advanced | solar-lights-advanced-telemetry.yaml | Micro-USB
2 | production | solar-lights-production-telemetry.yaml | U3 (battery)

Tier 1 – Advanced Telemetry is the commissioning instrument. The D1 Mini stays awake and publishes every field of every diagnostic line, plus its own Wi-Fi, heap and uptime. It keeps receiving if Wi-Fi or Home Assistant go down, and serves its own web page at http://<D1 IP address>/. It draws around 70–80 mA continuously, which is why it runs from USB and is never part of the battery budget.

Tier 2 – Production Telemetry is for the finished installation. Once an hour the D1 Mini wakes, waits up to 20 s for a status line from the controller, reads the battery voltage, reports, and goes back to deep sleep. Its average draw is well under 1 mA.

Both profiles use the same device name (solar-lights), entity names and encryption key, so moving from Tier 1 to Tier 2 keeps your Home Assistant history and the same entity IDs.

### 1. Install ESPHome

Use either the ESPHome Device Builder add-on in Home Assistant (Settings → Add-ons) or the ESPHome command-line tool. The profiles need ESPHome 2024.11 or later.

### 2. Add the secrets

In the ESPHome secrets.yaml (never in this repository):

Key | Used for
wifi_ssid | Your Wi-Fi network
wifi_password | Your Wi-Fi password
esphome_encryption_key | API key (ESPHome can generate one)
ota_password | Over-the-air update password
ap_password | Tier 1 fallback hotspot (8+ characters)

### 3. Flash the D1 Mini (Tier 1)

1. Remove the D0 → RST link while flashing over USB.
2. In the ESPHome dashboard create a device, then replace its YAML with solar-lights-advanced-telemetry.yaml. Keep name: solar-lights: the dashboards' entity IDs depend on it.
3. Validate, then Install over USB the first time. Later updates can go over Wi-Fi.
4. Adopt the device in Home Assistant (Settings → Devices & services).
5. Flash the controller with the advanced build (08 – Firmware).

Within about a minute, Arduino Diagnostics Fresh turns on and Arduino Diagnostic Line shows a complete line starting fw=.

### 4. Install the Home Assistant package

homeassistant/solar_lights_package.yaml adds:

- input_boolean.solar_lights_ota, the helper Tier 2 uses to stay awake for updates;
- three example automations: battery low, low-voltage cut-off, and reports stopped. They use persistent notifications, so they work without a phone app.

Enable packages once in configuration.yaml:

homeassistant:
  packages: !include_dir_named packages

Copy the file to /config/packages/, check the configuration (Developer tools → YAML) and restart Home Assistant.

### 5. Import a dashboard

Create a dashboard (Settings → Dashboards → Add dashboard), open it, choose Edit dashboard → Raw configuration editor, and paste one of:

Dashboard | Use
dashboard-advanced-telemetry.yaml | Tier 1: commissioning and soak test
dashboard-production-telemetry.yaml | Tier 2: day-to-day and 7-day trends

Both use built-in cards only. If Home Assistant assigned different entity IDs, find-and-replace solar_lights_ before saving.

### Moving from Tier 1 to Tier 2

Do this only after the soak test (Gate 7) has passed.

1. Flash the controller with the production build.
2. With the D1 Mini still on USB, install solar-lights-production-telemetry.yaml over Wi-Fi.
3. Unplug USB. Close the U3 OUT → 3V3 jumper. Fit the D0 → RST link.
4. Watch for the first hourly report; then complete Gate 8.

To go back to Tier 1 (for example to recalibrate), reverse the steps: open the U3 jumper before plugging in USB.

#### Updating a sleeping D1 Mini (Tier 2)

Turn on Solar Lights stay awake for OTA (input_boolean.solar_lights_ota). At its next wake the D1 Mini stays awake; install the update, then turn the helper off and it resumes its hourly sleep. To reach it sooner, press its reset button.

### Entities

Entity (name in ESPHome) | Tier 1 | Tier 2 | Notes
Battery Voltage / Battery Level | ✓ | ✓ | D1 Mini A0, calibrated
Arduino VDD | ✓ | ✓ | Controller's own reading
Arduino Mode / Night / Output Cause | ✓ | ✓ | Scheduler state
Arduino Light Duty / Lights Commanded | ✓ | ✓ | D9 PWM duty
Arduino LDR / Light Sense | ✓ | ✓ | Light sensor
Arduino Battery Band / Firmware | ✓ | ✓
Arduino Diagnostic Line | ✓ | ✓ | Latest raw line
Arduino Diagnostics Fresh | ✓ | ✓ | Tier 2: line this wake
Arduino LDR Raw / LDR Voltage | ✓ | | Advanced detail
Arduino Transition Confirmation | ✓ | | Dusk/dawn progress
Arduino LVC Elapsed / Button Test | ✓ | | Timers
D1 WiFi Signal | ✓ | ✓
D1 Status, IP, SSID, uptime, heap | ✓ | | Receiver health

Telemetry reports what the controller measures and decides. It does not measure panel voltage, charge or load current, energy or temperature; use a meter or power profiler for those.

### Calibrating the battery reading

In Gate 7, compare Battery Voltage with a meter across VBAT_SYS and GND at a few battery levels. Set the multiplier in both profiles:

new multiplier = old multiplier × meter volts / reported volts

The nominal value is 5.4 (R5 220 kΩ plus the D1 Mini's 220 kΩ/100 kΩ divider); the reference build calibrated to 5.21. Arduino VDD is a useful cross-check, since it measures the same rail independently.

### Troubleshooting

Symptom | Check
Diagnostics Fresh stays off | Controller build, Q2 wiring, grounds
Dropped corrupted UART line warnings | Q2 pin order, shared GND_LOAD
Home Assistant asks for the key again | Encryption key changed between profiles
Tier 2 device never reports | D0 → RST link, U3 jumper, Wi-Fi reach
Tier 2 stays awake | OTA helper still on
Entities unavailable in Tier 1 | D1 Mini USB power or Wi-Fi

Back to top

## 10 – Commissioning: test gates and final assembly

Never assemble everything and switch on for the first time. Each gate below adds one thing, tests it, and must pass before the next. The order is chosen so that a mistake costs a resistor, not a battery.

What you will learn: staged power-up, measuring current in circuit, calibration, and how to decide from evidence that something is ready.

Record your results as you go (a template is at the end). Sheet 5 (drawings/sheet-5.png) shows gates 1–7 as a ribbon, and the printable controller bench sheet covers Gate 1.

A note on time: the controller's clock is its watchdog oscillator, which is uncalibrated and varies by chip, typically 10–20 % slow. A "300 s" confirmation therefore takes about 5.5–6 real minutes. That is normal.

Sheet 5 – Staged power-up and wired serial monitor · Full-size SVG · Printable PDF

Sheet 4 – Enclosure and physical assembly · Full-size SVG · Printable PDF

### Gate 0 – Inspection, power off

- Pad labels identified on M1: IN+, IN-, B+, B-, OUT+, OUT-.
- Controller regulator and power LED removed; no short between VCC and GND.
- No external link between B- and OUT-; S1 open; fuses fitted.
- Every connector labelled (colour scheme on sheet 4).

Pass: no continuity from VBAT_SYS to GND_LOAD; battery and panel still disconnected.

### Gate 1 – Controller on a bench supply

Set up: controller fuses set, advanced build flashed and the first power-up check passed (04 – Controller). Regulator and power LED removed (Gate 0). Current-limited bench supply (200 mA limit) at 3.80 V to VCC/GND, the only power source; any USB-UART adapter is connected TX → RX and GND only. LED string on R3. Button and LDR fitted. Diagnostics via Tier 1 or a USB-UART adapter.

Check | Expect
Reset | Banner (version, build date), then fw=
vdd vs meter | Within 0.05 V after BANDGAP_V calibration
D9 PWM frequency | 1.9–2.0 kHz (confirms 8 MHz clock)
Press D2 | cause=BUTTON_TEST output=100%
LED current, 3.40 V | About 11 mA (record actual)
LED current, 3.70 V | About 15 mA (record actual)
LED current, 4.20 V | About 21 mA; over 22 mA → fit 56 Ω
Controller unpowered / reset | String dark

Measure LED current with a meter in series with the string positive, lights at 100 % (press D2).

Pass: calibrated supply reading, correct clock, LED current within the pin's 20 mA working rating (or R3 changed), nothing warm.

### Gate 2 – Protected battery

Power down. Connect one suitable cell to M1 B+/B-. With S1 open, meter OUT+/OUT-: correct polarity, roughly the cell voltage. Close S1.

Pass: the controller runs from OUT+/OUT- only; vdd still matches the meter; the D2 test works; no unexplained current or heat.

### Gate 3 – Light sensor and timing

1. In daylight or room light, confirm sense=LIGHT and next_tick=8s.
2. Cover the LDR with a light-tight cover. sense=DARK, ticks change to 1 s, confirm=DUSK n/300s counts up.
3. After 300 scheduler seconds: mode=NIGHT, output fades up at 2 % per second to the night level.
4. Uncover for 300 s: mode=DAY, output fades to 0.
5. Brief shadows or a torch flash must not cause a transition.
6. At night with the lights on, note ldr=, then switch the string off (or cover it) and note it again. The lights' own contribution should be a few percent at most, and the lit reading must stay well below the light threshold (60 %). Otherwise the lights can end their own night: shade the LDR from the string (guide 06).

An indoor bench sees room lights: a lamp switched on near the LDR can end the night early or delay dusk. Treat dusk and dawn times as meaningful only outdoors, in the final position.

Pass: clean transitions, no flicker around the thresholds; the lit reading stays well below the light threshold. Final threshold calibration happens in the real location during Gate 7.

### Gate 4 – Low-voltage behaviour (bench supply)

Return to the bench supply; never deliberately over-discharge a cell. Cover the LDR to reach night mode, then:

Step | Expect
Lower VCC to 3.40 V | Output settles at half the night level
Lower VCC to 3.25 V for 30 s | mode=LVC output=0%, immediately off
Press D2 | Lights stay off (LVC_OFF)
Raise to 3.80 V, still dark | Still off
Uncover the LDR for 300 s | mode=DAY; normal again

Pass: cut-off, button lockout and daylight-only recovery all behave as above.

### Gate 5 – Charger input and charge current

Test the charger from a current-limited bench supply before the panel is connected.

- Option B only: with U0's output disconnected, feed its input from the bench supply and adjust it to 5.00 V. Check it at no load and under load, and at the highest input voltage you expect from the panel. With the input disconnected, check it does not draw current back from its output (night-time reverse leakage).
- Charge current: with a partly discharged cell on B+/B-, supply 5.0 V to M1 IN. Measure current into B+. It should match the PROG setting (100–150 mA).
- Termination: charge to completion with the controller connected. The cell should finish at 4.15–4.20 V and current should taper off.
- Temperature: module and cell stay comfortably warm at most.

Pass: correct input voltage, charge current as set, termination near 4.2 V with the load connected, acceptable temperatures. A charger LED alone is not a pass.

### Gate 6 – Solar panel

Power down, then connect the panel (Option A to M1 IN, Option B to U0 IN).

- In full sun, measure panel voltage, M1 input voltage and charge current.
- Shade the panel, then unshade it: charging must resume on its own.
- At night, check that no current flows from the battery back towards the panel.

Pass: charging in sun, automatic recovery from shade, no night-time drain, nothing hot.

### Module F – Final assembly

With gates 0–6 passed, move everything into the enclosure (sheet 4):

- Socket every module so it can be replaced. Keep cells in an insulated holder, shaded, and away from the charger module and R3.
- Separate the D1 Mini's antenna from the cells, wiring and any metal.
- Mount the LDR where it sees the sky and cannot see the LED string.
- Use cable glands for the panel, LED string and LDR, with strain relief.
- Assemble the pack with both matched, fused cells (Gate 2 used one).
- Leave the lid off, or easy to open, until Gate 7 has passed.

### Gate 7 – Soak test with Advanced Telemetry (14 days)

Run the complete system in its real location with Tier 1 telemetry and the Advanced dashboard for at least 14 days, including overcast weather.

Before starting:

- Calibrate the D1 Mini's battery reading at three voltages (09 – Home Assistant).
- Calibrate the LDR thresholds in place (06 – Sensor).
- Turn Wi-Fi off, then Home Assistant off: the D1 Mini keeps receiving and reconnects afterwards. Install an OTA update: the controller link survives.

During the soak, watch:

- Battery voltage at dawn each day: it must not trend down day after day.
- Dusk and dawn times: sensible, no flicker, no daytime switching.
- No LVC events, no unexplained resets (Arduino Scheduler Time restarting).

Pass: no progressive energy deficit, no cut-off events, no reset loops, no unsafe temperatures. If the battery trends down, lower NIGHT_DUTY_PCT, improve the panel position or size, and repeat.

### Gate 8 – Production switch-over

1. Flash the controller with production (or standalone).
2. Move the D1 Mini to Tier 2 (09 – Home Assistant).
3. Measure the whole system's current from the battery in daylight, between D1 Mini wakes. Planning targets: controller about 20 µA or less; U3 and the sleeping D1 Mini together 0.5 mA or less.
4. Confirm hourly reports arrive and the lights still run dusk to dawn.

Pass: standby current within your energy budget; reports arriving; lights unaffected.

### Production readiness checklist

- Gates 0–8 passed and recorded
- LED current measured in circuit at 4.20 V (≤ 22 mA)
- Charge current and termination measured with the load connected
- 14-day soak with no downward battery trend
- LDR thresholds calibrated in the final position
- Enclosure sealed, glands tight, cells insulated and shaded
- Cold-weather charging risk addressed for your climate (Known limitations)
- Production firmware and profile installed; tier jumpers correct

### Results template

Gate | Date | Key measurements | Pass?
0
1 | | vdd cal; I at 3.4/3.7/4.2 V
2
3 | | Dark / light readings
4
5 | | Charge mA; end voltage
6 | | Sun mA; night leakage
7 | | Dawn voltage trend
8 | | Standby µA

Back to top

## 11 – Operation and maintenance

Once commissioned, Solar Lights Lite needs no attention day to day. This page describes normal behaviour, what the button and telemetry tell you, routine care, and how to diagnose problems.

### A normal day

When | What happens
Power-on or reset | 10 s flash (self-test)
Daytime | Lights off; controller wakes every 8 s
Dusk | ~5.5 min of darkness, then a slow fade up
Night | Lights on at the night level
Battery below 3.45 V | Night level halves
Dawn | ~5.5 min of light, then a slow fade off
Battery below 3.30 V | Lights off until daylight and > 3.60 V

Brightness falls gently through a long night as the battery voltage drops. This is by design: the LED string is driven directly, so its current follows the battery.

### The test button

Press the button at any time to run the lights at the night level for 60 seconds – useful for checking the string in daylight. The button does nothing while the low-voltage cut-off is active, which is itself a useful signal: if a press gives no light, the battery is too low.

### What telemetry tells you

Tier | Where to look | Look for
0 | The lights themselves | On at dusk, off at dawn
1 | Advanced dashboard | Live state, every change
2 | Production dashboard (hourly) | Battery trend over days

The most useful single view is battery voltage at dawn over a week or more. A steady or rising trend means the panel is keeping up; a falling one means the system is in deficit (see Seasonal care).

### Routine care

Interval | Task
Monthly | Clean the panel; clear leaves and shade
Each season | Check dawn battery trend; adjust brightness
Twice a year | Check glands, seals and for condensation
Yearly | Inspect cells, holder, fuses, connections
After a storm | Check the panel mount and the LED cable

### Seasonal care

Winter brings shorter days, longer nights and weaker sun, so the same panel harvests less while the lights use more. If the dawn battery voltage trends down:

1. Clean and re-aim the panel (steeper tilt for winter).
2. Lower NIGHT_DUTY_PCT in firmware/controller/include/config.h (for example to 60) and reflash.
3. Consider a larger panel (check its Voc against Option A/B in 03 – Power).

Remember the charger cannot sense cell temperature: in freezing weather see Known limitations.

### Troubleshooting

Symptom | Check first
Lights never come on | S1, fuses, cut-off; LDR seeing a light
Lights come on too late or early | Recalibrate LDR thresholds (doc 06)
Lights on during the day | LDR shaded, covered or dirty
Lights flicker at dusk | LDR too close to the LED string
Very dim all night | Battery low: check dawn voltage trend
Off before dawn most nights | Energy deficit: see Seasonal care
Button gives no light | Low-voltage cut-off active
No Tier 2 reports | D1 Mini power (U3), D0 → RST, Wi-Fi
Tier 2 D1 Mini awake all the time | OTA helper left on
Battery voltage reads wrong in HA | Recalibrate the A0 multiplier (doc 09)

If a problem is not obvious, put the system back into Tier 1: reflash the controller with advanced, run the D1 Mini on USB with the Advanced profile (open the U3 jumper first), and watch every decision the controller makes. That is exactly what Advanced Telemetry is for.

Back to top

## 12 – Going further

Solar Lights Lite is deliberately small. These are the natural next steps, each a project in its own right. None of them is needed for the design as documented, and each changes the energy budget and the commissioning work.

### Brighter lights: add a driver stage

The controller pin can supply about 20 mA. For a brighter string, D9 must drive a switch that carries the LED current:

- Logic-level MOSFET with its on-resistance specified at 2.5 V gate drive (for example AO3400A on a breakout). "Logic level" on its own is not enough: at 3.0–3.3 V many such parts, including the 2N7000, are only partly on at LED currents.
- NPN transistor such as a BC337, with a base resistor sized for forced saturation (base current about a tenth of collector current).

A driver stage also needs a gate or base resistor, a pull-down so the lights stay off at reset, a current-limiting resistor per LED branch, and a fuse in the LED branch, because the string is then fed from the battery rail rather than through the pin. Re-run the energy budget: a 200 mA string for 14 hours needs 2,800 mAh a night, far beyond a 1–2 W panel.

### Better charging

- Cell-temperature protection. Add a thermistor on the cells and a charger (or cut-off circuit) that stops charging below 0 °C and above about 45 °C. This is the main requirement for unattended use in cold climates.
- Power-path charging. Chargers such as the TI BQ24074 or Microchip MCP73871 supply the load and charge the battery separately, and regulate the input to suit a solar panel. They are not pin-compatible with TP4056 modules and come in small packages, so they suit a custom PCB.

### Measuring energy

The telemetry reports controller state, not energy. An INA219 or INA226 current monitor on the battery lead (read by the D1 Mini over I²C) would add charge current, load current and daily mAh in and out – turning the soak test into a true energy balance.

### Time-based schedules

The dusk-to-dawn design deliberately avoids clocks. An "evening and pre-dawn only" schedule would need real time: a DS3231 RTC on the controller, or a time sync from the D1 Mini. Watch the added standby current.

### A carrier PCB

Once your modules are fixed, a two-layer carrier board can replace perfboard: sockets for the Pro Mini and D1 Mini, screw terminals, fuse holders, labelled rails, test points and footprints for the Q2 interface. Keep the ESP8266 antenna at the board edge, and keep LED return current away from the LDR and ADC ground. The KiCad schematic in hardware/kicad/ is the starting point; it needs footprints and a layout.

### Lower-power telemetry

An ESP32-C3 or similar module has a much lower deep-sleep current than an ESP8266 D1 Mini and can run directly from a 3.3 V buck-boost. The serial protocol and Home Assistant side would stay the same.

Back to top

## Wire schedule

Every terminal in a row belongs to the same external net. Read the actual module pad labels and transistor pin order before soldering. CSV checklist · Wiring model (JSON)

Net | Connect these terminals together | Notes
PV_POS | PV1.+; U0.IN+ | Option A panels: PV1 + connects straight to M1 IN+ (no U0)
PV_RETURN | PV1.-; U0.IN- | Option A panels: PV1 - connects straight to M1 IN-
CHARGE_5V | U0.OUT+; M1.IN+
CHARGE_RETURN | U0.OUT-; M1.IN-
CELL1_POS | BT1.+; FB1.1
CELL2_POS | BT2.+; FB2.1
PACK_POS | FB1.2; FB2.2; M1.B+
PACK_NEG | BT1.-; BT2.-; M1.B- | NO bridge to OUT- / GND_LOAD
PROTECTED_POS | M1.OUT+; F2.1
FUSED_POS | F2.2; S1.1
VBAT_SYS | S1.2; M2.VCC; C3.+; C4.1; U3.VIN; C2.+; R5.1
GND_LOAD | M1.OUT-; M2.GND; C3.-; C4.2; JLED.-; R4.2; SW1.2; U3.GND; C2.-; M3.G; Q2.E; R9.2
PWM | M2.D9; R3.1
LED_POS | R3.2; JLED.+
LDR_POWER | M2.D7; LDR1.1
LDR_SENSE | LDR1.2; R4.1; M2.A1
TEST | M2.D2; SW1.1
UART_TX | M2.D1/TX; R8.1
UART_BASE | R8.2; R9.1; Q2.B
UART_RX_INVERTED | Q2.C; R10.2; M3.D6
ESP_3V3 | U3.VOUT; M3.3V3; R10.1 | Tier 2 only; in Tier 1 the D1 Mini runs from USB and U3 VOUT is open
ADC_BATT | R5.2; M3.A0
WAKE | M3.D0; M3.RST | Tier 2 deep-sleep wake

Back to top

## Parts checklist

CSV checklist with a "have it?" column for printing.

Module | Ref | Part / value | Qty | Notes
A | PV1 | Solar panel ~1-2 W (reference: AS102-0712A 1.2 W) | 1 | Measure open-circuit voltage (Voc) cold and in full sun to choose Option A or B
A | U0 | 5 V buck module (e.g. MP1584EN) | 1 | Option B panels only (Voc above 6.5 V). Set to 5.00 V and check reverse leakage before connecting M1. Not a linear regulator; not the TPS63802
A | M1 | Protected TP4056-family charger module (TP4056/TC4056 + DW01A + 8205A) | 1 | Six labelled pads IN+/IN-/B+/B-/OUT+/OUT-. Change PROG for 100-150 mA charge
A | BT1 / BT2 | 18650 Li-ion cell | 2 | Matched type/age/capacity/state of charge; 1S2P; or one protected 1S2P pack
A | - | Insulated 2-cell parallel holder | 1 | No soldering to bare cell cans
A | FB1 / FB2 | 1 A fuse and holder | 2 | One per cell positive lead before the parallel junction
A | F2 | 1 A fuse and holder | 1 | In series after M1 OUT+
A | S1 | SPST service switch | 1 | After F2; breaks the protected rail
B | M2 | ATmega328P Pro Mini-class board (reference: BTE13-010A) | 1 | Remove regulator and power LED; set fuses for internal 8 MHz; flashed over ISP
B | C3 | 100 uF electrolytic 10 V | 1 | Across M2 VCC/GND
B | C4 | 100 nF ceramic | 1 | Across M2 VCC/GND
C | R3 | 47 ohm 1/4 W resistor | 1 | At the controller end of the LED cable; 56 ohm if current exceeds 22 mA at 4.20 V
C | JLED | Low-power LED string | 1 | About 2.5-3 V forward and 20 mA or less in total; driven directly by PWM from D9
D | LDR1 | Light-dependent resistor | 1 | Shade it from the LEDs; must see the sky
D | R4 | 47 kohm resistor | 1 | LDR divider lower resistor (A1 to OUT-)
D | SW1 | Momentary push button (normally open) | 1 | D2 to OUT-; 60 s test
E | M3 | Wemos D1 Mini (ESP8266) | 1 | Telemetry tiers 1 and 2
E | U3 | TPS63802 3.3 V buck-boost breakout (e.g. HL802A) | 1 | VIN from VBAT_SYS; OUT to D1 3V3 in Tier 2 only
E | C2 | 470 uF electrolytic 10 V | 1 | At U3 input
E | Q2 | 2N3904 NPN transistor (or BC547-BC550) | 1 | Serial inverter and level shifter; check the E-B-C pin order of your part
E | R8 | 47 kohm resistor | 1 | Controller D1/TX to Q2 base
E | R9 | 100 kohm resistor | 1 | Q2 base to emitter (OUT-)
E | R10 | 10 kohm resistor | 1 | Q2 collector to D1 Mini 3V3; collector also to D6
E | R5 | 220 kohm resistor | 1 | VBAT_SYS to D1 Mini A0
F | - | Weatherproof enclosure with cable glands | 1 | Shaded; cells separated from heat; antenna clear of metal and cells
F | - | Perfboard or stripboard carrier | 1 | Socket every module
F | - | Female headers and screw terminals | - | Keep modules replaceable
Tools | - | USBasp programmer (or Arduino Uno/Nano as ISP) | 1 | One-time fuses and every firmware update
Tools | - | Current-limited bench supply | 1 | Controller and LED tests without a battery
Tools | - | Multimeter | 1 | Every commissioning gate

Back to top

Generated by tools/make_guide.py from docs/01–12, the drawings and the CSV files. Edit the Markdown, then regenerate. Diagrams render with Mermaid when online.

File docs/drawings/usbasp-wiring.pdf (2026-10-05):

SOLAR LIGHTS LITE / PRINTABLE SHEET

# USBasp wiring and firmware upload

Six wires. Every pin you need is on the board's top row. Nothing else connected: no FTDI, no battery, no string.

### 1 The USBasp 10-pin header, looking at the connector

### 1 MOSI

### 2 VCC

### 3 NC

### 4 GND

### 5 RST

### 6 GND

### 7 SCK

### 8 GND

### 9 MISO

### 10 GND

odd row: 1 3 5 7 9

even row: 2 4 6 8 10

Pin 1 is marked with a dot, a triangle or a square pad. On a ribbon cable it is the red stripe. Only 1, 2, 5, 7, 9 and one GND are used.

### 2 The Pro Mini top row, board the right way up, FTDI header on the left

RAW | GND | RST | VCC | A3 | A2 | A1 | A0 | 13 | 12 | 11 | 10

Coloured pins are the six you use. A4 to A7 are the unpopulated holes at the far end; ignore them.

### 3 The six connections

USBasp | Signal | Pro Mini pin | Suggested wire
Pin 1 | | MOSI | | 11 | | | green
Pin 9 | | MISO | | 12 | | | blue
Pin 7 | | SCK | | 13 | | | yellow
Pin 5 | | RESET | | RST | | | orange
Pin 2 | | VCC | | VCC | | | red
Pin 4, 6, 8 or 10 | GND | GND | black
RESET goes to RST, not to a numbered pin. MOSI and MISO are the pair people swap: 11 out, 12 back.

### 4 USBasp setup, then the commands

Set the fuses once on a new board (docs/08-firmware.md). Routine uploads never rewrite them. Use a verified 3.3 V target power and logic setting for the isolated controller.
Some clone voltage jumpers change target power but not signal level: verify the actual unit with a meter. JP2 is only for updating the USBasp's own firmware. Leave it open.
JP3, "slow SCK": fit it if the chip will not answer. Old clone firmware ignores avrdude's -B option.
Plug in the USBasp (Windows needs a libusb driver; macOS and Linux do not). Test first, this writes nothing: avrdude -c usbasp -p m328p -v
Expect: Device signature = 1E 95 0F (ATmega328P). Stop on all 00 / all ff or anything else, except:
1E 95 16 (ATmega328PB): same firmware and fuses; use -p m328pb in every command. Never use -F.
From firmware/controller, compile the advanced build with:
pio run -e advanced
Then flash with the separately installed current avrdude, not pio -t upload:

avrdude -c usbasp -p m328p -v -U flash:w:.pio/build/advanced/firmware.hex:i
For deployment use -e production and .pio/build/production/firmware.hex. Check the verify step passes.

### 5 If it will not talk

Message | | | | | | Usual cause
could not find USB device 0x16c0/0x5dc | USBasp not enumerated: cable, hub, or a dead clone
device signature = 0x000000 | No power at the target, or a loose wire. Check VCC on the board
signature reads as 0xffffff | MISO not connected, or MOSI and MISO swapped
signature 1E 95 16 (ATmega328PB) | Not a fault: use -p m328pb instead of -p m328p
initialization failed, rc=-1 | SCK too fast: fit JP3, or try -B 8
warning: cannot set sck period | Harmless on old clone firmware. Use JP3 instead
Never add fuse-write options to a routine application upload. Disconnect ISP before restoring battery power.
FULL PROCEDURE: docs/08-firmware.md | tools/make_usbasp_sheet.py

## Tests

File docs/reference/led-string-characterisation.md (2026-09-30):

# Reference LED string characterisation

This is the measurement behind the R3 value and the lighting model in
[05 – Low-power lighting](../05-build-lighting.md). Repeat it for your own
string: it takes ten minutes and tells you whether 47 Ω is right.

---

## Method

A current-limited bench supply that also measures current (a power profiler
works well) feeds the string through a single 47 Ω resistor: supply positive →
47 Ω → string positive, string negative → supply ground. Room temperature,
string out of its enclosure.

## Results

| Supply | Measured | Across 47 Ω | Implied string voltage |
| :----- | ---: | ---: | ---: |
| 3.40 V | 18 mA | 0.85 V | 2.55 V |
| 3.70 V | 24 mA | 1.13 V | 2.57 V |
| 4.20 V | 35 mA | 1.65 V | 2.55 V |

A straight line through the three points has a slope of 47 Ω (the resistor
alone) and an intercept of 2.56 V. Across the battery range the string behaves
as a fixed 2.56 V drop with no significant internal resistance:

```
I = (V − 2.56 V) / R_series
```

The model gives 17.9, 24.3 and 34.9 mA against the measured 18, 24 and 35 mA.

## From bench to circuit

On the bench the supply connects directly to the resistor. In the finished
build the current comes through the controller's D9 pin, which adds roughly
30 Ω of its own output resistance. That is why the same 47 Ω gives about
21 / 15 / 11 mA in circuit rather than 35 / 24 / 18 mA. The in-circuit figures
are a model until you measure them in Gate 1 of
[10 – Commissioning](../10-commissioning.md).

The reference string was accepted as bright enough at about 15 mA, which is
comfortably inside the pin's 20 mA working rating, so no driver transistor is
needed.

## What this does not cover

- **Temperature.** LED forward voltage falls as they warm, so current rises
  slightly on a hot night.
- **Branch sharing.** If a string is built from parallel LEDs, one shared
  resistor does not guarantee each branch its share.
- **The installed cable.** Long thin cable adds a small voltage drop.

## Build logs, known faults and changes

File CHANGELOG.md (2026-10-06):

# Changelog

Notable changes to Solar Lights Lite. For an introduction to the project, start
with [README.md](README.md).

---

## [0.6.0] 06-10-2026

Bench-tested on a second controller board (ATmega328PB) through a full
dusk-to-dawn night. Changes since the release candidate:

### Added

- `tools/make_layouts.py`: breadboard and perfboard layout drawings of the
  whole system (`docs/drawings/breadboard-layout.*`, `perfboard-layout.*`),
  placed to keep hookup wire to a minimum. Both layouts are checked against
  `docs/netlist.json` when generated; perfboard traces are routed on the
  0.1 in grid.
- Both layouts linked from guides 04 and 07 and shown in `docs/ASSEMBLY.html`
  (breadboard under Module B, perfboard under Module E).

- Guide 04 explains why the controller runs at 8 MHz: the ATmega328P speed
  versus voltage limit, why brown-out protection cannot cover 16 MHz, IDLE
  current, and the choice of internal oscillator over crystal. It also states
  that the widely sold 5 V/16 MHz Pro Mini is a suitable board. Guide 01 links
  to it.
- Guide 08 explains why the controller is flashed over ISP rather than through
  a USB-serial (FTDI) adapter and bootloader. Fuses need ISP, the factory
  16 MHz bootloader fails at 8 MHz, and ISP avoids a start-up delay, DTR
  wiring and back-feeding the battery. Guide 04 links to it.

- Controller reset banner (`advanced` and `production` builds): firmware
  version, build date and time, telemetry profile and clock setting.

- ATmega328PB support documented after a bench dry run on a new board. That
  board read signature `1E 95 16`, and the firmware ran unchanged. Guides 08
  and 04, the USBasp sheet and the controller bench sheet now accept either
  signature, use `-p m328pb` for the 328PB, and warn against `-F`.
- Guide 08 lists typical factory fuses for a 16 MHz Pro Mini (`0xFF`/`0xDA`/
  `0xFD`) and a troubleshooting row for `vdd=` reading about 5 V (supply
  set to 5 V). It also covers powering the bare controller from a USB-UART
  adapter's 3.3 V VCC pin for a quick check after flashing.
- Guide 04 has a new "Powering the board" section covering VCC, RAW and the
  serial header, with a table of the power source at each stage. Its build
  steps are reordered: headers, then fuses and flash, then a new first
  power-up check (3.3 V adapter into the header VCC; banner and `vdd` against
  a meter), then the regulator and power LED rework (checked again
  afterwards), then decoupling. The rework is now consistently required
  before Gate 0 and Gate 1. Guides 08 and 10, the controller bench sheet and
  the board map (serial-header pins, header VCC on the same rail) match.

- `docs/reference/ProMini-328PB-front.jpeg`: photo of the second tested
  board, a blue ATmega328PB Pro Mini clone. Guide 04 describes it and adds
  a test to tell its two LEDs apart (the power LED is the one that stays lit
  while the firmware runs). On this board the power LED is the red one beside
  the regulator, drawing about 1.8 mA (about 43 mAh a day). Guide 04 also
  estimates the power LED's daily drain in general.

### Changed

- Advanced ESPHome profile: "Arduino Diagnostics Fresh" now allows 180 s
  without a report, up from 90 s. An overnight v0.6 run lost 6 of 897 lines,
  each leaving a gap of about 140 s, and every lost line briefly showed the
  link as down. One lost line is now tolerated; two in a row still show it.
- Watchdog drift documented as chip-dependent, typically 10–20 % slow (12 %
  and 16 % measured), in `config.h` and guides 01 and 10.
- Gate 3 adds a lit-LDR check: with the lights on at night the LDR may rise
  only a few percent and must stay well below the light threshold. Guide 06
  adds the same check, and Gate 3 notes that an indoor bench sees room
  lights.
- Advanced ESPHome profile: the battery ADC takes 4 samples per 10 s read
  and averages the last six readings (one minute), replacing 16 samples per
  read. The 16-sample read blocked the ESPHome loop for about 66 ms and
  triggered "took a long time" warnings. The production profile is unchanged:
  it reads once per hourly wake, so a moving average would not survive deep
  sleep.
- The `advanced` build's reset output is reorganised: banner, active settings,
  then an aligned field guide, ending with `Live diagnostics`. No reset line
  starts with `fw=`, so the ESPHome profiles are unaffected.
- `tools/make_guide.py` shows a figure's "Printable PDF" link only when that
  PDF exists.
- `tools/make_guide.py` now also prefixes links to a heading in the same guide,
  so they work in `docs/ASSEMBLY.html`.

---

## [0.6.0-rc1] 30-09-2026

A restructure from a development record into a build-and-operate package. The
circuit is unchanged; the controller firmware and both D1 Mini profiles change
behaviour and must be reflashed together.

### Added

- Numbered documentation set in `docs/`: design overview, parts/tools/safety,
  one build guide per module (A–E), firmware, Home Assistant, commissioning
  gates 0–8 with final assembly (module F), operation and maintenance, and
  going further.
- Controller one-time fuse procedure for a new board (low `0xE2`, high `0xD9`,
  extended `0xFD`).
- `firmware/controller/include/config.h` holding every tuneable value,
  including a firmware version reported as `fw=` in every telemetry line.
- Three controller build environments, one per telemetry tier:
  `standalone`, `production` and `advanced`.
- `production` build: a compact status line every 8 scheduler seconds, with
  the serial port powered only while sending and TX held low in between.
- Tier 2 production telemetry reads that line during each hourly wake, using
  the same Q2 harness as Tier 1; no rewiring between tiers.
- `homeassistant/solar_lights_package.yaml`: OTA helper plus battery-low,
  cut-off and reports-stopped automations.
- `homeassistant/dashboard-production-telemetry.yaml`.
- `LICENSE`: the whole project is dedicated to the public domain under
  CC0 1.0.
- Host test for the fast-tick rule; UART parsing checked against sample lines.

### Changed

- Repository flattened: `docs/`, `firmware/`, `hardware/kicad/`,
  `homeassistant/` and `tools/` at the root.
- Scheduler simplified to dusk-to-dawn only: states are `DAY`, `NIGHT` and
  `LVC`; the output cause `ALL_NIGHT` is now `DUSK_TO_DAWN`.
- Controller: unused analog inputs A0–A5 have their digital buffers disabled;
  RX has its pull-up enabled; D8 is no longer driven.
- ESPHome: both profiles use device name `solar-lights` with identical entity
  names, an OTA password (`ota_password` secret), a new `Arduino Firmware`
  sensor, and only accept lines that start with `fw=`.
- Drawings regenerated with module and tier titles; sheet 3 now shows Tier 2
  on the shared serial harness. Files renamed under `docs/drawings/`.
- KiCad project renamed to `hardware/kicad/SolarLights_Lite.*`; title block,
  notes and the D1 Mini supply pin (now `3V3`, previously labelled `5V`)
  corrected. Connectivity is unchanged.
- Parts list, wire schedule and netlist regenerated with module and tier notes.
- `docs/ASSEMBLY.html` is now generated from guides 01–12 by
  `tools/make_guide.py`: one visual page with every drawing inline beside its
  module, plus the wire schedule and parts checklist.

### Removed

- Superseded designs, review reports, dated addenda, legacy KiCad baseline,
  archived exports, original v1 files and machine-specific tool captures.
  All remain available at tag `v0.5.5-history`.
- Unused firmware paths: panel-voltage sensing, mode jumpers and the
  evening/pre-dawn schedule.

### Upgrading an existing 0.5 installation

No wiring changes are needed and the lighting behaviour is unchanged. Upgrade
the controller first, then the D1 Mini, so telemetry is never interrupted.

1. **Back up.** Read the controller's current firmware
   (`avrdude -c usbasp -p m328p -U flash:r:solarlights-v0.5-backup.hex:i`),
   copy the D1 Mini's YAML out of ESPHome, and export the dashboard's raw
   configuration.
2. **Controller.** Build in `firmware/controller` (the old `pro8_debug` is now
   `advanced`; the old silent `pro8` is now `standalone`) and flash
   `.pio/build/advanced/firmware.hex` over ISP. Do not write fuses: an already
   converted board keeps its settings. The 0.5 D1 Mini profile still reads the
   new lines; `mode` now reports `DAY`/`NIGHT`/`LVC` and the night cause is
   `DUSK_TO_DAWN`, so update any automation that tests the old values.
3. **D1 Mini.** Install `solar-lights-advanced-telemetry.yaml` with
   `name: telemetry` and `friendly: Telemetry` in its substitutions, so the
   device keeps its network name and Home Assistant keeps its existing
   `*.telemetry_*` entity IDs. Keep the same `esphome_encryption_key`, and add
   an `ota_password` secret (the first wireless install still works because
   the running firmware has no password yet). Renaming an existing device to
   `solar-lights` is not recommended: the first wireless install would look
   for `solar-lights.local`, and Home Assistant would keep the old entity IDs
   while creating new ones, leaving a mix.
4. **Home Assistant.** The existing dashboard keeps working. To use the new
   dashboards or package, replace `solar_lights_` with `telemetry_` in them
   first (but keep `input_boolean.solar_lights_ota` as it is). If that helper
   already exists under Settings → Helpers, remove the `input_boolean:` block
   from the package.
5. **Rollback** at any point: reflash `solarlights-v0.5-backup.hex` and
   reinstall the saved YAML. The complete 0.5 source is at tag
   `v0.5.5-history`.

---

## Pre-release history (0.2 – 0.5.5)

Development between 17-Sep-2026 and 30-Sep-2026 took the design from a
parts-bin concept to the built v0.5 circuit: an engineering review of the
original design, conversion of the BTE13-010A to internal 8 MHz with ISP-only
programming, measurement of the LED string and removal of the MOSFET driver in
favour of direct pin drive through a 47 Ω resistor, a switched LDR (R4 changed
from 100 kΩ to 47 kΩ for dark margin), the TPS63802 telemetry supply, and the
always-on D1 Mini serial telemetry with its Home Assistant dashboard. The full
record – review findings, dated measurements, superseded drawings and the
original design – is preserved at tag `v0.5.5-history`.

[0.6.0]: https://github.com/anthonyjclarke/Solar-Lights-Lite/compare/v0.6.0-rc1...v0.6.0
[0.6.0-rc1]: https://github.com/anthonyjclarke/Solar-Lights-Lite/compare/v0.5.5-history...v0.6.0-rc1

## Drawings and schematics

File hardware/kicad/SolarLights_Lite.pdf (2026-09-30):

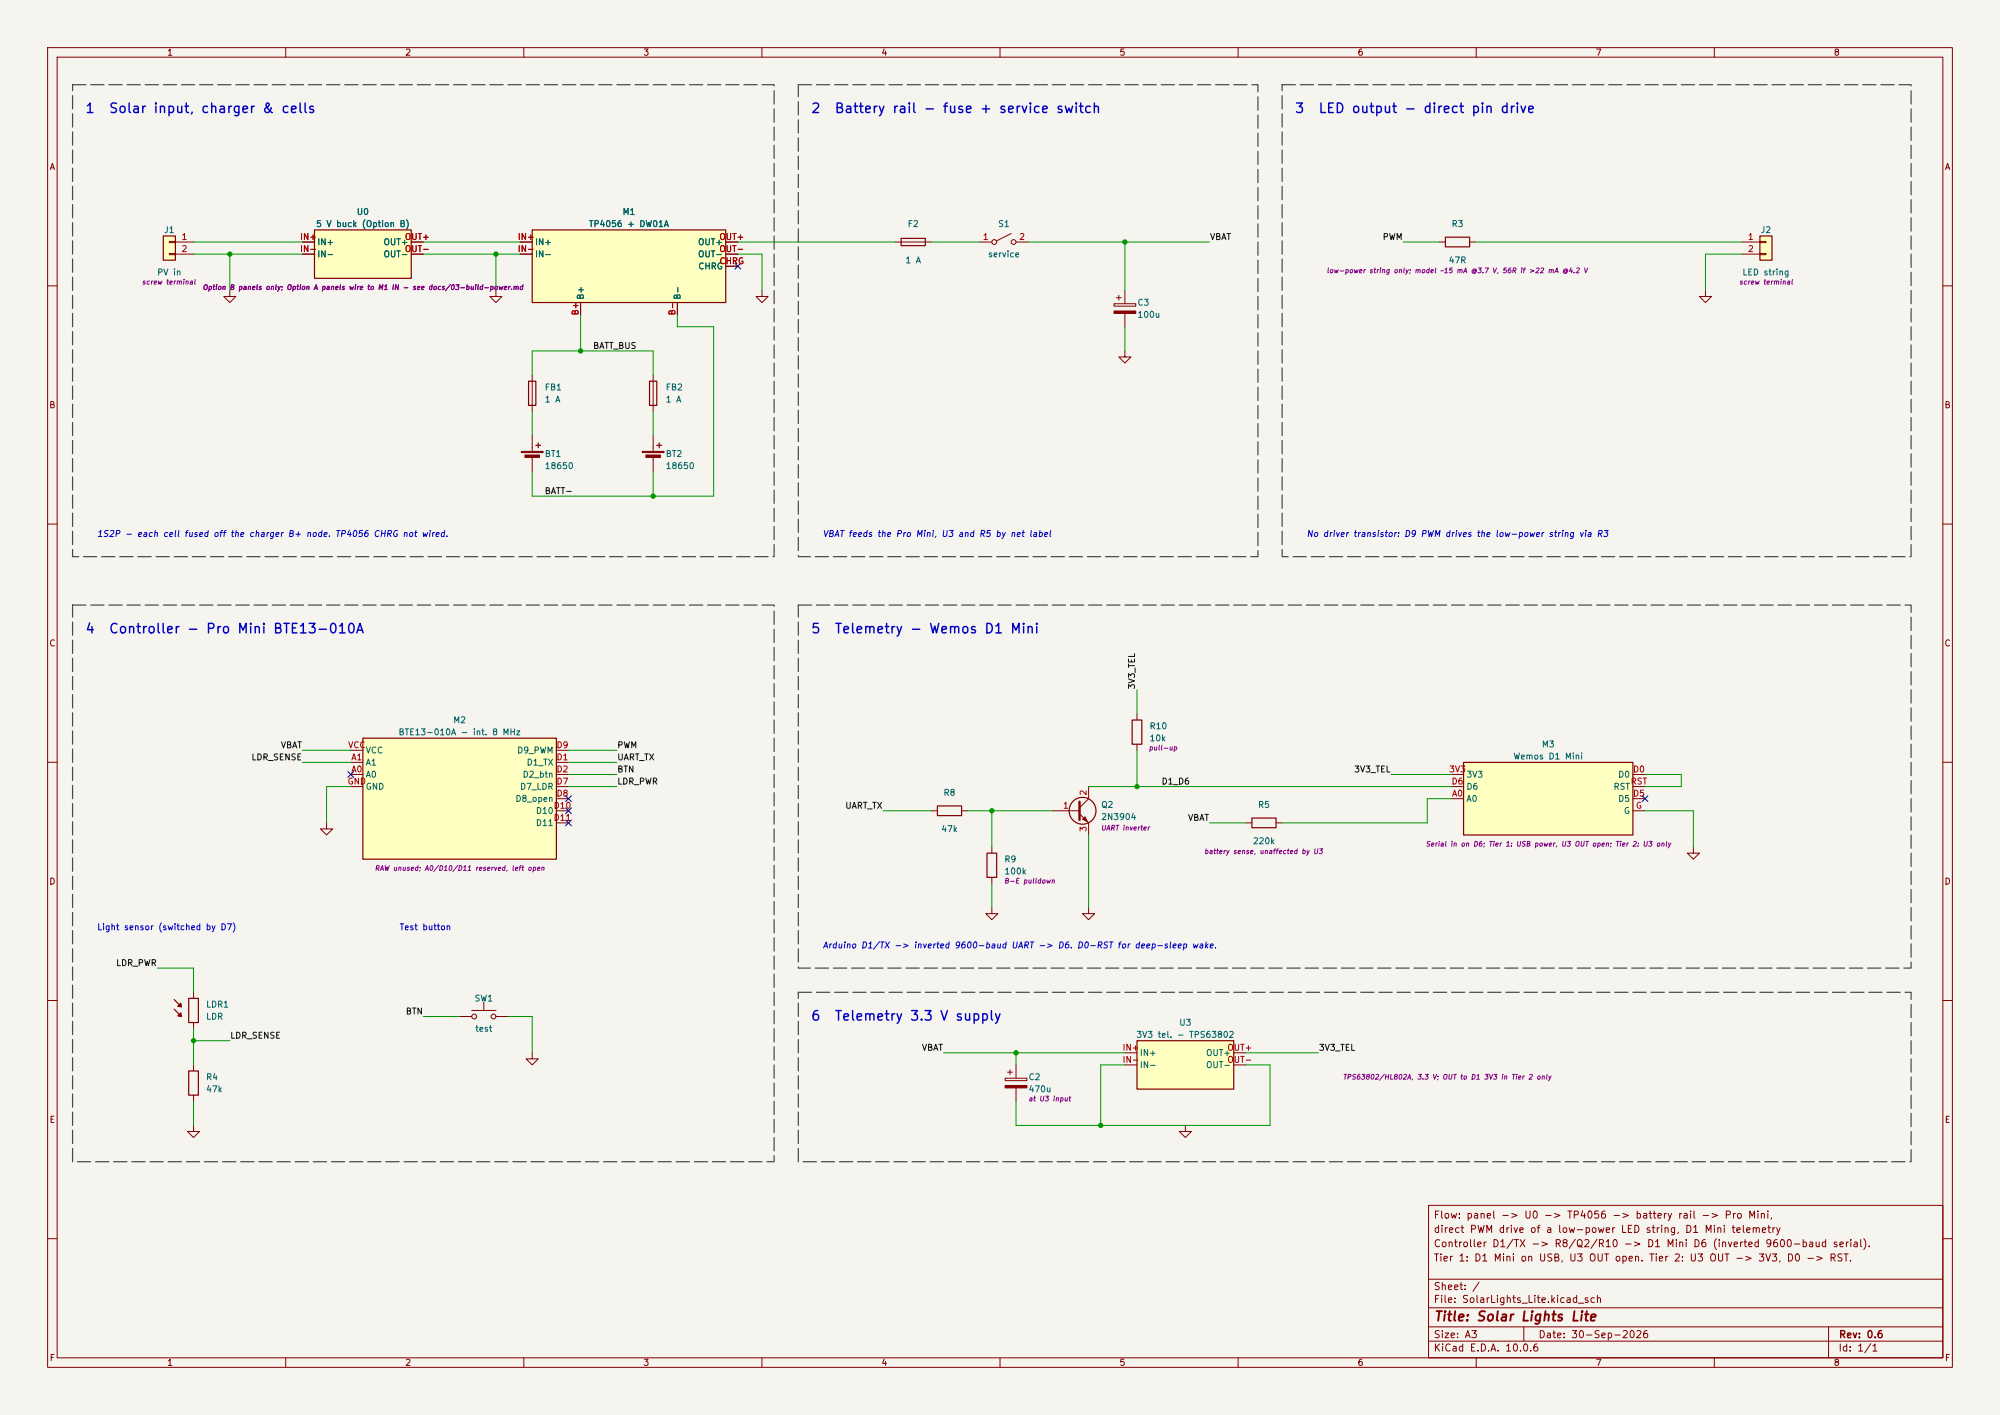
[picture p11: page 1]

5 V buck (Option B) Option B panels only; Option A panels wire to M1 IN - see docs/03-build-power.md 1

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

VBAT feeds the Pro Mini, U3 and R5 by net label Light sensor (switched by D7)

battery sense, unaffected by U3 R10

RSTRST M3 Wemos D1 Mini Serial in on D6; Tier 1: USB power, U3 OUT open; Tier 2: U3 only

Arduino D1/TX -> inverted 9600-baud UART -> D6. D0-RST for deep-sleep wake. 6 Telemetry 3.3 V supply

Flow: panel -> U0 -> TP4056 -> battery rail -> Pro Mini,
direct PWM drive of a low-power LED string, D1 Mini telemetry
Controller D1/TX -> R8/Q2/R10 -> D1 Mini D6 (inverted 9600-baud serial).
Tier 1: D1 Mini on USB, U3 OUT open. Tier 2: U3 OUT -> 3V3, D0 -> RST.

Sheet: /
File: SolarLights_Lite.kicad_sch
Title: Solar Lights Lite

Size: A3 | Rev: 0.6 | F Date: 30-Sep-2026
KiCad E.D.A. 10.0.6 | Id: 1/1

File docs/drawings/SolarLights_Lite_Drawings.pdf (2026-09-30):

# Module A: power, charging & battery

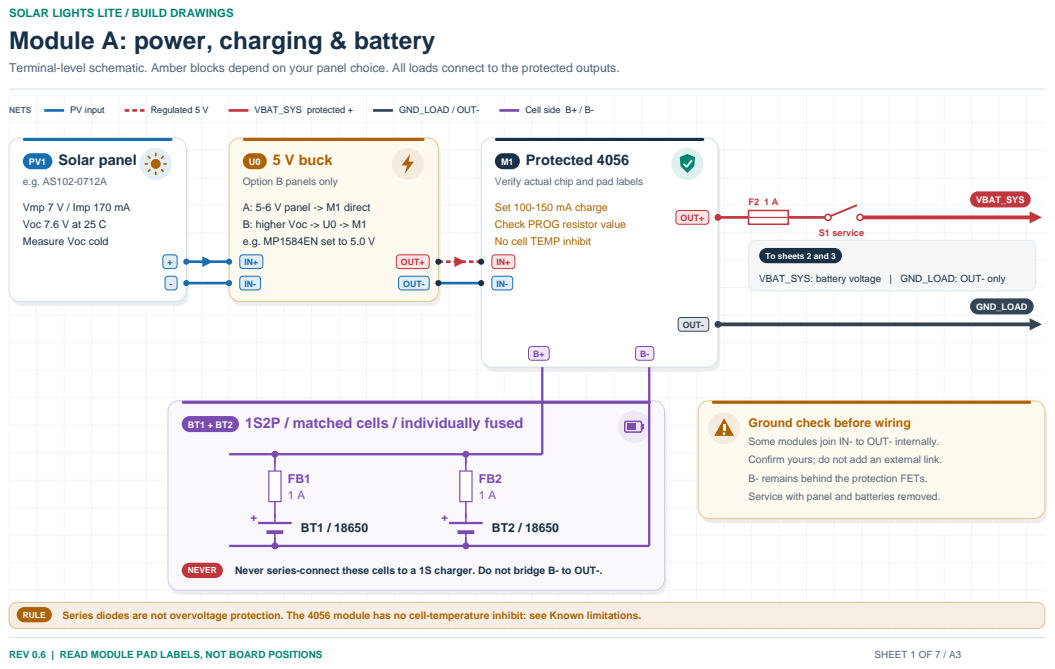
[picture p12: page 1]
REV 0.6 | READ MODULE PAD LABELS, NOT BOARD POSITIONS; SHEET 1 OF 7 / A3; NETS; PV input; Regulated 5 V; VBAT_SYS protected +; GND_LOAD / OUT-; Cell side B+ / B-; PV1 Solar panel; U0 5 V buck; A: 5-6 V panel -> M1 direct B: higher Voc -> U0 -> M1 e.g. MP1584EN set to 5.0 V; OUT+; OUT-; M1 Protected 4056; S1 service; VBAT_SYS; GND_LOAD; VBAT_SYS: battery voltage; | GND_LOAD: OUT- only; NEVER; Never series-connect these cells to a 1S charger. Do not bridge B- to OUT-.; RULE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

SOLAR LIGHTS LITE / BUILD DRAWINGS

Terminal-level schematic. Amber blocks depend on your panel choice. All loads connect to the protected outputs.

Option B panels only

Verify actual chip and pad labels

Vmp 7 V / Imp 170 mA
Voc 7.6 V at 25 C
Measure Voc cold

Set 100-150 mA charge
Check PROG resistor value
No cell TEMP inhibit

To sheets 2 and 3

BT1 + BT2 1S2P / matched cells / individually fused

Ground check before wiring
Some modules join IN- to OUT- internally.
Confirm yours; do not add an external link.
B- remains behind the protection FETs.
Service with panel and batteries removed.

# Modules B-D: controller, light sensor & low-power LEDs

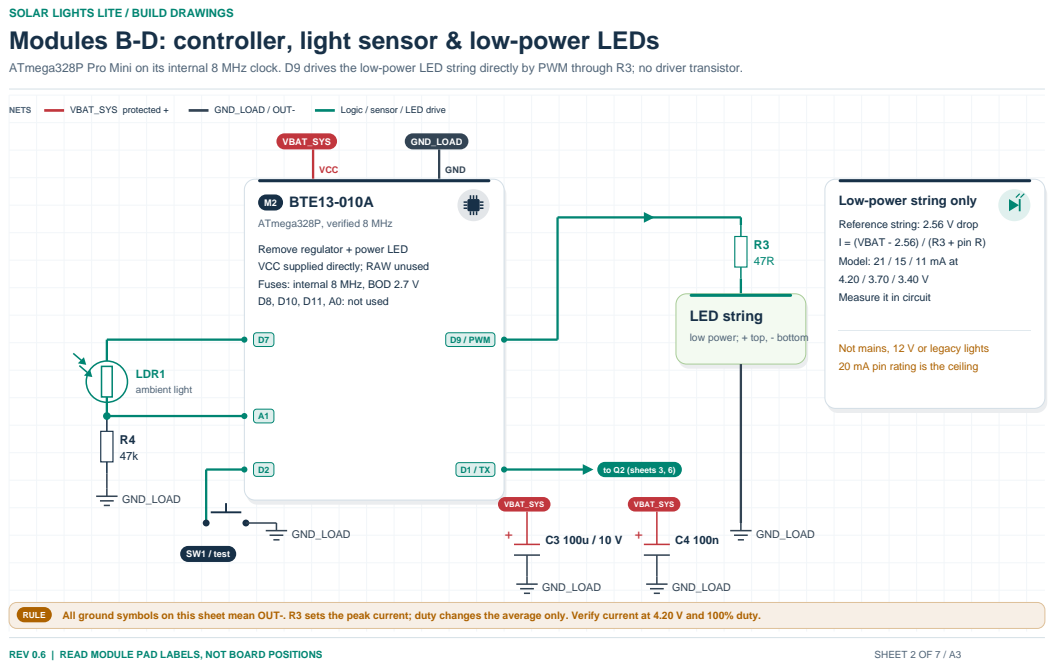
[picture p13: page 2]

SOLAR LIGHTS LITE / BUILD DRAWINGS

ATmega328P Pro Mini on its internal 8 MHz clock. D9 drives the low-power LED string directly by PWM through R3; no driver transistor.

Low-power string only

Reference string: 2.56 V drop
I = (VBAT - 2.56) / (R3 + pin R)
Model: 21 / 15 / 11 mA at
Measure it in circuit

Remove regulator + power LED
VCC supplied directly; RAW unused
Fuses: internal 8 MHz, BOD 2.7 V
D8, D10, D11, A0: not used

low power; + top, - bottom

Not mains, 12 V or legacy lights
20 mA pin rating is the ceiling

# Module E: telemetry, Tier 2 production (D1 Mini)

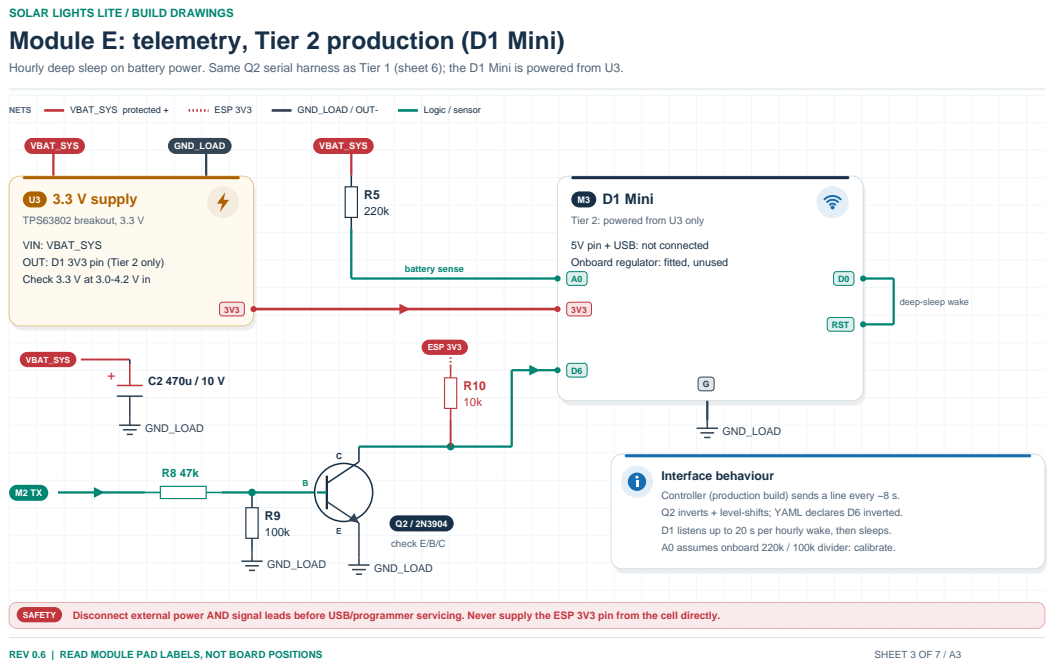
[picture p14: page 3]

SOLAR LIGHTS LITE / BUILD DRAWINGS

Hourly deep sleep on battery power. Same Q2 serial harness as Tier 1 (sheet 6); the D1 Mini is powered from U3.

Tier 2: powered from U3 only

VIN: VBAT_SYS
OUT: D1 3V3 pin (Tier 2 only)
Check 3.3 V at 3.0-4.2 V in

5V pin + USB: not connected
Onboard regulator: fitted, unused

Interface behaviour
Controller (production build) sends a line every ~8 s.
Q2 inverts + level-shifts; YAML declares D6 inverted.
D1 listens up to 20 s per hourly wake, then sleeps.
A0 assumes onboard 220k / 100k divider: calibrate.

# What to assemble inside the enclosure

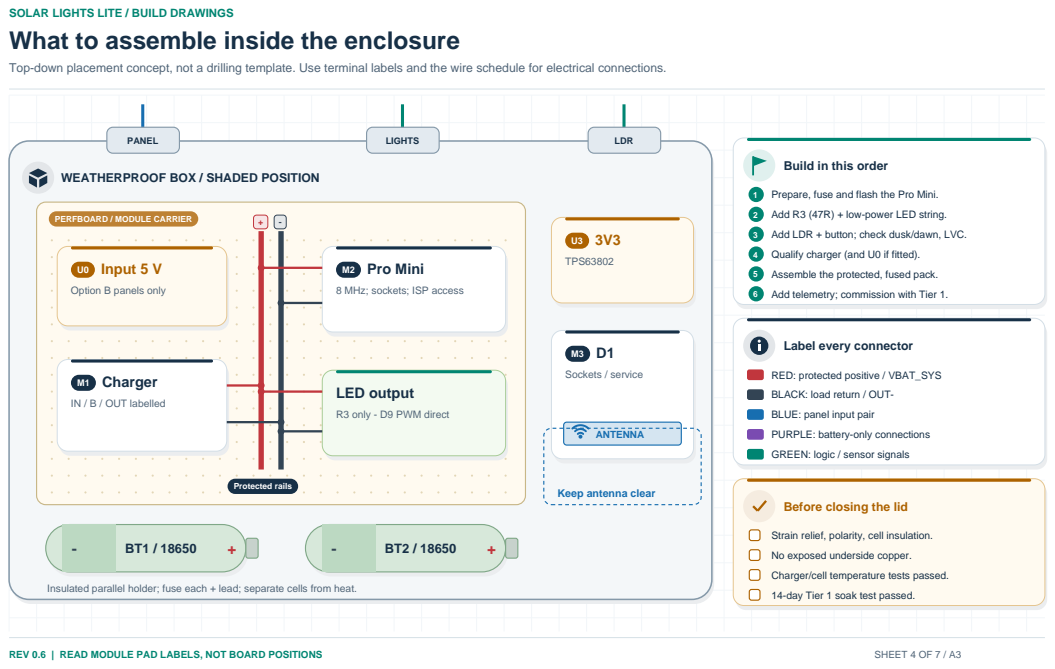
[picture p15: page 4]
REV 0.6 | READ MODULE PAD LABELS, NOT BOARD POSITIONS; SHEET 4 OF 7 / A3; PANEL; LIGHTS; LDR; Input 5 V; Charger; Pro Mini; LED output; Protected rails; TPS63802; Sockets / service; ANTENNA

SOLAR LIGHTS LITE / BUILD DRAWINGS

Top-down placement concept, not a drilling template. Use terminal labels and the wire schedule for electrical connections.

Build in this order

WEATHERPROOF BOX / SHADED POSITION

1 Prepare, fuse and flash the Pro Mini.
2 Add R3 (47R) + low-power LED string.
3 Add LDR + button; check dusk/dawn, LVC.
4 Qualify charger (and U0 if fitted).
5 Assemble the protected, fused pack.
6 Add telemetry; commission with Tier 1.

PERFBOARD / MODULE CARRIER

Option B panels only

8 MHz; sockets; ISP access

Label every connector

RED: protected positive / VBAT_SYS
BLACK: load return / OUT-
BLUE: panel input pair
PURPLE: battery-only connections
GREEN: logic / sensor signals

IN / B / OUT labelled

R3 only - D9 PWM direct

Keep antenna clear

Before closing the lid

Strain relief, polarity, cell insulation.
No exposed underside copper.
Charger/cell temperature tests passed.
14-day Tier 1 soak test passed.

Insulated parallel holder; fuse each + lead; separate cells from heat.
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

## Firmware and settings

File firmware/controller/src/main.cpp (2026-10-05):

/*
 * Solar Lights Lite – dusk-to-dawn controller for a low-power LED string
 * ---------------------------------------------------------------------
 * Target: ATmega328P (or drop-in ATmega328PB) Pro Mini-class board on its internal 8 MHz oscillator
 * (fuses L 0xE2, H 0xD9, E 0xFD: no bootloader, 2.7 V brown-out), powered
 * directly from the protected 1S Li-ion rail with the board regulator removed.
 * Firmware is flashed over ISP; see docs/08-firmware.md.
 *
 * Each watchdog wake measures the supply against the internal bandgap, briefly
 * powers the LDR divider and reads A1, advances the scheduler (schedule.h),
 * sets the D9 PWM duty and goes back to sleep.
 *
 * Lighting: D9 drives a LOW-POWER LED string directly by PWM through R3
 * (47 ohm). There is no driver transistor. R3 and the pin's own resistance set
 * the current; duty sets brightness only. The pin's 20 mA working rating is the
 * design ceiling, so this output cannot run mains, 12 V or conventional lights.
 *
 * Telemetry, selected by the TELEMETRY build flag (one PlatformIO environment each):
 *   0  standalone  no serial output; USART powered down
 *   1  production  banner at reset, then one compact line every STATUS_INTERVAL_S;
 *                  USART on only while sending
 *   2  advanced    banner and field guide at reset, then full diagnostics; USART always on
 * Lines are space-separated key=value pairs at 9600 baud on D1/TX, starting
 * with fw=. The D1 Mini receives them through the Q2 inverter, and both
 * ESPHome profiles parse the same keys: rename a key here, update both YAML files.
 */
#include <Arduino.h>
#include <avr/sleep.h>
#include <avr/wdt.h>
#include <avr/power.h>
#include <util/delay.h>
#include "config.h"
#include "schedule.h"

#ifndef TELEMETRY
#define TELEMETRY 1
#endif

struct Reading {
  float    vdd;       // controller supply, volts
  uint16_t ldrRaw;    // A1, 0..1023
  float    ldrRatio;  // A1 as a fraction of VCC
  bool     dark, light;
};

lite::Scheduler sched;
volatile bool wdtFired = false, btnPressed = false;
ISR(WDT_vect) { wdtFired = true; }
ISR(PCINT2_vect) { if (!digitalRead(PIN_BUTTON)) btnPressed = true; }

// ------------------------------------------------------------ hardware helpers
static uint8_t wdtPeriod = 0xFF;
static void wdtSet(bool fast) {
  uint8_t per = fast ? (_BV(WDP2) | _BV(WDP1)) : (_BV(WDP3) | _BV(WDP0));   // 1 s : 8 s
  if (per == wdtPeriod) return;
  wdtPeriod = per;
  cli();
  wdt_reset();
  MCUSR &= ~_BV(WDRF);
  WDTCSR = _BV(WDCE) | _BV(WDE);
  WDTCSR = _BV(WDIE) | per;                  // interrupt only, never a reset
  sei();
}

static uint16_t adcRaw(uint8_t mux) {
  ADMUX = _BV(REFS0) | mux;                  // AVcc reference
  _delay_ms(3);
  ADCSRA |= _BV(ADSC); while (bit_is_set(ADCSRA, ADSC));
  ADCSRA |= _BV(ADSC); while (bit_is_set(ADCSRA, ADSC));   // keep the settled second sample
  return ADC;
}

// VCC from the 1.1 V bandgap measured against AVcc (mux 0x0E)
static float readVcc() { uint16_t r = adcRaw(0x0E); return r ? BANDGAP_V * 1023.0f / r : 0; }

static Reading measure() {
  Reading r;
  power_adc_enable(); ADCSRA |= _BV(ADEN);
  r.vdd = readVcc();
  digitalWrite(PIN_LDR_PWR, HIGH); _delay_ms(5);   // LDR divider draws current only now
  r.ldrRaw = adcRaw(ADC_LDR);
  digitalWrite(PIN_LDR_PWR, LOW);
  ADCSRA &= ~_BV(ADEN); power_adc_disable();
  r.ldrRatio = r.ldrRaw / 1023.0f;
  r.dark = r.ldrRatio < LDR_DARK_RATIO;
  r.light = r.ldrRatio > LDR_LIGHT_RATIO;
  return r;
}

// Fixed duty, no voltage compensation: with direct drive the LED current
// already falls with the cell voltage, and that is intended.
static void setLights(uint8_t pct) {
  uint8_t duty = (uint16_t)pct * 255U / 100U;
  if (!duty) digitalWrite(PIN_LED_PWM, LOW);
  else analogWrite(PIN_LED_PWM, duty);
}

#if TELEMETRY != 2
// Hold D1/TX low between transmissions: Q2 stays off, so the link draws nothing
// and the pin never floats (the USART takes the pin over again when enabled).
static void releaseTx() { pinMode(PIN_TX, OUTPUT); digitalWrite(PIN_TX, LOW); }
#endif

// ------------------------------------------------------------ telemetry text
#if TELEMETRY
static const __FlashStringHelper* stateName(lite::State s) {
  switch (s) {
    case lite::DAY:   return F("DAY");
    case lite::NIGHT: return F("NIGHT");
    case lite::LVC:   return F("LVC");
    default:          return F("UNKNOWN");
  }
}

static const __FlashStringHelper* senseName(const Reading& r) {
  return r.dark ? F("DARK") : (r.light ? F("LIGHT") : F("MID"));
}

// Voltage bands describe firmware decisions, not a calibrated state of charge.
static uint8_t batteryBand(float vdd) {
  if (vdd < sched.cfg.lvcOffV) return 0;
  if (vdd < sched.cfg.lowBattV) return 1;
  if (vdd <= sched.cfg.lvcResumeV) return 2;
  return 3;
}
static const __FlashStringHelper* batteryName(uint8_t band) {
  switch (band) {
    case 0:  return F("CRITICAL");
    case 1:  return F("LOW");
    case 2:  return F("MID");
    default: return F("OK");
  }
}

static const __FlashStringHelper* outputCause(float vdd, uint8_t pct) {
  if (sched.state == lite::LVC) return F("LVC_OFF");
  bool startup = sched.t < sched.cfg.selfTestS;
  bool button = sched.buttonActive();
  if ((startup || button) && vdd < sched.cfg.lvcOffV) return F("LOW_VOLT_BLOCK");
  if (startup) return F("STARTUP_TEST");
  if (button) return F("BUTTON_TEST");
  if (sched.state == lite::DAY) return pct ? F("FADE_TO_DAY_OFF") : F("DAY_OFF");
  return vdd < sched.cfg.lowBattV ? F("LOW_BATT_NIGHT") : F("DUSK_TO_DAWN");
}

// One telemetry line. Production sends the core keys; advanced adds progress detail.
static void printLine(bool full, const Reading& r, uint8_t pct, bool fast) {
  Serial.print(F("fw=")); Serial.print(FW_VERSION);
  Serial.print(F(" time=")); Serial.print(sched.t); Serial.print(F("s"));
  Serial.print(F(" vdd=")); Serial.print(r.vdd, 3); Serial.print(F("V"));
  Serial.print(F(" battery=")); Serial.print(batteryName(batteryBand(r.vdd)));
  Serial.print(F(" ldr=")); Serial.print(r.ldrRatio * 100.0f, 1); Serial.print(F("%"));
  Serial.print(F(" sense=")); Serial.print(senseName(r));
  Serial.print(F(" mode=")); Serial.print(stateName(sched.state));
  Serial.print(F(" night=")); Serial.print(sched.night ? F("YES") : F("NO"));
  Serial.print(F(" output=")); Serial.print(pct); Serial.print(F("%"));
  Serial.print(F(" cause=")); Serial.print(outputCause(r.vdd, pct));
  if (full) {
    Serial.print(F(" raw=")); Serial.print(r.ldrRaw);
    Serial.print(F(" ldr_v=")); Serial.print(r.ldrRatio * r.vdd, 3); Serial.print(F("V"));
    Serial.print(F(" confirm="));
    if (sched.confirm) {
      Serial.print(sched.night ? F("DAWN") : F("DUSK"));
      Serial.print(F(" ")); Serial.print(sched.confirm); Serial.print(F("/"));
      Serial.print(sched.cfg.confirmS); Serial.print(F("s"));
    } else Serial.print(F("NONE"));
    Serial.print(F(" lvc=")); Serial.print(sched.lvcCount); Serial.print(F("/"));
    Serial.print(sched.cfg.lvcHoldS); Serial.print(F("s"));
    Serial.print(F(" button="));
    Serial.print(sched.buttonActive() ? sched.buttonUntil - sched.t : 0); Serial.print(F("s"));
    Serial.print(F(" next_tick=")); Serial.print(fast ? 1 : 8); Serial.print(F("s"));
  }
  Serial.println();
}
#endif

#if TELEMETRY
// __DATE__ is "Mmm dd yyyy" with a space-padded day; printed as dd-Mmm-yyyy hh:mm.
static void printBuildStamp() {
  const char* d = __DATE__;
  Serial.print(d[4] == ' ' ? '0' : d[4]); Serial.print(d[5]); Serial.print('-');
  Serial.write(d, 3); Serial.print('-'); Serial.write(d + 7, 4);
  Serial.print(' '); Serial.write(__TIME__, 5);
}

// Reset banner. No line starts with fw=, so both ESPHome profiles ignore it.
static void printBanner() {
  Serial.println();
  Serial.println(F("=================================================="));
  Serial.println(F(" Solar Lights Lite  -  dusk-to-dawn controller"));
  Serial.print(F(" Firmware   v")); Serial.print(FW_VERSION);
  Serial.print(F("   built ")); printBuildStamp(); Serial.println();
#if TELEMETRY == 2
  Serial.println(F(" Telemetry  advanced: full diagnostics, 9600 baud"));
#else
  Serial.println(F(" Telemetry  production: compact line, 9600 baud"));
#endif
  Serial.println(F(" Clock      internal 8 MHz, brown-out 2.7 V"));
  Serial.println(F("=================================================="));
}
#endif

#if TELEMETRY == 2
static void printFieldGuide() {
  Serial.println(F("Settings"));
  Serial.print(F("  LDR        dark <")); Serial.print(LDR_DARK_RATIO * 100.0f, 0);
  Serial.print(F("%  light >")); Serial.print(LDR_LIGHT_RATIO * 100.0f, 0);
  Serial.print(F("%  confirm ")); Serial.print(TRANSITION_CONFIRM_S); Serial.println(F(" s"));
  Serial.print(F("  Battery    low <")); Serial.print(LOW_BATT_V, 2);
  Serial.println(F(" V halves night duty"));
  Serial.print(F("             cut-off <")); Serial.print(LVC_OFF_V, 2);
  Serial.print(F(" V for ")); Serial.print(LVC_HOLD_S);
  Serial.print(F(" s, resume >")); Serial.print(LVC_RESUME_V, 2); Serial.println(F(" V in daylight"));
  Serial.print(F("  Duty       night ")); Serial.print(NIGHT_DUTY_PCT);
  Serial.print(F("%  button test ")); Serial.print(BUTTON_TEST_S); Serial.println(F(" s"));
  Serial.println(F("Field guide (keys in each line)"));
  Serial.println(F("  time       scheduler seconds since reset (watchdog clock, not wall-clock)"));
  Serial.println(F("  vdd        controller supply; battery = OK/MID/LOW/CRITICAL band"));
  Serial.println(F("  ldr        A1 as % of VCC; raw = ADC 0-1023; ldr_v = A1 volts"));
  Serial.println(F("  sense      DARK / MID / LIGHT from the LDR thresholds above"));
  Serial.println(F("  mode       DAY / NIGHT / LVC; night = YES after a confirmed dusk"));
  Serial.println(F("  output     D9 PWM duty; cause = why output has that value"));
  Serial.println(F("  confirm    DUSK or DAWN progress, NONE when idle"));
  Serial.println(F("  lvc        seconds below cut-off; button = test seconds left"));
  Serial.println(F("  next_tick  1 s while active, 8 s when idle"));
  Serial.println(F("--------------------------------------------------"));
  Serial.println(F("Live diagnostics"));
}
#endif

// Advanced: report events immediately, progress every ADVANCED_ACTIVE_REPORT_S,
// fades at 10-point steps and a heartbeat every ADVANCED_IDLE_REPORT_S.
// Production: one compact line every STATUS_INTERVAL_S. Standalone: nothing.
static void report(const Reading& r, uint8_t pct, bool fast) {
#if TELEMETRY == 1
  static bool first = true;
  static uint32_t last = 0;
  if (!first && (uint32_t)(sched.t - last) < STATUS_INTERVAL_S) return;
  first = false; last = sched.t;
  power_usart0_enable();
  Serial.begin(9600);
  printLine(false, r, pct, fast);
  Serial.flush();
  Serial.end();
  power_usart0_disable();
  releaseTx();
#elif TELEMETRY == 2
  static bool first = true;
  static uint32_t last = 0;
  static uint8_t lastState = 0xFF, lastSense = 0xFF, lastBand = 0xFF, lastPct = 0;
  static bool lastNight = false, lastButton = false;
  uint8_t sense = r.dark ? 0 : (r.light ? 2 : 1);
  uint8_t band = batteryBand(r.vdd);
  bool button = sched.buttonActive();
  bool progress = sched.confirm > 0 || sched.lvcCount > 0 || button;
  uint32_t period = progress ? ADVANCED_ACTIVE_REPORT_S : ADVANCED_IDLE_REPORT_S;
  uint8_t pctDelta = pct > lastPct ? pct - lastPct : lastPct - pct;
  bool event = first || sched.state != lastState || sense != lastSense || band != lastBand ||
               sched.night != lastNight || button != lastButton || (pct > 0) != (lastPct > 0);
  bool heartbeat = (uint32_t)(sched.t - last) >= period;
  if (!event && pctDelta < 10 && !heartbeat) return;
  printLine(true, r, pct, fast);
  Serial.flush();
  first = false; last = sched.t; lastState = sched.state; lastSense = sense;
  lastBand = band; lastPct = pct; lastNight = sched.night; lastButton = button;
#else
  (void)r; (void)pct; (void)fast;
#endif
}

// ------------------------------------------------------------ setup
static void initPins() {
  // Unused digital pins are driven low so nothing floats during sleep.
  for (uint8_t p = 3; p <= 13; p++) { pinMode(p, OUTPUT); digitalWrite(p, LOW); }
  pinMode(0, INPUT_PULLUP);                  // RX is never used
  pinMode(PIN_BUTTON, INPUT_PULLUP);         // ~0 uA while the button is open
  PCICR |= _BV(PCIE2); PCMSK2 |= _BV(PCINT18);   // D2 wakes the controller
  DIDR0 = 0x3F;                              // no digital input buffers on A0-A5
}

static void initPower() {
  TCCR1B = (TCCR1B & 0xF8) | 0x02;           // Timer1 /8 -> D9 PWM ~1.96 kHz
  TIMSK0 &= ~_BV(TOIE0);                     // stop the millis() tick; keeps idle current low
  power_twi_disable(); power_spi_disable(); power_timer2_disable();
}

static void initTelemetry() {
#if TELEMETRY == 2
  Serial.begin(9600);
  printBanner();
  printFieldGuide();
#elif TELEMETRY == 1
  Serial.begin(9600);
  printBanner();
  Serial.flush();
  Serial.end();
  power_usart0_disable();
  releaseTx();
#else
  power_usart0_disable();
  releaseTx();
#endif
}

void setup() {
  initPins();
  initPower();
  initTelemetry();
  wdtSet(true);
}

// ------------------------------------------------------------ loop
// Sleep until the watchdog or the button; returns the scheduler seconds elapsed.
static uint32_t sleepUntilWake(bool fast, bool lit) {
  wdtSet(fast);
  wdtFired = false;
  set_sleep_mode(lit ? SLEEP_MODE_IDLE : SLEEP_MODE_PWR_DOWN);   // Timer1 PWM needs IDLE
  cli();
  if (!wdtFired && !btnPressed) {
    sleep_enable();
    if (!lit) sleep_bod_disable();
    sei();
    sleep_cpu();
    sleep_disable();
  }
  sei();
  if (btnPressed && !wdtFired) return 1;     // approximate: the button woke us early
  return fast ? 1 : 8;
}

void loop() {
  static uint32_t dt = 1;
  Reading r = measure();
  if (btnPressed) { btnPressed = false; sched.button(); }
  uint8_t pct = sched.step(dt * TIME_SCALE, r.vdd, r.dark, r.light);
  setLights(pct);
  bool fast = sched.needFastTick();
  report(r, pct, fast);
  dt = sleepUntilWake(fast, pct > 0);
}

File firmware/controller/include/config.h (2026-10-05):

/*
 * Solar Lights Lite – controller settings
 * ---------------------------------------
 * Every user-tuneable value lives here. The file is hardware-independent, so
 * it is shared by the firmware and by the host regression tests in test_host/.
 */
#pragma once
#include <stdint.h>

// Printed as fw= in every telemetry line and shown in Home Assistant.
constexpr char FW_VERSION[] = "0.6.0";

// ------------------------------------------------------------ pins
constexpr uint8_t PIN_LED_PWM = 9;  // D9 / OC1A -> R3 47 ohm -> low-power LED string +
constexpr uint8_t PIN_LDR_PWR = 7;  // D7 powers the LDR divider only while sampling
constexpr uint8_t ADC_LDR     = 1;  // A1: LDR / R4 midpoint (ADC channel number)
constexpr uint8_t PIN_BUTTON  = 2;  // D2: test button to GND, internal pull-up
constexpr uint8_t PIN_TX      = 1;  // D1/TX: telemetry to the D1 Mini through Q2

// ------------------------------------------------------------ lighting
// Dusk-to-dawn PWM duty. R3 and the pin set the LED current; duty only sets
// brightness. Lower it to trade brightness for run time.
constexpr uint8_t  NIGHT_DUTY_PCT   = 100;
constexpr uint8_t  STARTUP_TEST_PCT = 60;   // brief flash after reset; capped at night duty
constexpr uint16_t STARTUP_TEST_S   = 10;
constexpr uint8_t  BUTTON_TEST_PCT  = 100;  // D2 press; capped at night duty
constexpr uint16_t BUTTON_TEST_S    = 60;
constexpr uint8_t  FADE_STEP_PCT    = 2;    // % per second at dusk and dawn

// ------------------------------------------------------------ light sensor
// A1 as a fraction of VCC with R4 = 47k. Dark below ~0.30 means the LDR is
// above ~110k; light above ~0.60 means it is below ~31k. The gap between the
// two thresholds prevents flicker. Calibrate in the final mounting position.
constexpr float    LDR_DARK_RATIO       = 0.30f;
constexpr float    LDR_LIGHT_RATIO      = 0.60f;
constexpr uint16_t TRANSITION_CONFIRM_S = 300;  // dark or light must persist this long

// ------------------------------------------------------------ battery protection
constexpr float    LOW_BATT_V   = 3.45f;  // below: night duty is halved
constexpr float    LVC_OFF_V    = 3.30f;  // below for LVC_HOLD_S: lights off (low-voltage cut-off)
constexpr uint16_t LVC_HOLD_S   = 30;
constexpr float    LVC_RESUME_V = 3.60f;  // cut-off clears above this, in confirmed daylight

// ------------------------------------------------------------ calibration
// Internal bandgap used to measure VCC. Calibrate once against a meter:
// BANDGAP_V = 1.10 * Vmeter / Vreported.
constexpr float BANDGAP_V = 1.10f;

// ------------------------------------------------------------ timing
// The watchdog oscillator is uncalibrated and varies by chip: a scheduler
// "second" is typically 10-20% longer than a real one (12% and 16% measured).
// Dusk-to-dawn operation does not depend on wall-clock time.
constexpr uint16_t TIME_SCALE = 1;  // bench only: 60 makes each real second count as a minute

// Telemetry cadence, in scheduler seconds.
constexpr uint16_t STATUS_INTERVAL_S        = 8;   // production: one compact line
constexpr uint16_t ADVANCED_ACTIVE_REPORT_S = 10;  // advanced: while confirming, testing or in cut-off timing
constexpr uint16_t ADVANCED_IDLE_REPORT_S   = 60;  // advanced: stable-state heartbeat

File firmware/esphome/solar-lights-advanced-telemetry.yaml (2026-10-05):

# Solar Lights Lite – Tier 1: Advanced Telemetry (always-on Wemos D1 Mini)
#
# The commissioning instrument. The D1 Mini stays awake and decodes every
# diagnostic line from the controller's `advanced` firmware build into Home
# Assistant, so you can build, calibrate and soak-test the system without a USB
# cable on the controller. It is deliberately NOT part of the battery budget:
# in this tier the D1 Mini is powered from its own micro-USB, with U3 OUT
# disconnected from its 3V3 pin (never connect both).
#
# Wiring (same harness as Tier 2): controller D1/TX -> R8 47k -> Q2 2N3904 base;
# R9 100k base to OUT-; emitter to OUT-; collector -> D1 Mini D6 with R10 10k to
# 3V3. Q2 inverts and level-shifts the 9600-baud serial, hence `inverted: true`.
# D1 Mini TX is never connected to the controller. Battery sense: VBAT_SYS ->
# R5 220k -> A0. Common ground: D1 Mini G to OUT- (never B-).
#
# Device name: entity IDs are `*.solar_lights_*` and match
# homeassistant/dashboard-advanced-telemetry.yaml. Keep the same name and
# encryption key in the Tier 2 profile so Home Assistant history carries over.
#
# Required secrets: wifi_ssid, wifi_password, esphome_encryption_key,
# ota_password, ap_password. See docs/09-home-assistant.md.

substitutions:
  name: solar-lights
  friendly: Solar Lights

esphome:
  name: ${name}
  friendly_name: ${friendly}
  min_version: 2024.11.0

esp8266:
  board: d1_mini

logger:
  level: WARN

debug:
  update_interval: 30s     # feeds the reset-reason and heap sensors

wifi:
  ssid: !secret wifi_ssid
  password: !secret wifi_password
  fast_connect: true
  power_save_mode: none
  reboot_timeout: 0s       # keep capturing controller data while Wi-Fi is down
  ap:
    ssid: "${name}-fallback"
    password: !secret ap_password

captive_portal:

web_server:
  port: 80

api:
  encryption:
    key: !secret esphome_encryption_key
  reboot_timeout: 0s       # keep capturing controller data while Home Assistant is down

ota:
  - platform: esphome
    password: !secret ota_password

globals:
  - id: last_arduino_report_ms
    type: uint32_t
    restore_value: no
    initial_value: '0'

uart:
  id: arduino_diagnostics
  # ESP8266 software UART is ample for the controller's rate-limited 9600-baud lines.
  rx_pin:
    number: D6
    inverted: true
  baud_rate: 9600
  rx_buffer_size: 512
  debug:
    direction: RX
    dummy_receiver: true
    after:
      bytes: 256           # a full advanced line is ~200 characters
      timeout: 500ms
      delimiter: "\n"
    sequence:
      - lambda: |-
          // Trim control/idle bytes from both ends (the link idles in a break
          // state between production lines), then reject anything corrupted:
          // non-printable text makes Home Assistant drop the API connection.
          std::string line(bytes.begin(), bytes.end());
          auto printable = [](unsigned char c) { return c >= 0x20 && c <= 0x7E; };
          while (!line.empty() && !printable(line.front())) line.erase(0, 1);
          while (!line.empty() && !printable(line.back())) line.pop_back();
          if (line.empty()) return;
          for (unsigned char c : line) {
            if (!printable(c)) {
              ESP_LOGW("arduino", "Dropped corrupted UART line (%u bytes)", (unsigned) line.size());
              return;
            }
          }
          // Every telemetry line starts with fw=; the reset field guide does not.
          if (line.rfind("fw=", 0) != 0) return;
          id(last_arduino_report_ms) = millis();
          id(arduino_diagnostic_line).publish_state(line.c_str());

          auto number_of = [&](const char *key, float *result) -> bool {
            const std::string needle = " " + std::string(key) + "=";
            const size_t position = (" " + line).find(needle);
            if (position == std::string::npos) return false;
            const char *start = line.c_str() + position + needle.size() - 1;
            char *end = nullptr;
            const float value = strtof(start, &end);
            if (end == start) return false;
            *result = value;
            return true;
          };
          auto word_of = [&](const char *key) -> std::string {
            const std::string needle = " " + std::string(key) + "=";
            const size_t position = (" " + line).find(needle);
            if (position == std::string::npos) return "";
            const size_t start = position + needle.size() - 1;
            const size_t end = line.find(' ', start);
            return line.substr(start, end == std::string::npos ? std::string::npos : end - start);
          };
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

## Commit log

2026-09-26 chore: publish Solar Lights Lite rev 0.4
    [SolarLights_Lite.kicad_sch, SolarLights_Lite_Current.kicad_sch, SolarLights_Lite_Parts_List.csv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]
2026-09-27 Release v0.5 development telemetry
    [SolarLights_Lite_Parts_List.csv, wire-schedule.csv]
2026-09-28 Refine v0.5 live project documentation
    [SolarLights_Lite_Current.kicad_sch]
2026-09-28 Rework v0.5 schematic layout and documentation
    [SolarLights_Lite.kicad_sch, SolarLights_Lite_Current.kicad_sch, SolarLights_Lite_Wiring.kicad_sch]
2026-09-29 docs(drawings): restyle A3 sheets 1-7 and sync assembly guide
2026-09-29 feat(esphome): merge working telemetry profile and dashboard
    Rename dev D1 device to telemetry, add debug/web_server/fallback AP,
    fix split and corrupted UART lines, replace bench dashboard, and
    document the ESPHome setup steps.
2026-09-29 docs(hardware): record as-built v0.5 wiring, R4 47k and bench power
    - Treat the whole v0.5 circuit as built; the switched LDR is wired.
    - R4 changed 100k -> 47k: at 100k the 30% dark threshold needed LDR > ~233k,
    so a dim-but-not-dark bench never confirmed dusk. Covered LDR now reads 9.1%.
    - U0 marked as an open item (not fitted; bench uses a 5 V panel direct to M1).
    - U3 TPS63802 at 3.3 V on VBAT_SYS; bench D1 runs on micro-USB with U3 OUT
    disconnected, production D1 runs from U3 only.
    - Record ~12% slow WDT scheduler clock.
    - Regenerate drawing sheets, assembly guide, A3 PDF and KiCad schematic/PDF.
    - main.cpp: LDR_DARK comment only; firmware output unchanged.
    [SolarLights_Lite_Current.kicad_sch, SolarLights_Lite_Parts_List.csv]
2026-09-30 docs(release): restructure into v0.6.0 build-and-operate package
    Reorganise the project from a development record into a modular build,
    commission and operate guide. The circuit is unchanged; controller firmware
    and both D1 Mini profiles must be reflashed together (untested on hardware).
    - Flatten the repository into docs/, firmware/, hardware/kicad/,
    homeassistant/ and tools/; history preserved at tag v0.5.5-history
    - Add numbered guides 01-12 (modules A-F, telemetry tiers 0-2, gates 0-8)
    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
    [SolarLights_Lite.kicad_sch, SolarLights_Lite_Current.kicad_sch, SolarLights_Lite_Parts_List.csv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]
2026-09-30 docs(layouts): add breadboard and perfboard layout drawings
    tools/make_layouts.py draws the whole system on a breadboard and on a
    perfboard carrier, checks both against docs/netlist.json and routes the
    perfboard traces. Linked from guides 04 and 07 and shown in ASSEMBLY.html.
2026-10-04 docs(controller): explain 8 MHz clock and 16 MHz board use
    Add speed-grade, brown-out, power and oscillator rationale to guide 04,
    note that 5 V/16 MHz Pro Minis are suitable, and fix same-page anchor
    links in make_guide.py.
2026-10-05 feat(controller): add reset banner with version and build date
    Print a banner (firmware version, build date/time, telemetry profile,
    clock) at reset in advanced and production builds, and tidy the advanced
    field guide into settings and aligned key columns. Document why the
    controller is flashed over ISP rather than a USB-serial bootloader.
    [main.cpp]
2026-10-05 docs(commissioning): fold in v0.6 bench dry run and overnight results
    - ATmega328PB support: accept signature 1E 95 16, use -p m328pb, never -F
    - Guide 04: powering section (VCC, RAW, serial header), reordered build
    steps with a first power-up check before regulator rework
    - Board map, bench and USBasp sheets regenerated to match
    - Advanced ESPHome profile: 4-sample ADC with moving average; freshness
    timeout 180 s to tolerate one lost line
    - Watchdog drift documented as chip-dependent (10-20 %)
    - Gate 3 and guide 06: lit-LDR feedback check and indoor-bench note
    [config.h, main.cpp, solar-lights-advanced-telemetry.yaml]
2026-10-06 docs(controller): document second tested board (blue ATmega328PB Pro Mini)
    Add reference photo, identify its power LED (red, beside the regulator,
    1 kOhm), add the lit-LED test for telling the power LED from the D13 LED,
    and estimate the power LED's daily drain.
2026-10-06 chore(release): v0.6.0
    Finalise CHANGELOG (0.6.0 dated 06-10-2026, release candidate as
    0.6.0-rc1) and list the deferred regulator and power-LED removal as a
    remaining pre-1.0 step.

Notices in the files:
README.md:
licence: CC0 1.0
